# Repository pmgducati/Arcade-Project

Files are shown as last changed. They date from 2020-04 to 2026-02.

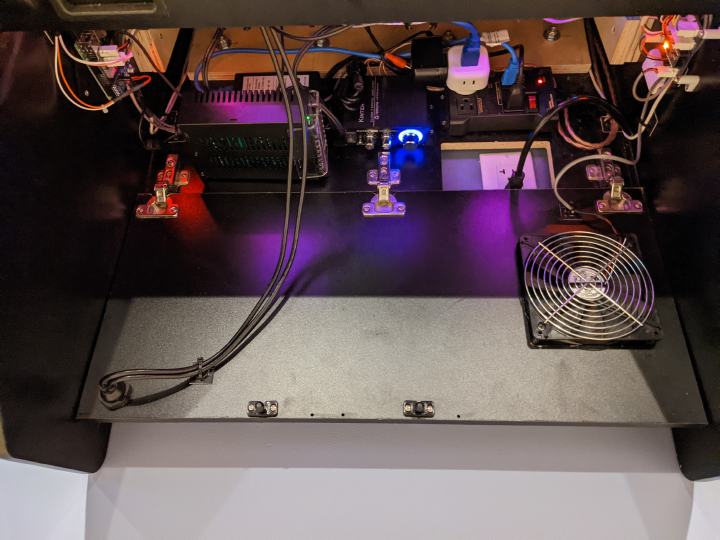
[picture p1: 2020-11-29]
Arcade Images/Access Door and Components.png

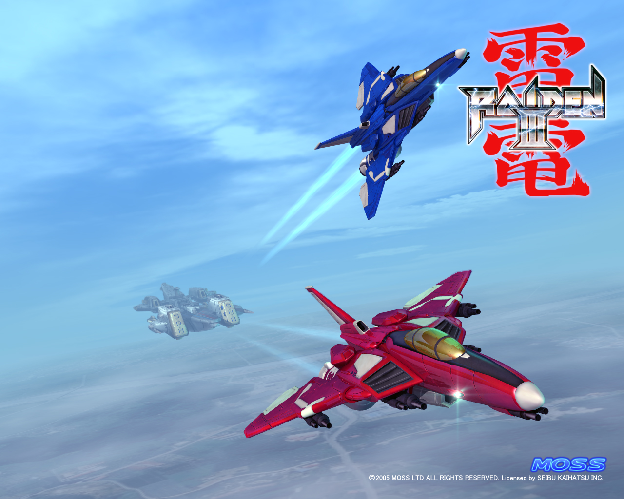
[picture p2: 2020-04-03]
Art for Inspiration/95.jpg

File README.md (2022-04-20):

# Arcade-Project
Building my Own Arcade

I have been working on some variation of an arcade cabinet that for some reason or another that never came to be... Until now!

I designed the cabinet in Solidworks and the PCBs in Eagle, I have included cultists, detailed drawings, BOM’s for purchased parts, datasheets, and pretty much any other info you would need to make the cabinet.  

I also generated STLs and Gerbers for anyone that doesn't have access to them fancy CAD programs.

Shout out to my friends Rob and Rufino for helping me out with the Artwork and CNC/wood working!



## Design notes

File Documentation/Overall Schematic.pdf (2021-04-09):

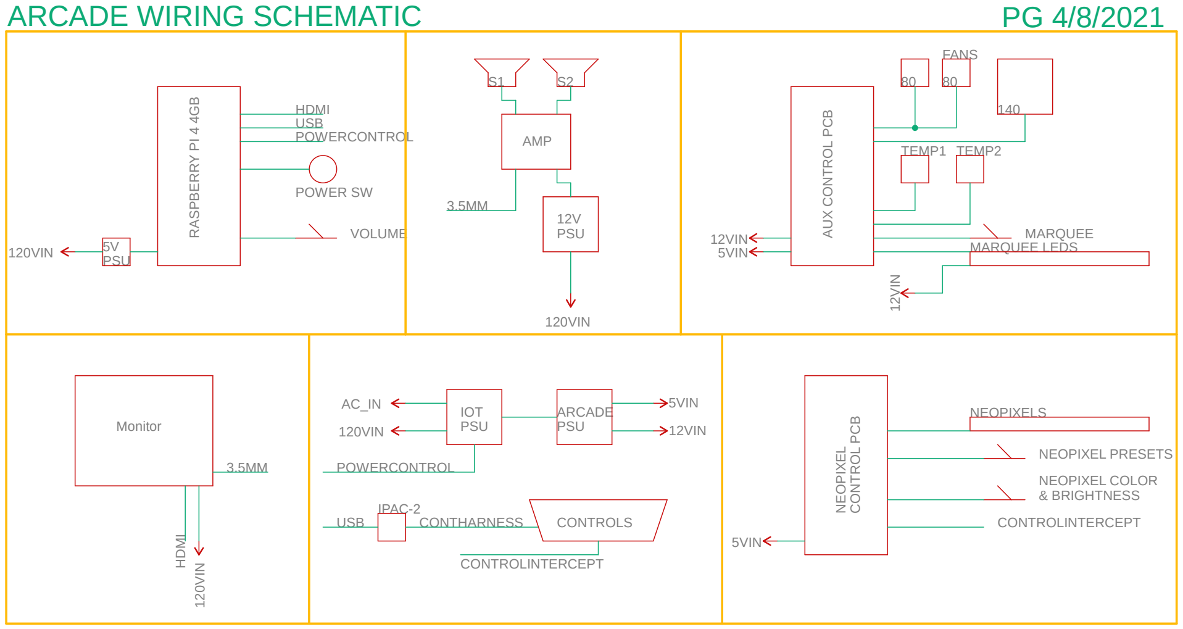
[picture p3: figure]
12VIN; 12VIN 5VIN; 5VIN; 120VIN; 120VIN 120VIN; Monitor; AMP; IOT; PSU RASPBERRY PI 4 4GB; NEOPIXEL COLOR & BRIGHTNESS; NEOPIXEL PRESETS; VOLUME; CONTROLS; IPAC-2; NEOPIXELS; POWER SW; 12V PSU; ARCADE PSU; TEMP1 TEMP2; FANS AUX CONTROL PCB; MARQUEE; MARQUEE LEDS NEOPIXEL CONTROL PCB; 5V PSU; POWERCONTROL; USB; CONTHARNESS; USB HDMI; HDMI; CONTROLINTERCEPT; ARCADE WIRING SCHEMATIC

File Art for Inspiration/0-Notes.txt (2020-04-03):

Observations:
-I like Konami Box Art (9,64-66,80-83)
-There is something cool about the 80's movie poster layout (1,2,12,50,51,106)
-Character "pile up" (19-21,45-46,89,98,99)
-8-bit/16-bit Pixel art always grabs me (18,23-24,27-29,32,43,85,88,90,96,97,100,101,103,104)
-Im a big fan of Ms Pacman :) (13)
-Iconic Art (To Me) (4-7, 8-9,23-24,29,32,41,43,45-46,50,52-63,72,76,82)
-Shoot em ups! (17,23-25,94-95)

Although I use alot of console art as a reference, I wan the art on the cabinet to be more abstract or arcade focused (no Nintendo/Sega etc)
I also want it to be less about a franchise and more about the experinece of playing 

Fonts I Like: 8,14,33 (alot for some reason),42 (side note if you have not played this game i HIGHLY remcommend it, great game to relax to!), 48,49,51,67,68,71,73,78,90,101 (The Word Ultra)

33,39 and 107 really speak to me for the respective decals,

The Vaporwave art is rad too 26,30,87  (I think the grid patter could be utilized well)

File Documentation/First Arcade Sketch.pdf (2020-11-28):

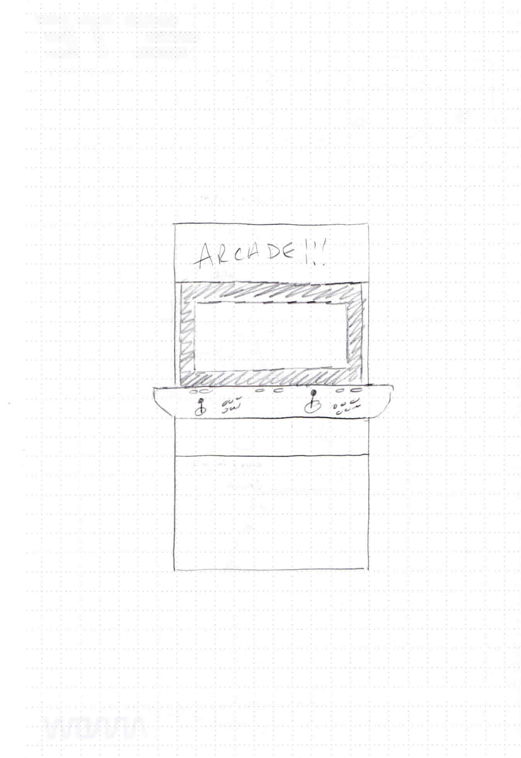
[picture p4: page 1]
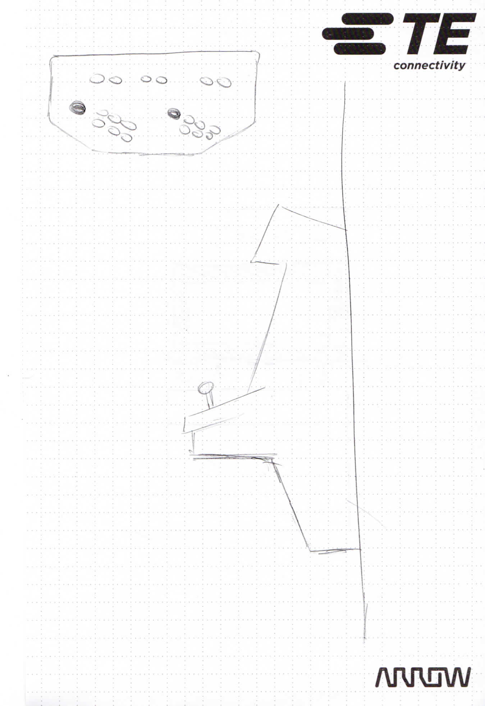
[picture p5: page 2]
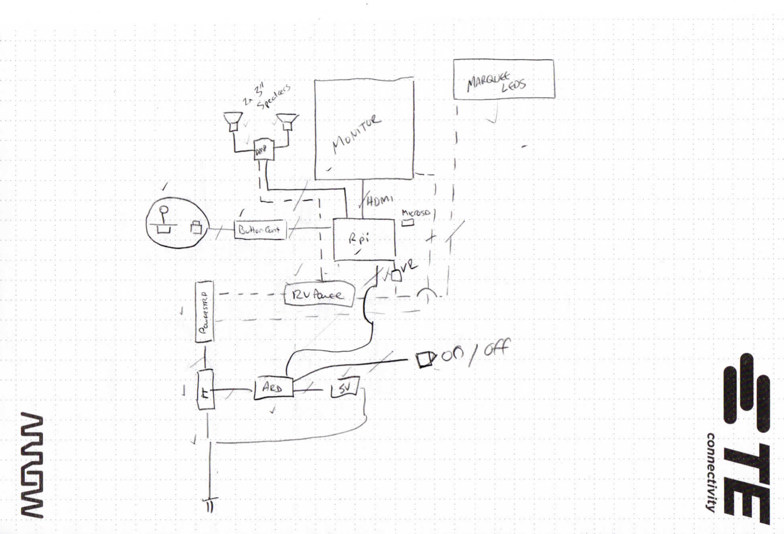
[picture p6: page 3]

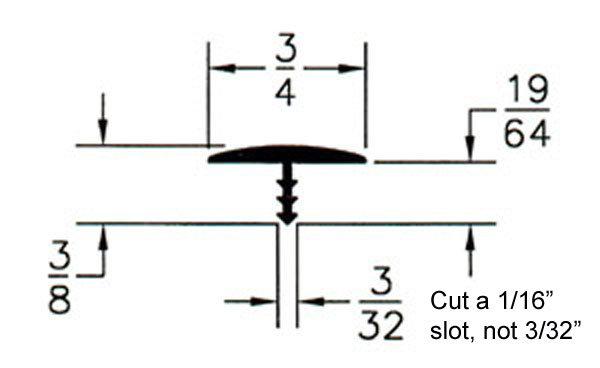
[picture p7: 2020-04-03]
DataSheets/T-Molding Specs.jpg

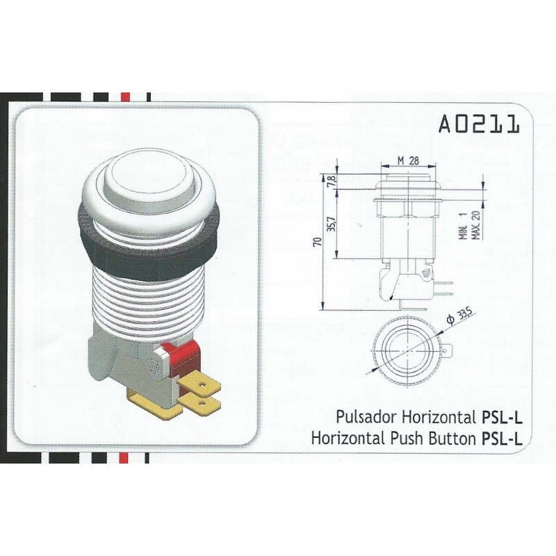
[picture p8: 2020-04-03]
DataSheets/iL PSL-L Concave Button Specs.jpg

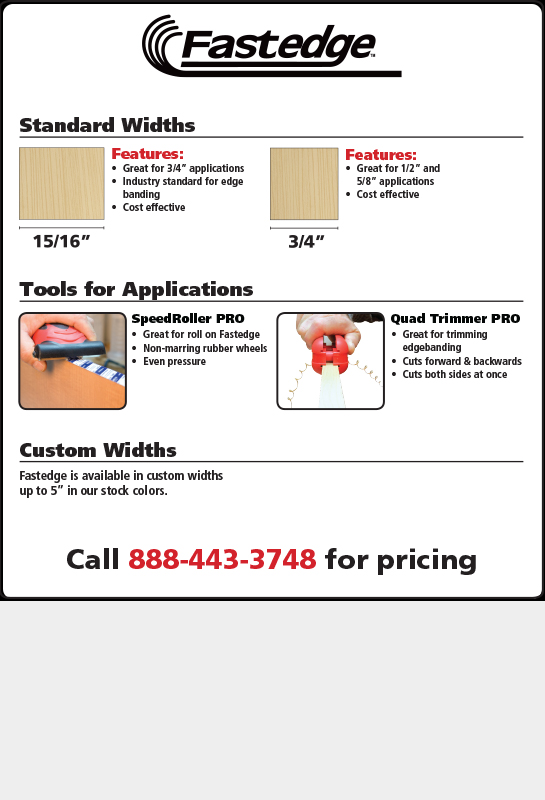
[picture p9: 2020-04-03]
DataSheets/Fastedge Edgebanding.jpg

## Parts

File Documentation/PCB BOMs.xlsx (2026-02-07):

AUX PCB BOM 12/9/2020
Qty | Value | Device | Package | Identifier | Description
4 |  | KK-156-2 |  | LOWERFAN/UPPERFAN/5VIN/12VIN | KK156 Header
5 |  | KK-156-3 |  | LOWERTEMP/UPPERTEMP/MARQUEE/SWITCHA/SWITCHB | KK156 Header
1 |  | KK-156-4 |  | 16x2 LCD SCREEN | KK156 Header
2 |  | IN4148 | DO35-7 | D1,D2 | Diode
2 |  | JZC-11F | JZC | K1,K2 | SPDT Electromechanical Relay
2 |  | NPN2222A | TO92 | T1,T2 | NPN Transistor
2 |  | 3POS ST H |  | INLINE WITH TEENSY | Stackable Headers
1 |  | TEENSY 3.2 |  | B1 | Teensy 3.2 | The Teensy 3.2 is End of Life, it has been replaced by the Teensy 4.0 (Drop in )
1 |  | TEENSY 3.2 |  | B1 | Teensy 3.4 | https://www.pjrc.com/store/teensy40.html
RPI MINI-HAT BOM 11/4/2020
QTY | Value | Device | Package | Identifier | Descriptoin
1 |  | FE06-2 |  | SV1 | 2x6 Female Header
1 |  | KK-156-2 |  | IOTPSU | KK156 Header
2 |  | KK-156-3 |  | SW1, SW2 | KK156 Header
SWITCHES PCB BOM 11/4/2020
QTY | Value | Device | Package | Identifier | Descriptoin
4 |  | ARCADESWITCH |  | U1, U2,U3,U4 | Arcade Switch (Pulled from old Reel to Reel)
4 |  | MA03-1 |  | SV1,SV2,SV3,SV4 | Male Header Pins 3 Positions
4 |  | Jumper |  | STACKS ON MA03-1 | Jumper
4 |  | KK-156-3 |  | SW1, SW2, SW3, SW4 | KK156 Header
NEOPIXEL PCB BOM 4/7/2021
QTY | Value | Device | Package | Identifier | Descriptoin
2 |  | KK-156-8 |  | PLAYER1IN,PLAYER2IN | KK156 Header
2 |  | KK-156-2 |  | 5VIN, GND | KK156 Header
4 |  | KK-156-3 |  | OPT, NEOPIXEL, SW1, SW2 | KK156 Header
1 |  | KK-156-4 |  | MICROPHONE | KK156 Header
1 |  | MA04-1 |  | X1 | Pin Header
6 | 10K | Res 1206 10K | R1206 | R2-R7 | Resistor
1 | 470 Ohm | Res 1206 470 | R1206 | R1 | Resistor
1 | 4700uF | Cap Elec TH | E5-13 | C1 | Polarized Capacitor
1 |  | Jumper |  | STACKS ON MA04-1 | Jumper
2 |  | 3POS ST H |  | INLINE WITH TEENSY | Stackable Headers
1 |  | Teensy 3.2 |  | B1 | Teensy 3.2 | The Teensy 3.2 is End of Life, it has been replaced by the Teensy 4.0 (Drop in )
1 |  | TEENSY 3.2 |  | B1 | Teensy 3.4 | https://www.pjrc.com/store/teensy40.html
NEOPIXEL DEVLOPMENT PCB BOM 4/7/2021
QTY | Value | Device | Package | Identifier | Descriptoin
1 |  | BARLJK |  | J1 | 2.1MM Barrel Jack
1 |  | HDPHJK |  | J2 | 3.5MM Headphone Jack
1 | 4700uF | Cap Elec TH | E5-13 | C2 | Polarized Capacitor
2 | 10uF | Cap Elec TH | E2-4 | C4,C5 | Polarized Capacitor
7 | 10K | Res 1206 10K | R1206 | R2,R9-R14 | Resistor
1 | 470 Ohm | Res 1206 470 | R1206 | R8 | Resistor
1 | 2.2K | Res 1206 1K | R1206 | R3 | Resistor
1 | 47K | Res 1206 470 | R1206 | R1,R4 | Resistor
2 |  | MA03-1 |  | STMN,SV1,SV3 | Male Header Pins 3 Positions
1 |  | MA04-1 |  | GAIN | Male Header Pins 4 Positions
1 |  | KK-156-4 |  | MICROPHONE | KK156 Header
19 |  | MON ON-OFF |  | S01 - S19 | Momentary Switch On-Off
4 |  | MON OFF-ON |  | S20 - S23 | Momentary Switch Off-On
19 |  | NeoPix |  |  | Neopixel String Cut into 5x @ 3 and 2x @ 2
1 |  | Jumper |  | STACKS ON MA04-1 | Jumper
2 |  | 3POS ST H |  | INLINE WITH TEENSY | Stackable Headers
1 |  | TEENSY 3.2 |  | B1 | Teensy 3.2 | The Teensy 3.2 is End of Life, it has been replaced by the Teensy 4.0 (Drop in )
1 |  | TEENSY 3.2 |  | B1 | Teensy 3.4 | https://www.pjrc.com/store/teensy40.html
3.5MM INPUT ADAPTER PCB BOM 4/7/2021
QTY | Value | Device | Package | Identifier | Descriptoin
1 |  | KK-156-4 |  | J2 | KK156 Header
2 |  | MA03-1 |  | STMN | Male Header Pins 3 Positions
7 | 10K | Res 1206 10K | R1206 | R2 | Resistor
2 | 10uF | Cap Elec TH | E2-4 | C4,C5 | Polarized Capacitor
1 | 2.2K | Res 1206 1K | R1206 | R3 | Resistor
1 | 47K | Res 1206 470 | R1206 | R1,R4 | Resistor
1 |  | HDPHJK |  | J2 | 3.5MM Headphone Jack
ST POWER PCB BOM 12/27/2021
QTY | Value | Device | Package | Identifier | Descriptoin
1 |  | TACT-PANA-EVQ |  | POWERSW | Power Switch Momentart Button
1 |  | JZC-11F | JZC | K1 | SDPT RELAY-JZC
1 | 10K | Res 1206 10K | R1206 | R3 | Resistor
1 |  | NPN2222A | 2N5088 | T1 | NPN TRANSISTOR
1 |  | ESP32DEVKITC | ESP32DEVKITC | U1 | ESP32 Devkit
2 | 330 | Res 1206 330 | R1206 | R1,R2 | Resistor
1 |  | 1N4148 | Diode 1N4148 | D1 | Diode
2 |  | Red LED | 1206 | PWR,WIFI | CHIPLED_1206
2 |  | KK-156-2 |  | 5VIN, GND | KK156 Header

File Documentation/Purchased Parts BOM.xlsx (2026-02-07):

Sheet: Parts and Materials
Qty | Part # | Description | Purchased | DataSheet
1 | One Day Glass | .25" Thick Smoke Gray Tempered Glass | One Day Glass
50 | E1032S-41-50-ND | Wire 2 Conductor | Digikey | X
50 | E3033S-50-ND | Wire 3 Conductor | Digikey | X
25 | E2104S.41.02 | Wire 4 Conductor | Digikey | X
19 | 4356 | Neopixel Mini Button | Adafruit | X
2 | AM2302 | Wired DHT22 temperature-humidity sensor | Adafruit | X
1 | G-3140MM | 140mm Fan Grill | Amazon
1 | 8541607606 | 140mm PVC Black PC Cooler Fan Dust Filter | Amazon
1 | 4330172261 | 3-1/2inches Black Color Mesh Speaker Grill (Pair) | Amazon
2 | B0014WZEQI | 80mm Fan Grill | Amazon
1 | VN279Q | Asus 27" Monitor | Amazon
1 | Iot Relay | Dataloggers IoT Relay | Amazon | X
1 | usb-dual-port | Cabinet Mount Dual USB 3.0 Port | T-Molding.com
1 | 43DSC3504 | Kicker 3.5-Inch 30W 2-Way Speakers (Pair) | Amazon
1 | K2020A+ | Kinter Tripath TA2020-020 Class-T Mini Amplifier | Amazon
1 | LI121425QE-4-A | Lian Li 140mm PC Fan | Amazon
1 | MH-16A | RetroArcade 16A Arcade Switching Power Supply, 133 Watt | Amazon | x
2 | EE80251S2-000U-999 | Sunon 80mm PC Fan | Amazon
4 | 5V-DIMMABLE | White LEDs for Marquee 2' strips 5V Dimmable (3 Pin, PWM controlled) | Amazon
1 | USBAMB1MU | USB 2.0 A MALE TO MINI B RIGHT ANGLE UP | Amazon | X
10 | 52929-1 | CONN SPADE TERM 16-22AWG #6 RED | Digikey | X
2 | 9508080 | Molex 8 Position Rectangular Housing Connector | Digikey | X
14 | 9508021 | Molex 2 Position Rectangular Housing Connector | Digikey | X
15 | 9508031 | Molex 3 Position Rectangular Housing Connector | Digikey | X
4 | 9508041 | Molex 4 Position Rectangular Housing Connector | Digikey | X
91 | 8500106 | Molex Non-Gendered Contact Tin 18-24 AWG Crimp | Digikey | X
1 | KFB2ANA1BBB | Power Switch | Digikey | X
1 | NA | Grapic Decal Set (Side Art, Marquee, Control Panel and Bezel) | GameonGrafix
8 | 232-9718 | 3/8" Lock Nuts | Menards
8 | 232-4069 | 3/8" Washers | Menards
8 | 232-5061 | 3/8" x 2 1/2" Hex Bolt | Menards
1 | MEL3_449Black | Dakota™ 3/4 x 49 x 97 Melamine Panel | Menards
1 | MEL5_849black | Dakota™ 5/8 x 49 x 97 Melamine Panel | Menards
1 | 5597 | Monoprice 3ft 3.5mm Stereo Male to 2 RCA | Monoprice
1 | 3992 | Monoprice 4' HDMI Cable | Monoprice
1 | B08HLSFN8Z | TESSAN Multi Plug Outlet Extender | Amazon
1 | FBA_VP-2P8L-WJN7 | C4 Labs Zebra VESA Mounting Plate - (Black) | Amazon
2 | 7233 | RCA Plug to RCA Jack Adapter, Gold Plated (Right Angle) | Monoprice
1 | 33560 | Power Cord - NEMA 5-15P to IEC 60320 C13, 18AWG, 10A/1250W, 125V, 3-Prong, 2ft | Monoprice
1 | 33566 | Monoprice Power Cord - NEMA 5-15P to IEC 60320 C13, 18AWG, 10A/1250W, 125V, 3-Prong, 3ft | Monoprice
3 | MC-37/BLK-1 | Sugatsune 1-5/16" Long Black ABS Non-Magnetic Touch Latch | Outwater Plastics | X | These parts are end of life, a replacemnt needs to be identified
3 | 230-U26/0T | Sugatsune Concelaed Hinge | Outwater Plastics | X
3 | 230-P4W-32T | Sugatsune Mounting Plate | Outwater Plastics | X
25 | TAP3515NI | Sugatsune Screw For Mounting Plate | Outwater Plastics | X
3 | D44X | Cherry Pushbutton Microswitch | Paradise Arcade | X
2 | A03441 | iL Eurojoystick Dark Gray | Paradise Arcade | X
2 | iL-PSL-L-K | iL PSL-L Concave Button - Black - Microswitch : 75 Gram Cherry Microswitch | Paradise Arcade | X
1 | 3221386 | iL PSL-L Concave Button - Clear White - Player 1 - Microswitch : 125 Gram Microswitch | Paradise Arcade | X
1 | 3221386 | iL PSL-L Concave Button - Clear White - Player 2 - Microswitch : 125 Gram Microswitch | Paradise Arcade | X
6 | 2751150 | iL PSL-L Concave Button - Translucent White - Microswitch : 125 Gram Microswitch | Paradise Arcade | X
12 | 2751148 | iL PSL-L Concave Button - Translucent White - Microswitch : 75 Gram Cherry Microswitch | Paradise Arcade | X
1 | IPAC-2 | I-PAC 2 INTERFACE | Paradise Arcade | X
1 | FE-BLA-94-50 | 15/16" Black Peel & Stick Edgebanding - 50ft Roll | T-Molding.com | X
3 | Wire-Kit-2P | 2 Player Wiring Kit | T-Molding.com
1 | FE-BLA-75-50 | 3/4" Black Peel & Stick Edgebanding - 50ft Roll | T-Molding.com | X
80 | T-BLA-75 | 3/4" Black T-Molding | T-Molding.com | X
2 | JS-Mounting-Hidden-3/4 | Hidden Hardware Joystick Mounting Kit | T-Molding.com
3 | PCB-Feet-12 | PCB Feet With Screws - 12 Pack | T-Molding.com
2 | CA-KN3D-123 | Momentary Toggle Switch 12V 25A SPDT (ON)/Off/(ON) 3 pin (https://www.amazon.com/dp/B093G9XTK7?ref=ppx_yo2ov_dt_b_fed_asin_title&th=1) | Amazon |  | 2-6-26 - Added this item to work with the 3D printed 2 switch version
1 | 9315MDKEU | mDesign Modern Plastic Adhesive Cabinet and Wall Mount Storage Organizer Bin | Amazon
 |  | Raspberry Pi Parts
1 | B07TYQRXTK | CanaKit 3.5A Raspberry Pi 4 Power Supply (USB-C) | Amazon
1 | Powerblock | Powerblock (Pi4) USB-C Version | PetrockBlog | X
1 | Pi4 4Gb | Raspberry Pi 4 4Gb | Amazon
1 | B088HCY4TH | Geekworm Raspberry Pi 4 X862 M.2 NGFF SATA SSD Storage Expansion Board | Amazon
1 | 8541602182 | Wathai Blue 100x100x2mm 2mm Silicone Pad Thermal Conductivity 1.5 W/mk | Amazon
1 | AS5-3.5G | Arctic Silver 5 AS5-3.5G Thermal Paste | Amazon
1 | B07ZV1LLWK | GeeekPi Raspberry Pi 4 Fan, Raspberry Pi Low-Profile CPU Cooler | Amazon
1 | NF-A4x10 5V | Noctua NF-A4x10 5V, Premium Quiet Fan, 3-Pin, 5V Version | Amazon
1 | FBA_VP-2P8L-WJN7 | C4 Labs Zebra VESA Mounting Plate - (Black) | Amazon
 |  | Custom Parts
1 | NA | Custom Bent Acrylic Power Supply Terminal Cover | NA
1 | Switch Mount | Switch Mount (Custom 3D Print) | Shapeways
1 | LCD Mount | Mount for Aux Control PCB Support LCD | Shapeways

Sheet: Tools
Qty | Part # | Description | Purchased
1 | -- | IL Button Wrench | Paradise Arcade
1 | PLIERS-FLUSHCUT | FastCap Flush Cut Trimmer | T-Molding.com
1 | MOLDING-CUTTER | Molding Cutter | T-Molding.com
1 | SpeedRollerPRO | SpeedRoller Pro | T-Molding.com
1 | QUAD-EDGE-TRIMMER | Quad Edge Trimmer | T-Molding.com
1 | ARBOR-A200B-025 | Whiteside Slotting Cutter Arbor 1/4" Shank | T-Molding.com
1 | 3WNG-6700A-116 | Whiteside Slotting Cutter 1/16" 3-Wing | T-Molding.com
1 | RUBBER-MALLET | 1lb Fiberglass Handle Rubber Mallet | T-Molding.com
1 | FB.180GRIT.10PC | 180 Grit Sandpaper | FastCap
1 | FASTBREAK | FastBreak Sander | FastCap

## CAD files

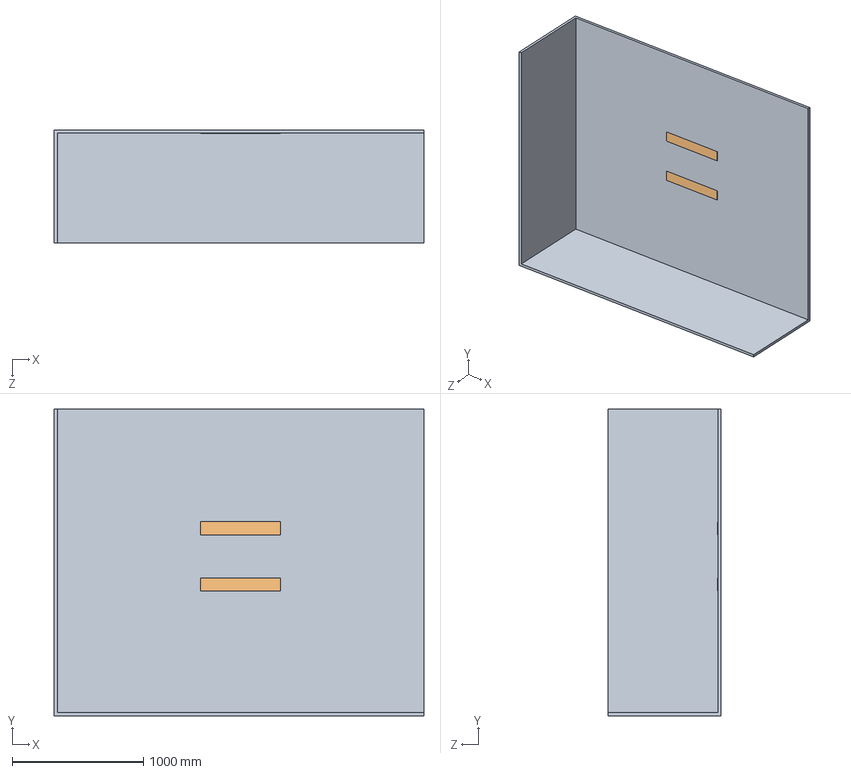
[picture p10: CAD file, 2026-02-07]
CAD Files/Arcade.SLDASM
2819.4 x 2336.8 x 863.6 mm
Cleat x 2
Wall

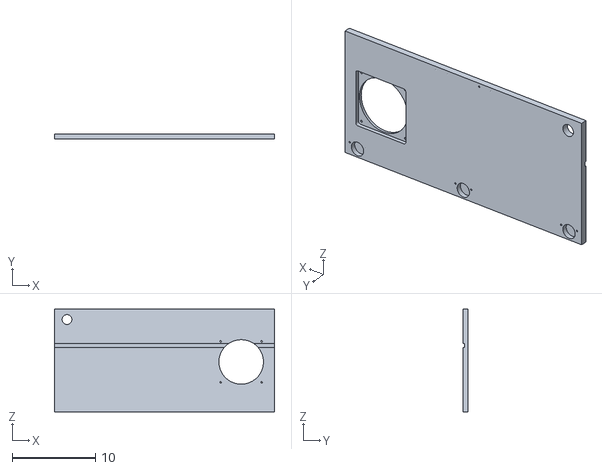
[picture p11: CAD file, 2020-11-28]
STLs and Gerbers/STL R1 for CNC (Manufactured)/Maintanence Door R1.STL
26.4 x 0.625 x 12.3

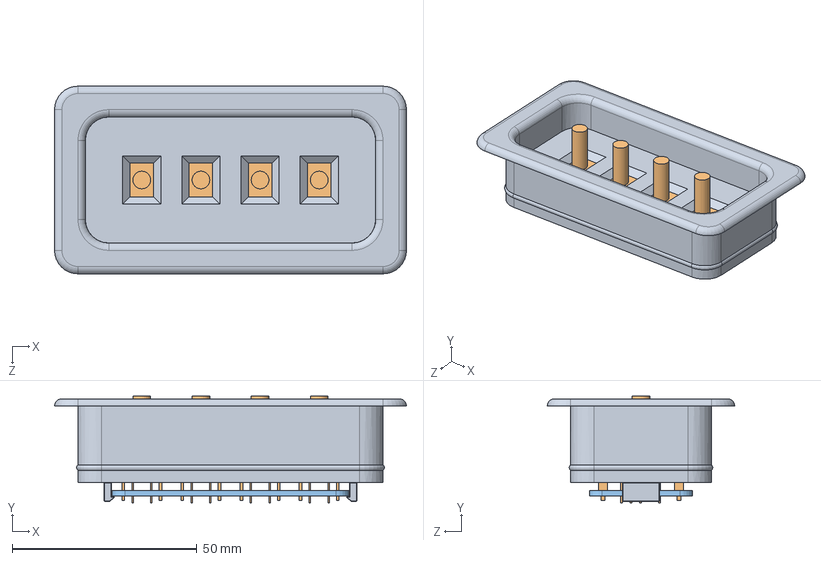
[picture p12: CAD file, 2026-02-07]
CAD Files/Switch Assembly.SLDASM
95.2 x 28.8 x 50.8 mm
switch plate
Switch x 4
PCB

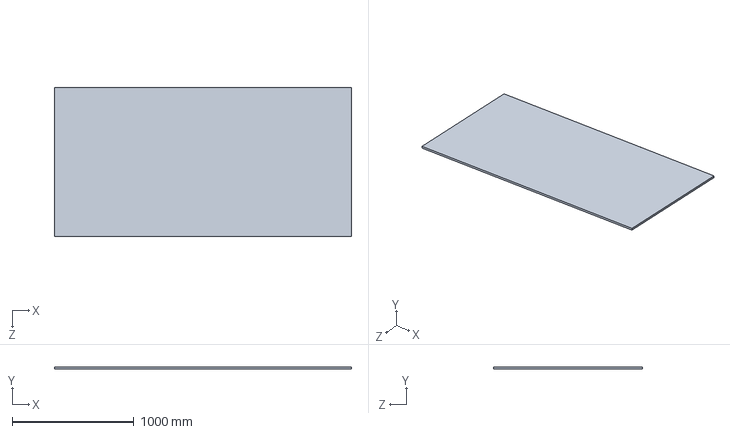
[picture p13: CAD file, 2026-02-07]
CAD Files/Panel.SLDASM
2438.4 x 19.1 x 1219.2 mm

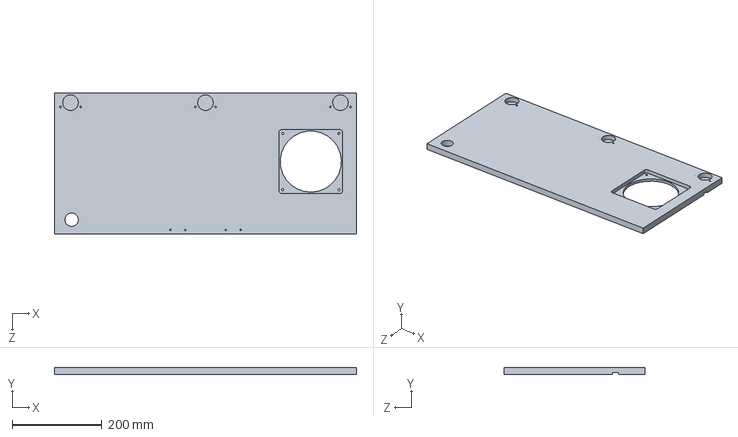
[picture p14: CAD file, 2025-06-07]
CAD Files/Maintanence Door.SLDPRT
671.3 x 15.9 x 313.4 mm

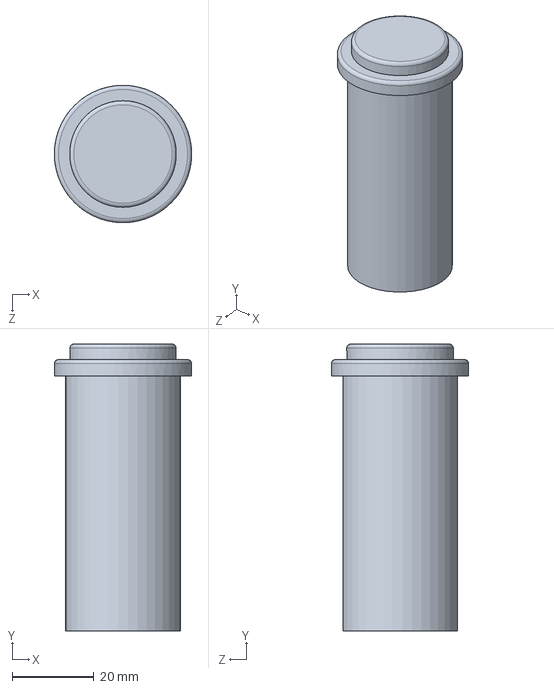
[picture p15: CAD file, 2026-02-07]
CAD Files/Purchased Parts/Button.SLDPRT
33.5 x 70.0 x 33.5 mm

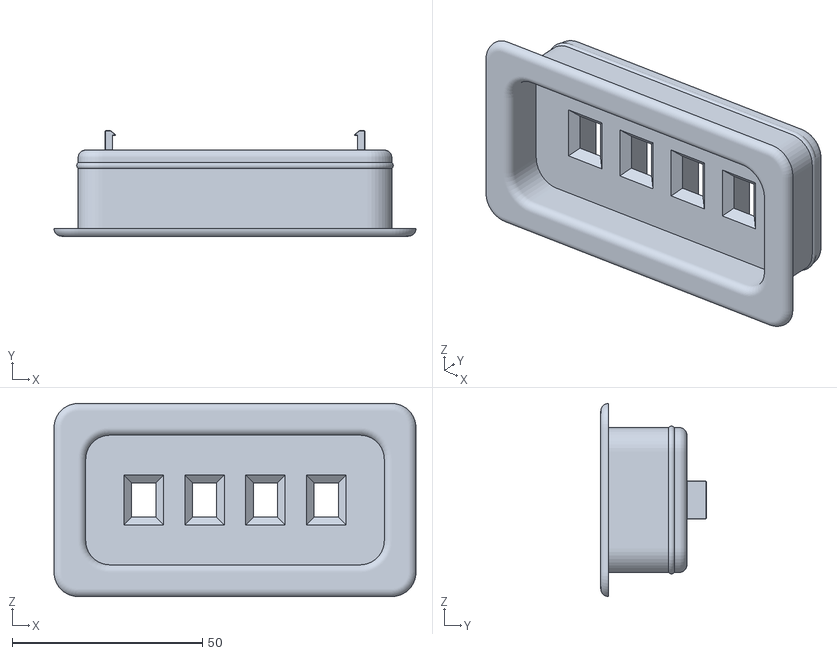
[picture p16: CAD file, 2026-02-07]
STLs and Gerbers/STL R2 (Updated)/3D Printing/4X Panel Mount Switch Plate.STL
95.2 x 27.8 x 50.8

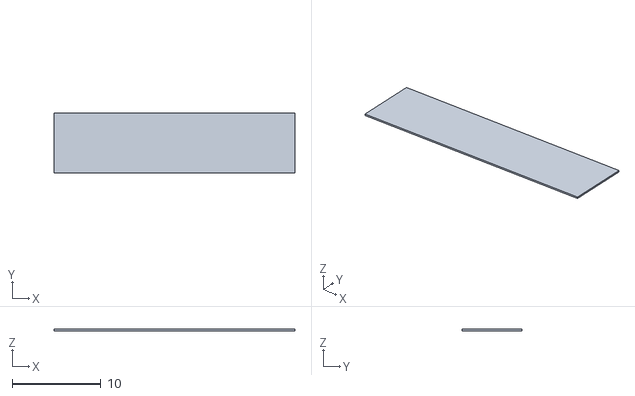
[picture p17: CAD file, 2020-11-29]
STLs and Gerbers/STL R2 (Updated)/STL for Plexi/Marquee Plexi.STL
27.1 x 6.78 x 0.17

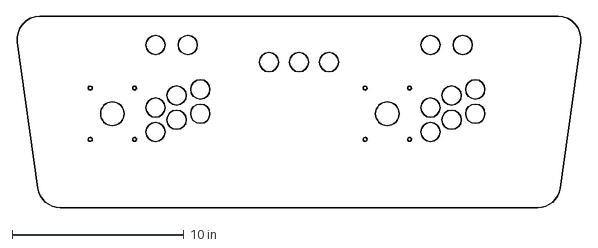
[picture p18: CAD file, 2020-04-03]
Art for Inspiration/AI Files/Decal Control Panel - REV A.DXF
32.9 x 11.1 in

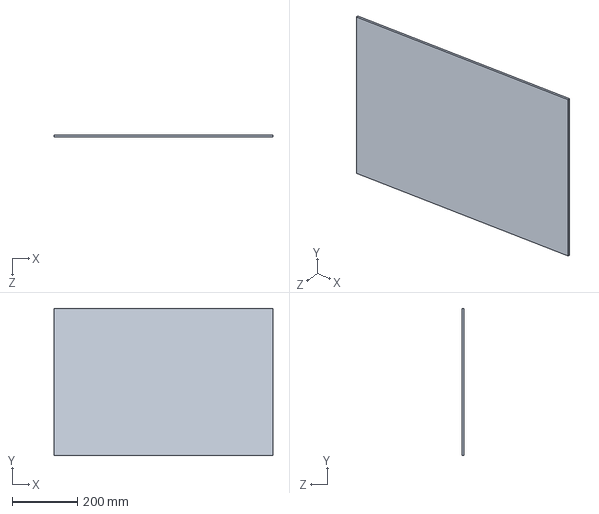
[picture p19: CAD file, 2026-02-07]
CAD Files/Monitor Bezel.SLDPRT
671.5 x 450.9 x 6.00 mm

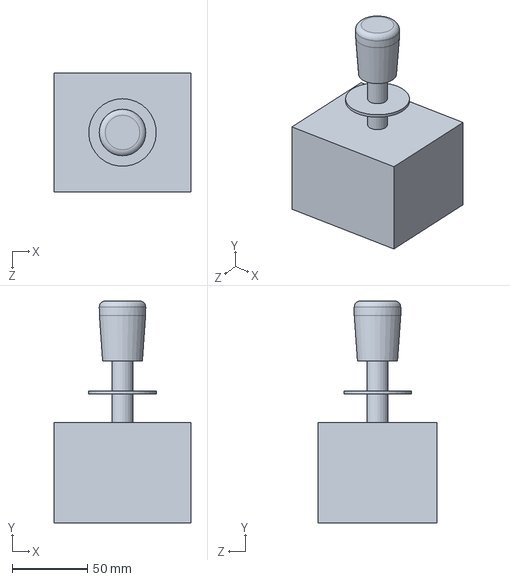
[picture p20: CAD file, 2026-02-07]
CAD Files/Purchased Parts/Joystick.SLDPRT
91.0 x 147.8 x 79.0 mm

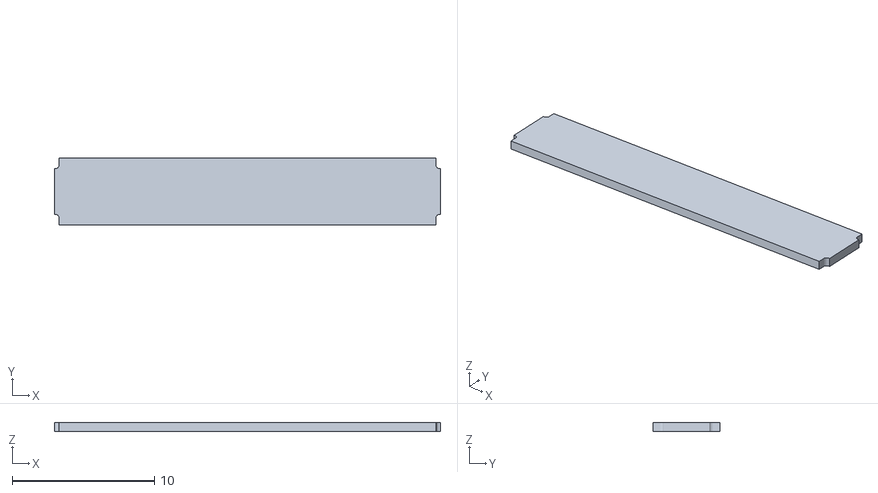
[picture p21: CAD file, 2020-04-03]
STLs and Gerbers/STL R1 for CNC (Manufactured)/Front Panel.STL
27.1 x 4.71 x 0.625

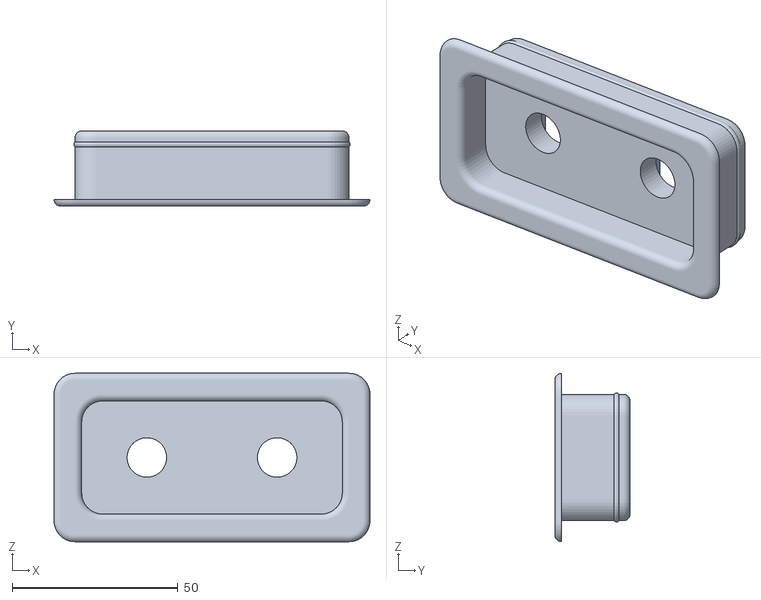
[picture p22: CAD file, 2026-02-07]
STLs and Gerbers/STL R2 (Updated)/3D Printing/2X Panel Mount Switch Plate.STL
95.2 x 22.7 x 50.8

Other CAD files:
STLs and Gerbers/STL R2 (Updated)/Maintanence Door.STL
Art for Inspiration/AI Files/Decal Sides - Right - REV A.DXF
CAD Files/Reference Parts/Wall.SLDPRT
STLs and Gerbers/STL R2 (Updated)/Side - Left.DXF
CAD Files/Reference Parts/4x8.SLDPRT
Art for Inspiration/AI Files/Decal Bezel.DXF
Art for Inspiration/AI Files/Decal Control Panel - NOHOLES.DXF
Art for Inspiration/AI Files/Decal Marquee.DXF
Art for Inspiration/AI Files/Decal Sides - Left - REV A.DXF
Art for Inspiration/AI Files/OLD/Decal Control Panel.DXF
Art for Inspiration/AI Files/OLD/Decal Sides - Left.DXF
Art for Inspiration/AI Files/OLD/Decal Sides - Right.DXF
CAD Files/1 to 1 Control Panel.SLDDRW
CAD Files/2X Panel Mount Switch Plate.SLDPRT
CAD Files/Arcade.SLDDRW
CAD Files/Back.SLDPRT
CAD Files/Bottom Lip.SLDPRT
CAD Files/Cleat.SLDPRT
CAD Files/Control Panel Layouts.SLDDRW
CAD Files/Control Panel.SLDPRT
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

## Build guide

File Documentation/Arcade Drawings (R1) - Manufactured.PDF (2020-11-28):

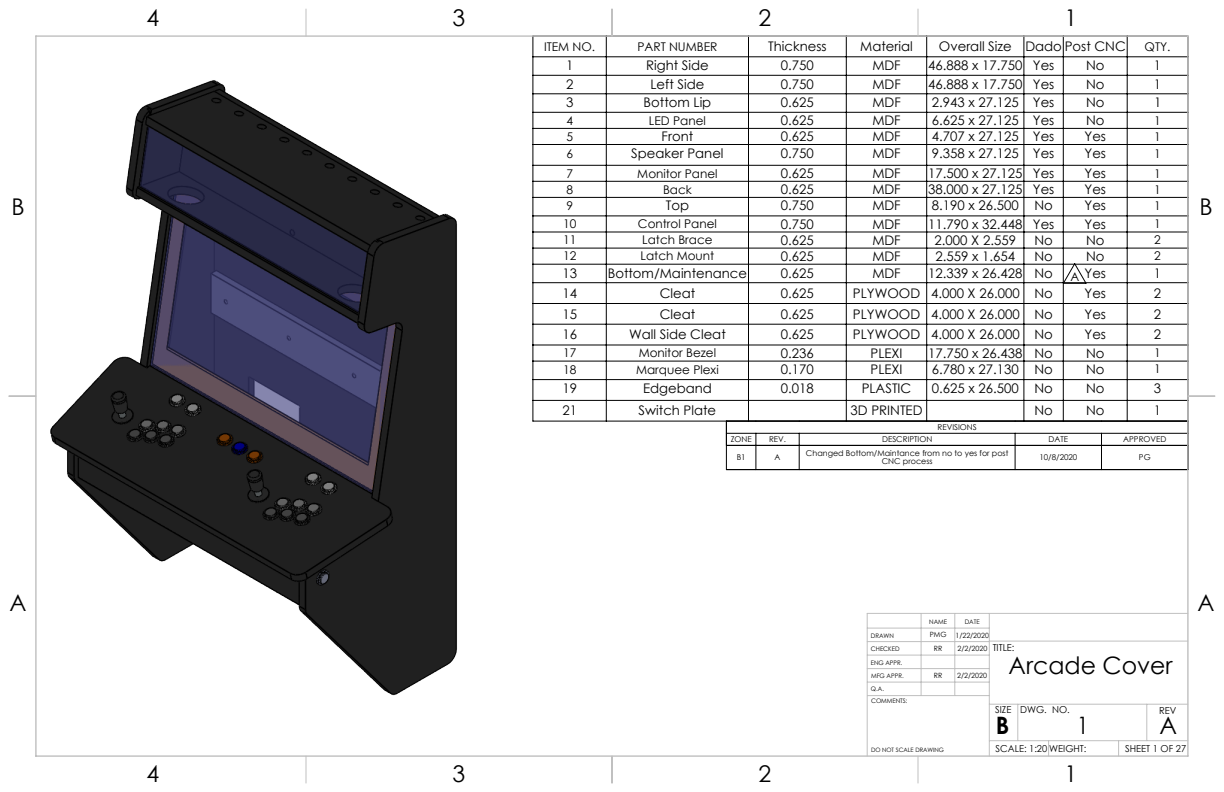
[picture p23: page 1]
ITEM NO.; PART NUMBER; Thickness; Material; Overall Size Dado Post CNC QTY.; Right Side; MDF; 46.888 x 17.750 Yes; Left Side; Bottom Lip; 2.943 x 27.125 Yes; LED Panel; 6.625 x 27.125 Yes; Front; 4.707 x 27.125 Yes; Yes; Speaker Panel; 9.358 x 27.125 Yes; Monitor Panel; 17.500 x 27.125 Yes; Back; 38.000 x 27.125 Yes; Top; Control Panel; 11.790 x 32.448 Yes; Latch Brace; Latch Mount; Bottom/Maintenance; Cleat; PLYWOOD 4.000 X 26.000 No; Wall Side Cleat; Monitor Bezel; PLEXI; Marquee Plexi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

ZONE | REV. | DESCRIPTION | DATE | APPROVED
B1 | A | Changed Bottom/Maintance from no to yes for post CNC process | 10/8/2020 | PG

NAME | DATE
CHECKED | RR | 2/2/2020 | TITLE: Arcade Cover

DRAWN | PMG | 1/22/2020

ENG APPR.
MFG APPR. | RR | 2/2/2020
Q.A.

SIZE B | DWG. NO. 1 | REV A

DO NOT SCALE DRAWING

SCALE: 1:20 WEIGHT: | | SHEET 1 OF 27

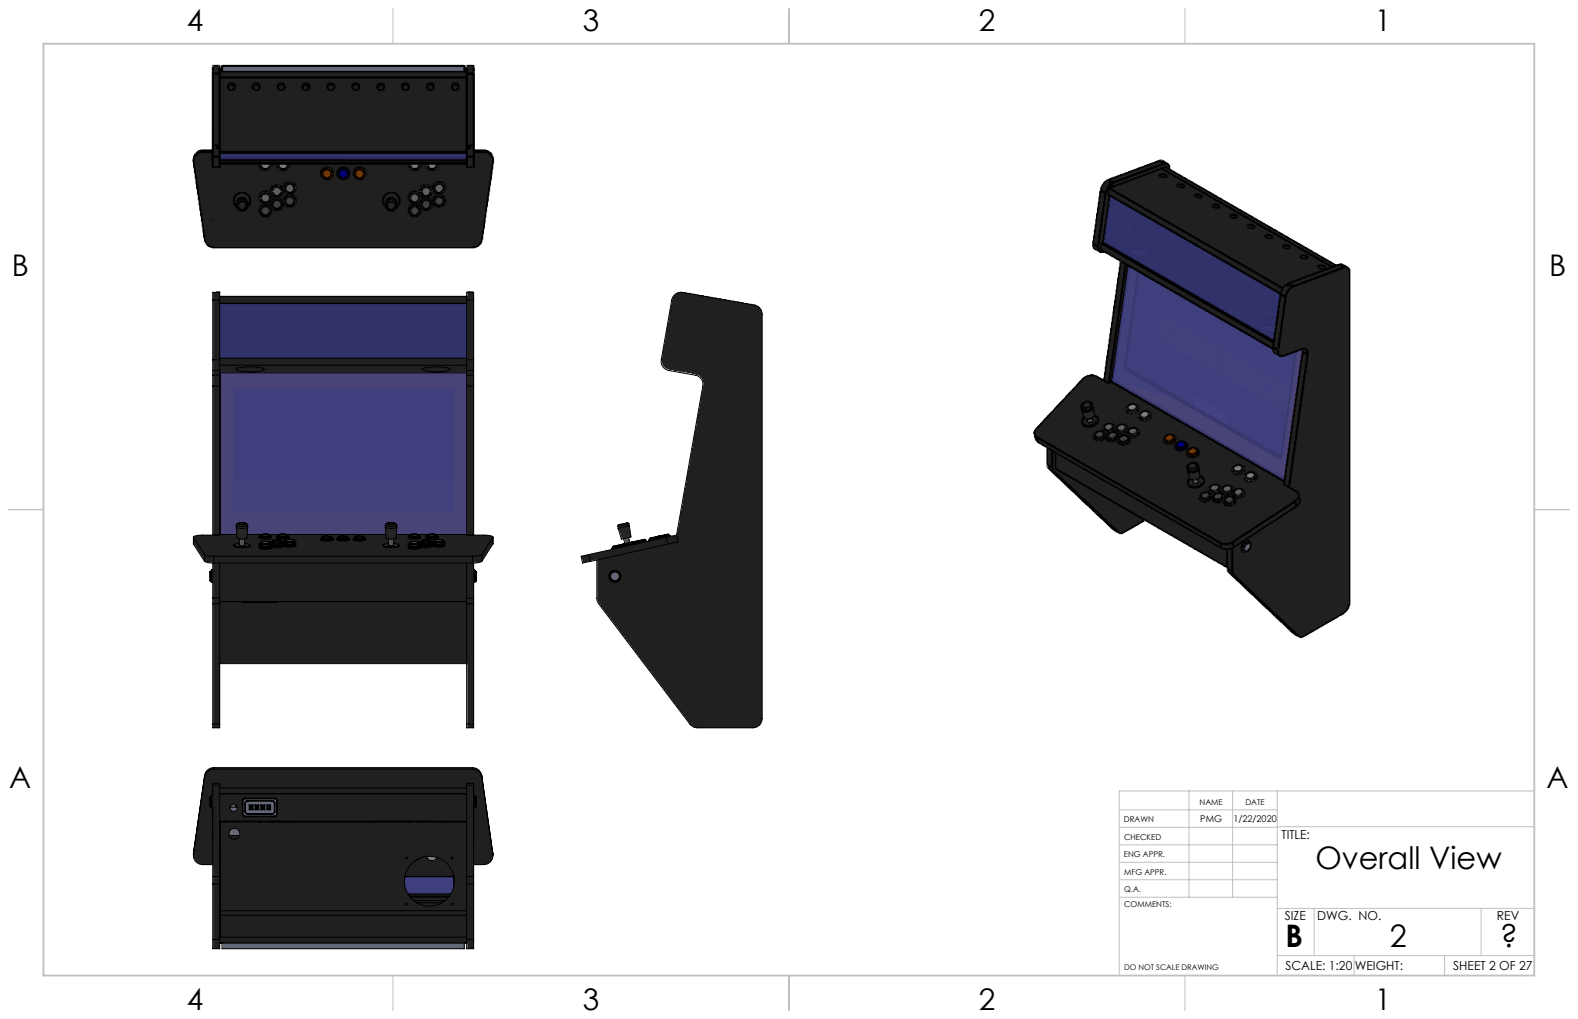
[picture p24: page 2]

NAME | DATE
CHECKED | | | TITLE: Overall View

DRAWN | PMG | 1/22/2020

ENG APPR.
MFG APPR.
Q.A.

SIZE B | DWG. NO. 2 | REV ?

SCALE: 1:20 WEIGHT:

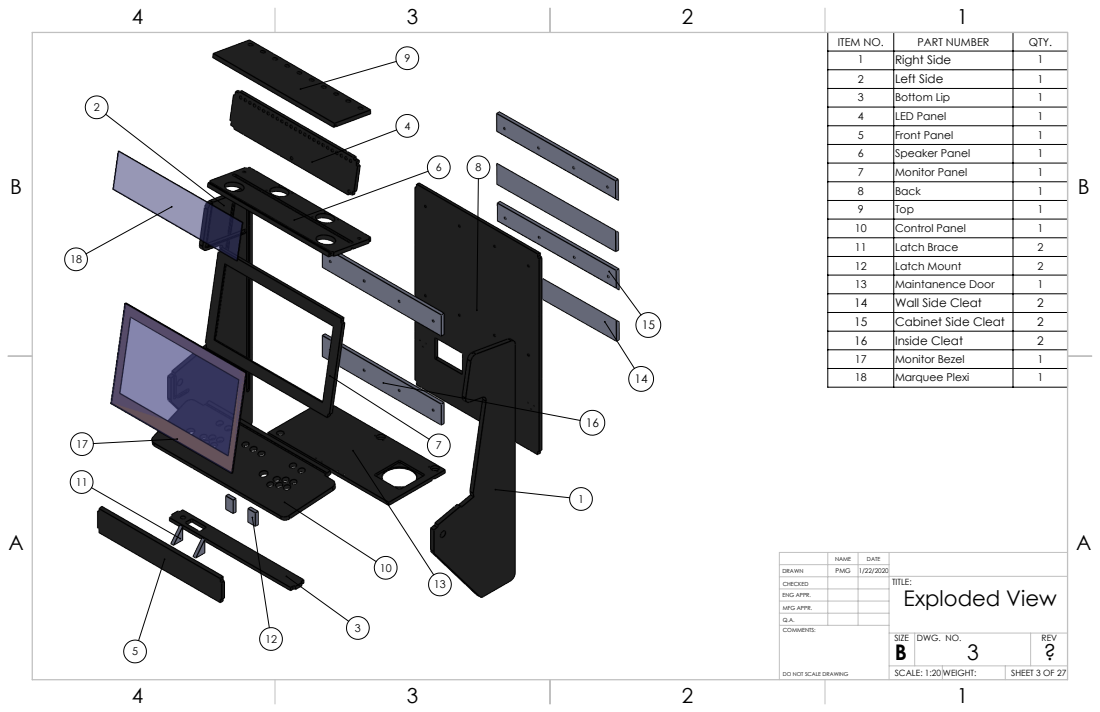
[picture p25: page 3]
ITEM NO.; PART NUMBER; QTY. 1; Right Side; Left Side; Bottom Lip; LED Panel; Front Panel; Speaker Panel; Monitor Panel; Back; Top

10 | Control Panel | 1
11 | Latch Brace | 2
12 | Latch Mount | 2
13 | Maintanence Door | 1
14 | Wall Side Cleat | 2
15 | Cabinet Side Cleat | 2
16 | Inside Cleat | 2
17 | Monitor Bezel | 1
18 | Marquee Plexi | 1

NAME | DATE
CHECKED | | | TITLE: Exploded View?

DRAWN | PMG | 1/22/2020

ENG APPR.
MFG APPR.
Q.A.

SIZE B | DWG. NO. 3 | REV

SCALE: 1:20 WEIGHT:

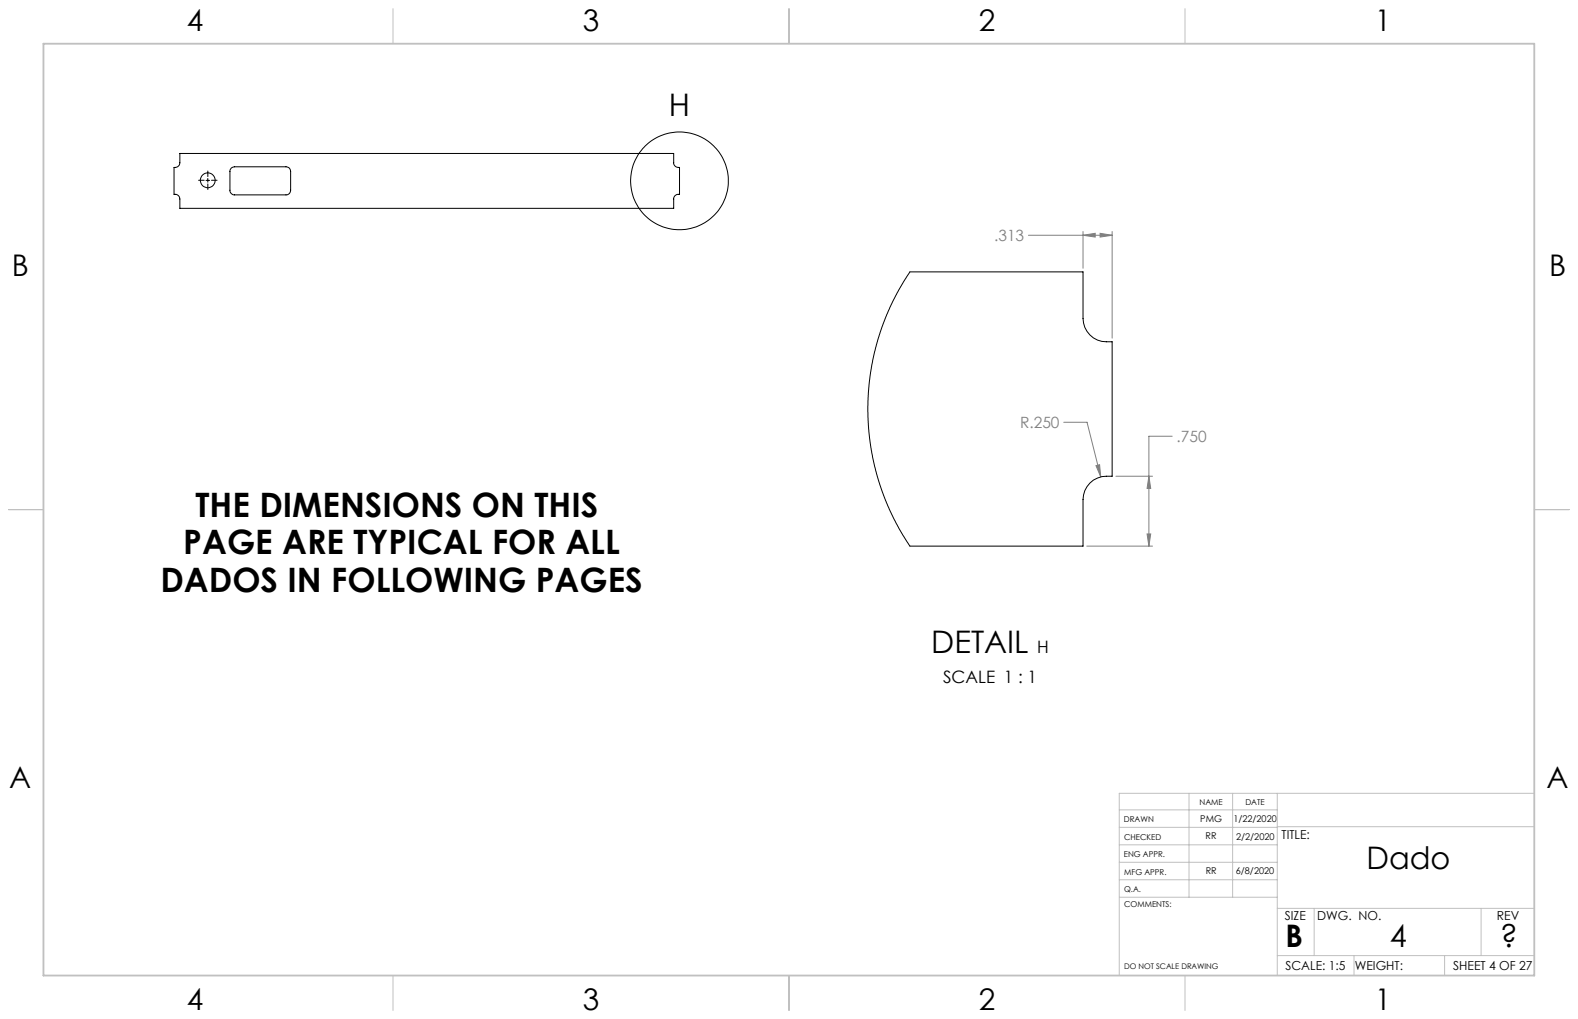
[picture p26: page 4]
DETAIL H; SCALE 1 : 1

THE DIMENSIONS ON THIS
PAGE ARE TYPICAL FOR ALL
DADOS IN FOLLOWING PAGES

NAME | DATE
CHECKED | RR | 2/2/2020 | TITLE: Dado

DRAWN | PMG | 1/22/2020

ENG APPR.
MFG APPR. | RR | 6/8/2020
Q.A.

SIZE B | DWG. NO. 4 | REV ?

SCALE: 1:5 | WEIGHT:

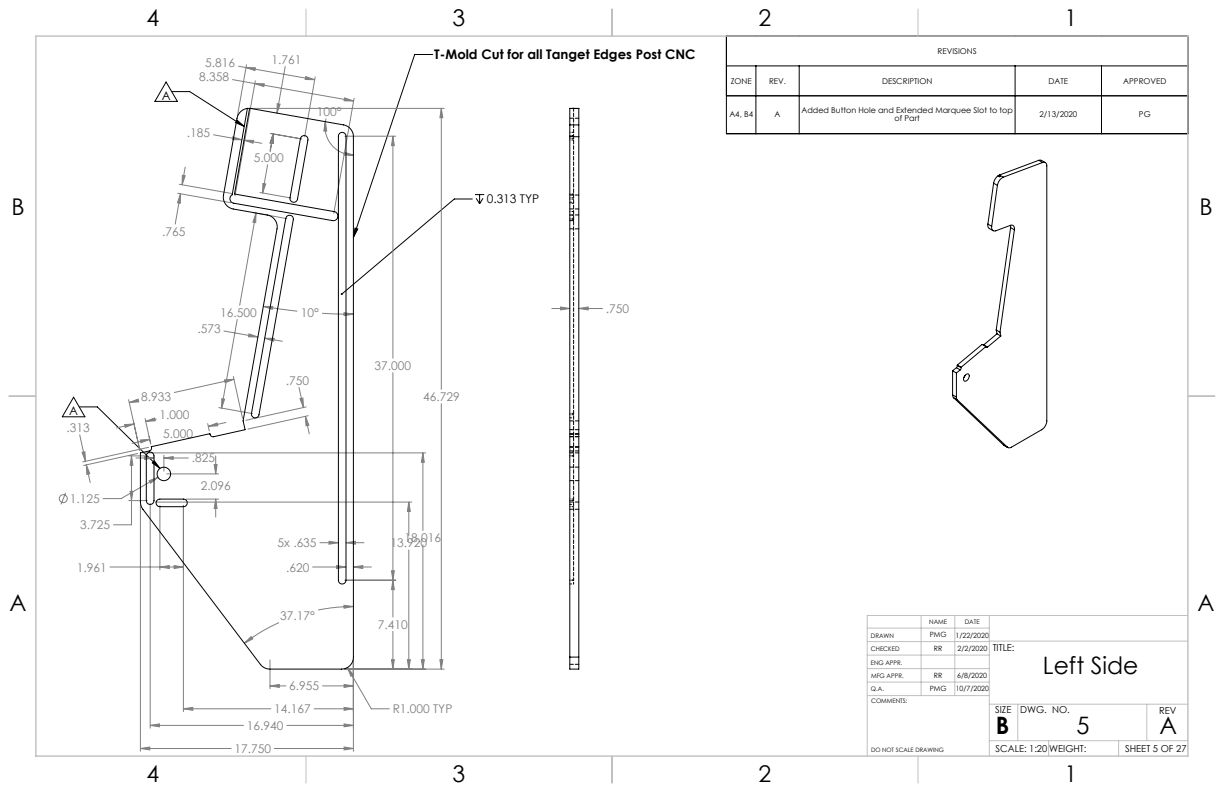
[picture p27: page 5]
R1.000 TYP; 0.313 TYP

T-Mold Cut for all Tanget Edges Post CNC

REVISIONS

ZONE | REV. | DESCRIPTION | DATE | APPROVED

A4, B4 | A | Added Button Hole and Extended Marquee Slot to top of Part | 2/13/2020 | PG

NAME | DATE
CHECKED | RR | 2/2/2020 | TITLE: Left Side

DRAWN | PMG | 1/22/2020

ENG APPR.
MFG APPR. | RR | 6/8/2020
Q.A. | PMG | 10/7/2020

SIZE B | DWG. NO. 5 | REV A

SCALE: 1:20 WEIGHT:

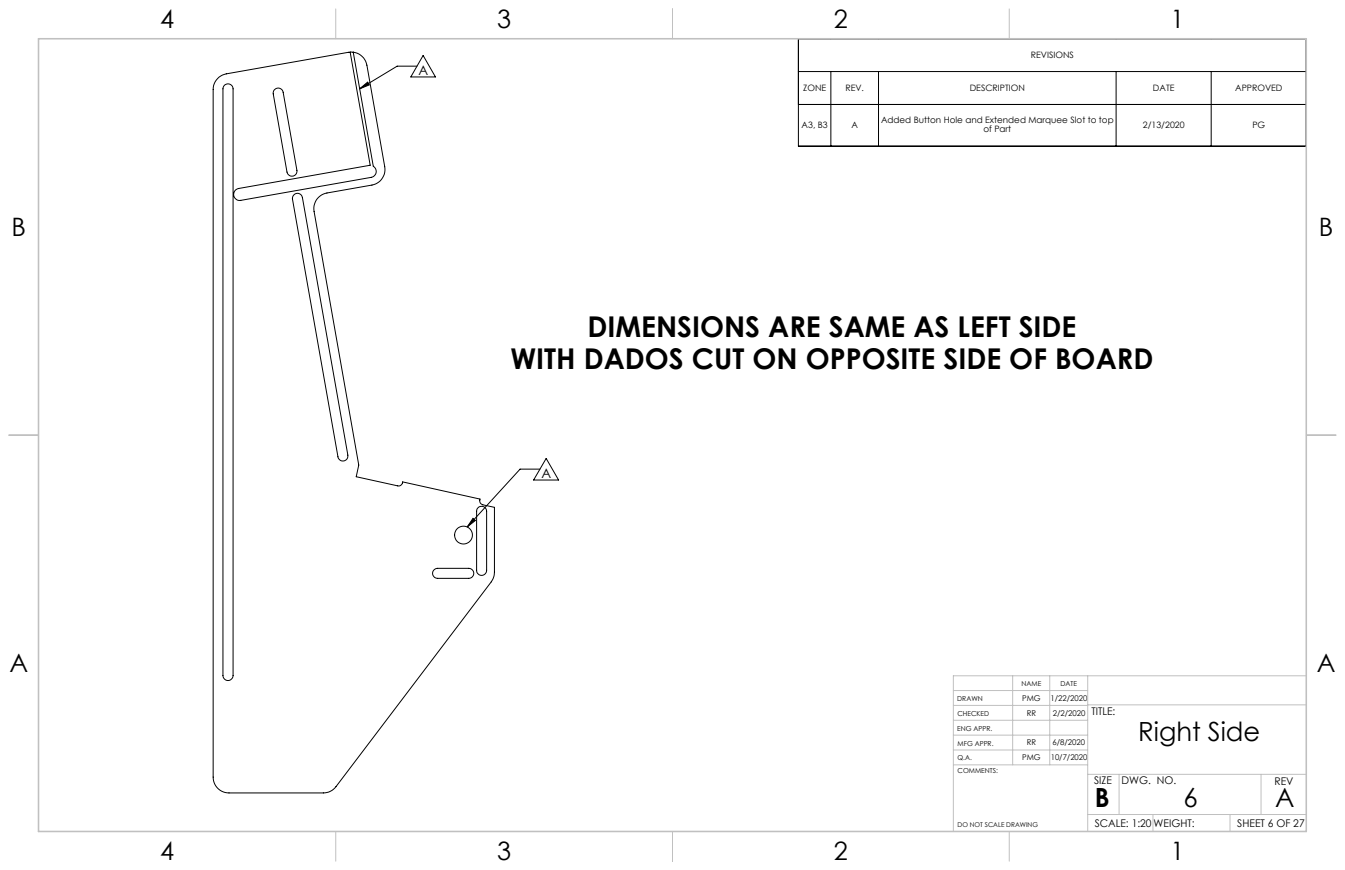
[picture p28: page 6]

REVISIONS

ZONE | REV. | DESCRIPTION | DATE | APPROVED

A3, B3 | A | Added Button Hole and Extended Marquee Slot to top of Part | 2/13/2020 | PG

DIMENSIONS ARE SAME AS LEFT SIDE
WITH DADOS CUT ON OPPOSITE SIDE OF BOARD

NAME | DATE
CHECKED | RR | 2/2/2020 | TITLE: Right Side

DRAWN | PMG | 1/22/2020

ENG APPR.
MFG APPR. | RR | 6/8/2020
Q.A. | PMG | 10/7/2020

SIZE B | DWG. NO. 6 | REV A

SCALE: 1:20 WEIGHT:

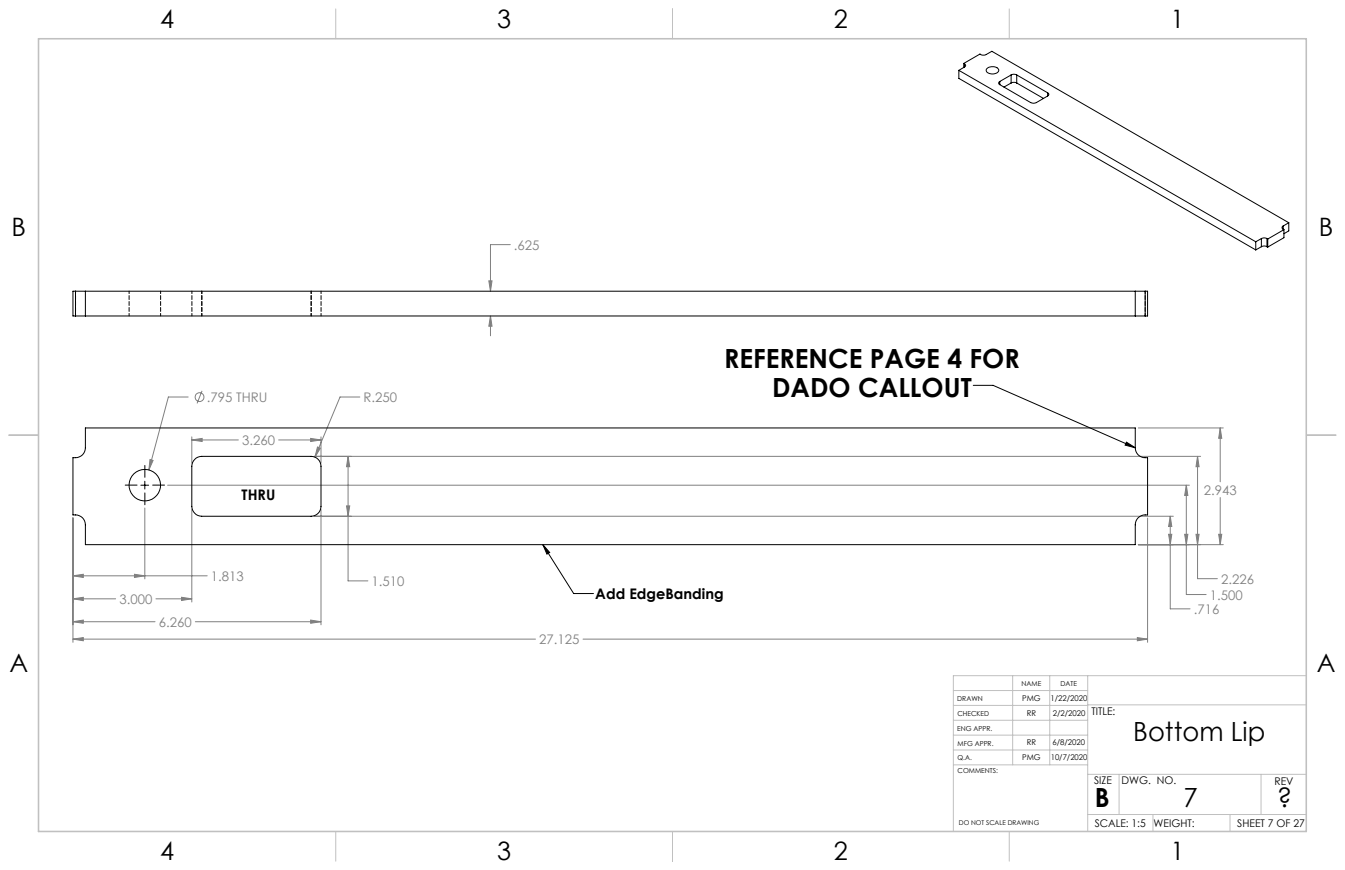
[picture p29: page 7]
.795 THRU; Add EdgeBanding; DWG. NO.; REV

REFERENCE PAGE 4 FOR
DADO CALLOUT

NAME | DATE
CHECKED | RR | 2/2/2020 | TITLE: Bottom Lip

DRAWN | PMG | 1/22/2020

ENG APPR.
MFG APPR. | RR | 6/8/2020
Q.A. | PMG | 10/7/2020

REFERENCE PAGE 4 FOR
DADO CALLOUT

NAME | DATE
CHECKED | RR | 2/2/2020 | TITLE: LED Panel

DRAWN | PMG | 1/22/2020

ENG APPR.
MFG APPR. | RR | 6/8/2020
Q.A. | 10/7/202010/7/2020

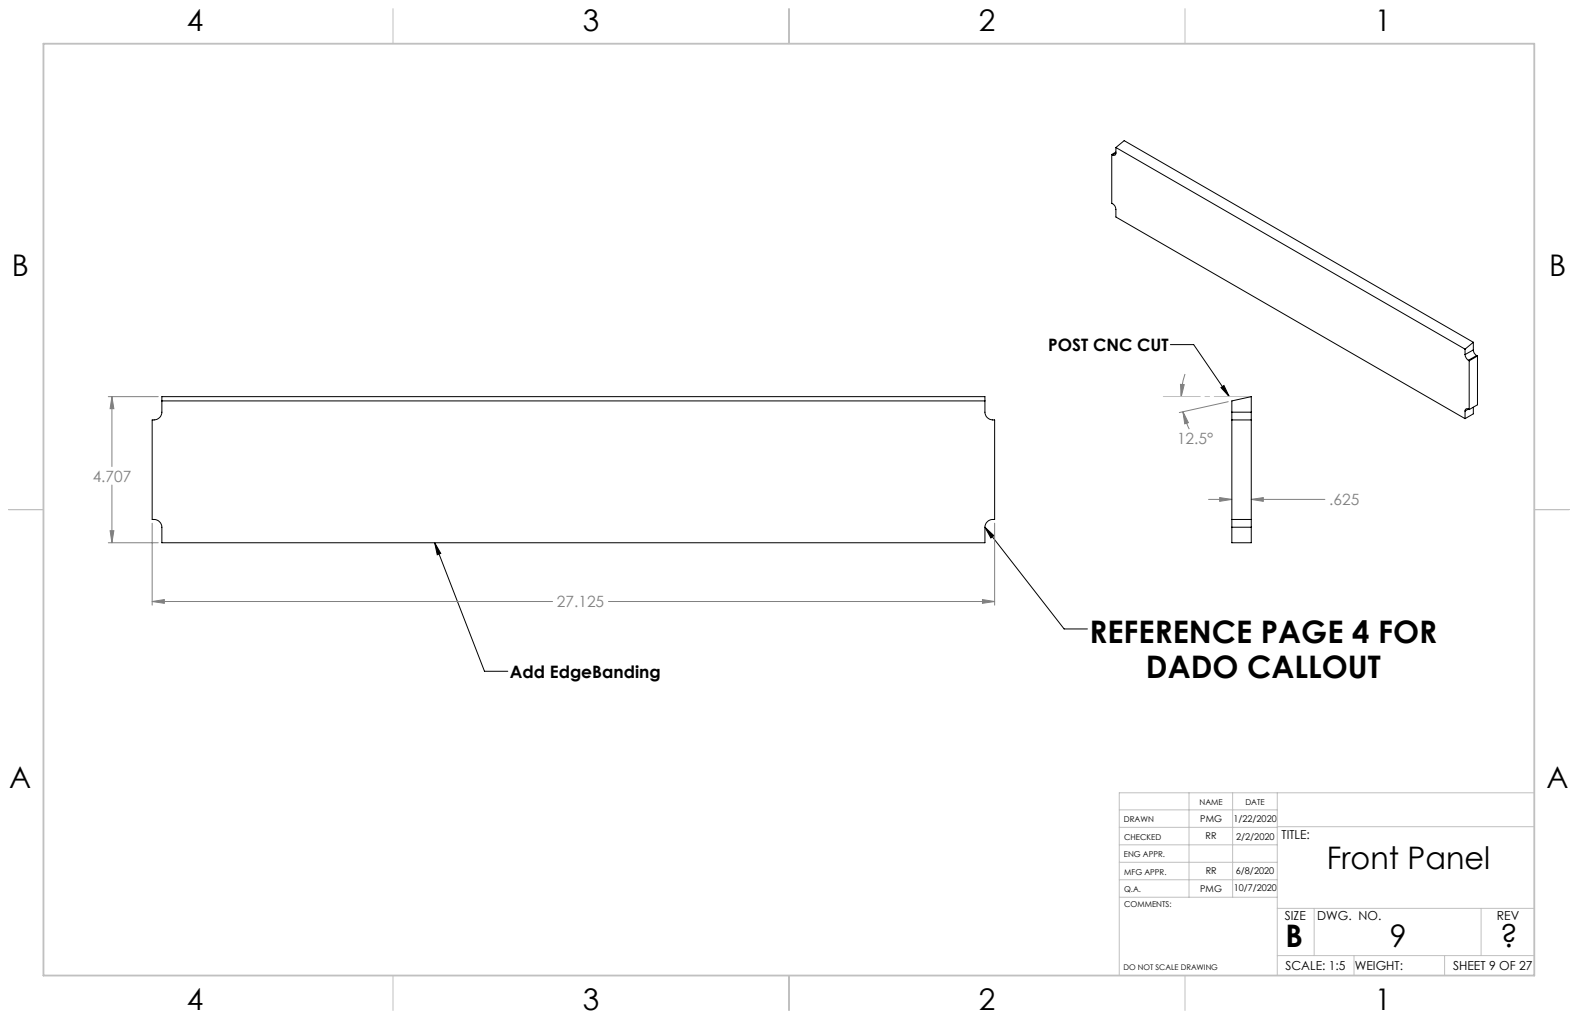
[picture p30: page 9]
Add EdgeBanding; DADO CALLOUT; DWG. NO.; REV

POST CNC CUT

REFERENCE PAGE 4 FOR

NAME | DATE
CHECKED | RR | 2/2/2020 | TITLE: Front Panel

DRAWN | PMG | 1/22/2020

ENG APPR.
MFG APPR. | RR | 6/8/2020
Q.A. | PMG | 10/7/2020

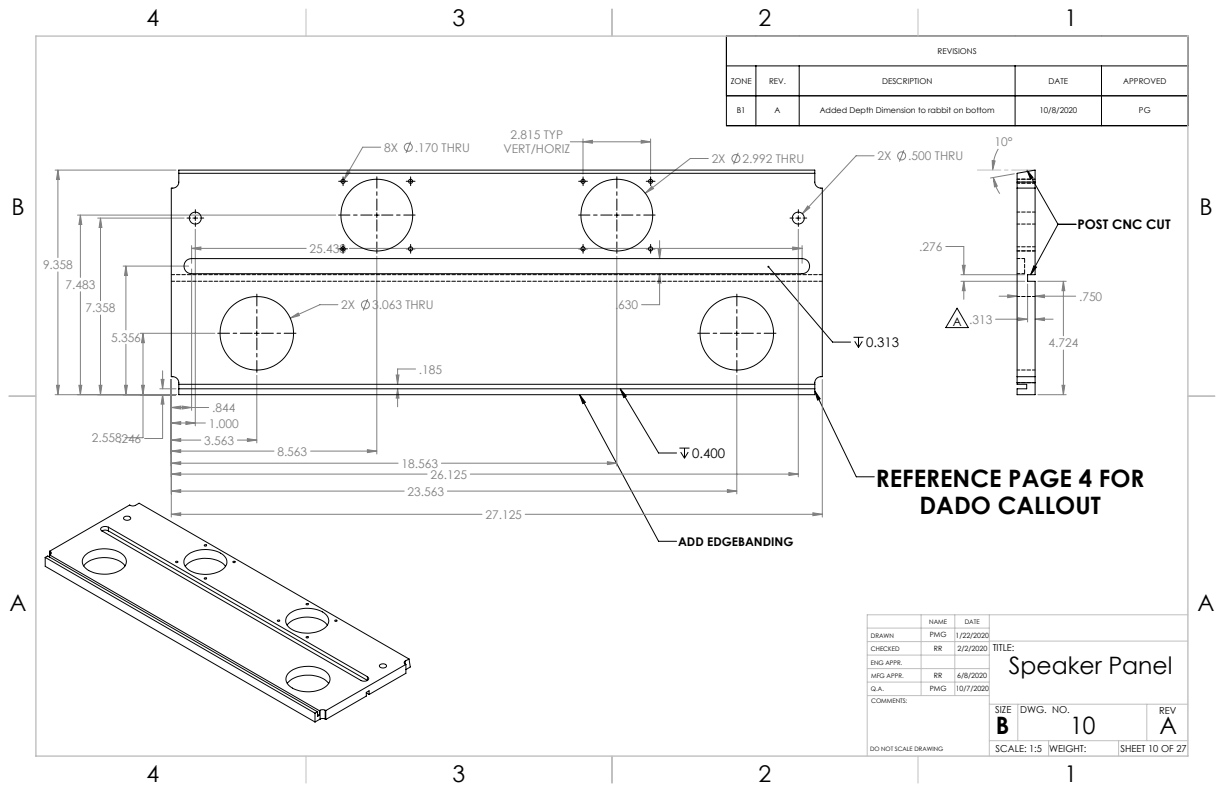
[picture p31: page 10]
2X 3.063 THRU; 2X .500 THRU; 2X 2.992 THRU; 2.815 TYP; 8X .170 THRU; VERT/HORIZ; ADD EDGEBANDING; DWG. NO.; REV

REVISIONS

ZONE | REV. | DESCRIPTION | DATE | APPROVED

B1 | A | Added Depth Dimension to rabbit on bottom | 10/8/2020 | PG

POST CNC CUT

REFERENCE PAGE 4 FOR
DADO CALLOUT

NAME | DATE
CHECKED | RR | 2/2/2020 | TITLE: Speaker Panel

DRAWN | PMG | 1/22/2020

ENG APPR.
MFG APPR. | RR | 6/8/2020
Q.A. | PMG | 10/7/2020

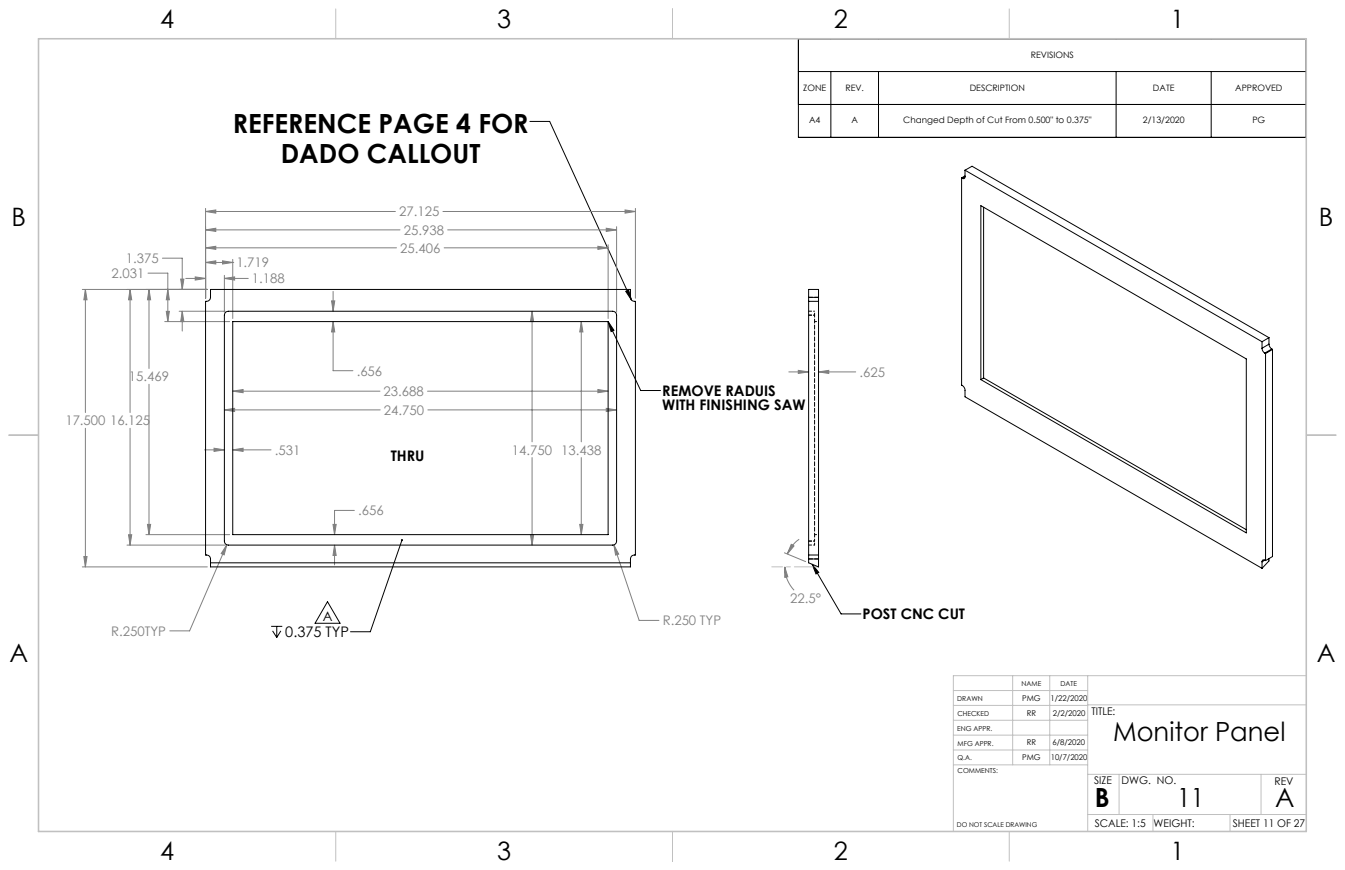
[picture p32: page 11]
R.250 TYP; 0.375 TYP; POST CNC CUT; DWG. NO.; REV

REVISIONS

ZONE | REV. | DESCRIPTION | DATE | APPROVED

REFERENCE PAGE 4 FOR
DADO CALLOUT

A4 | A | Changed Depth of Cut From 0.500" to 0.375" | 2/13/2020 | PG

REMOVE RADUIS
WITH FINISHING SAW

NAME | DATE
CHECKED | RR | 2/2/2020 | TITLE: Monitor Panel

DRAWN | PMG | 1/22/2020

ENG APPR.
MFG APPR. | RR | 6/8/2020
Q.A. | PMG | 10/7/2020

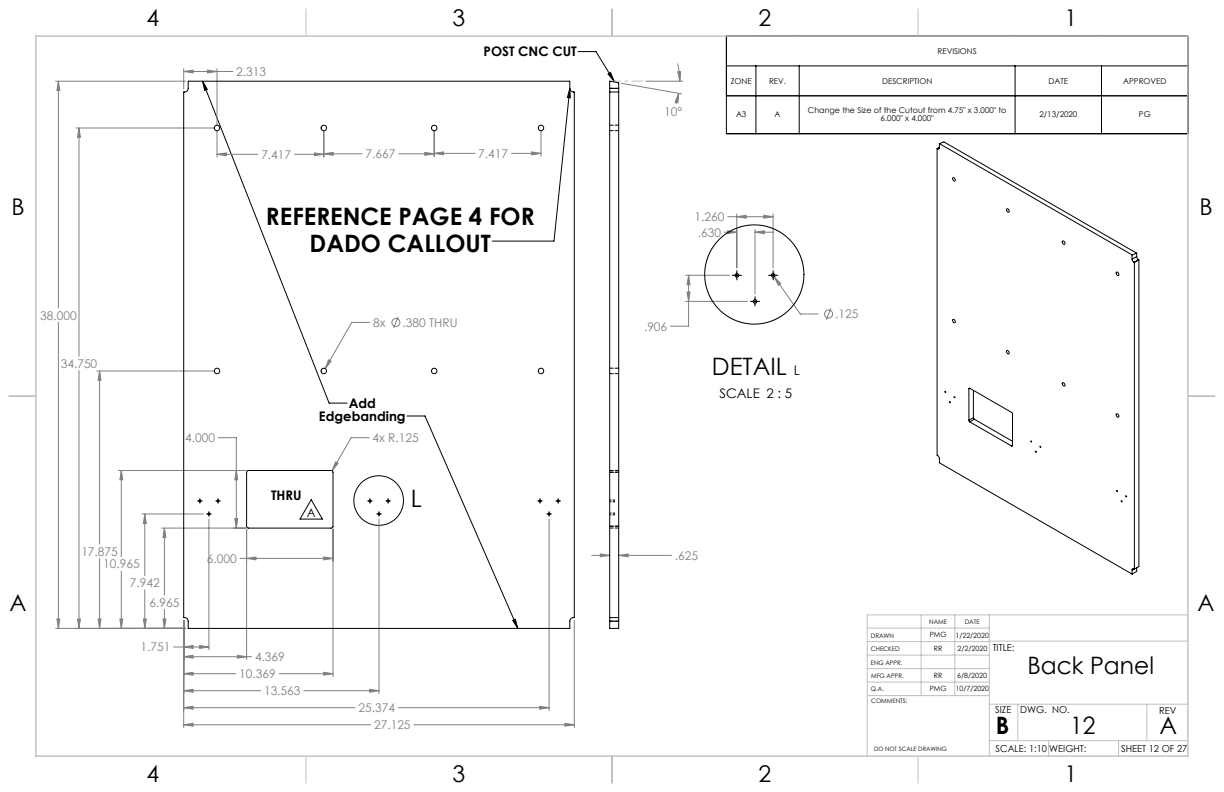
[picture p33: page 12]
8x .380 THRU; DETAIL L; SCALE 2 : 5

POST CNC CUT

REVISIONS

ZONE | REV. | DESCRIPTION | DATE | APPROVED

A3 | A | Change the Size of the Cutout from 4.75" x 3.000" to 6.000" x 4.000" | 2/13/2020 | PG

REFERENCE PAGE 4 FOR
DADO CALLOUT

NAME | DATE
CHECKED | RR | 2/2/2020 | TITLE: Back Panel

DRAWN | PMG | 1/22/2020

ENG APPR.
MFG APPR. | RR | 6/8/2020
Q.A. | PMG | 10/7/2020

SIZE B | DWG. NO. 12 | REV A

SCALE: 1:10 WEIGHT:

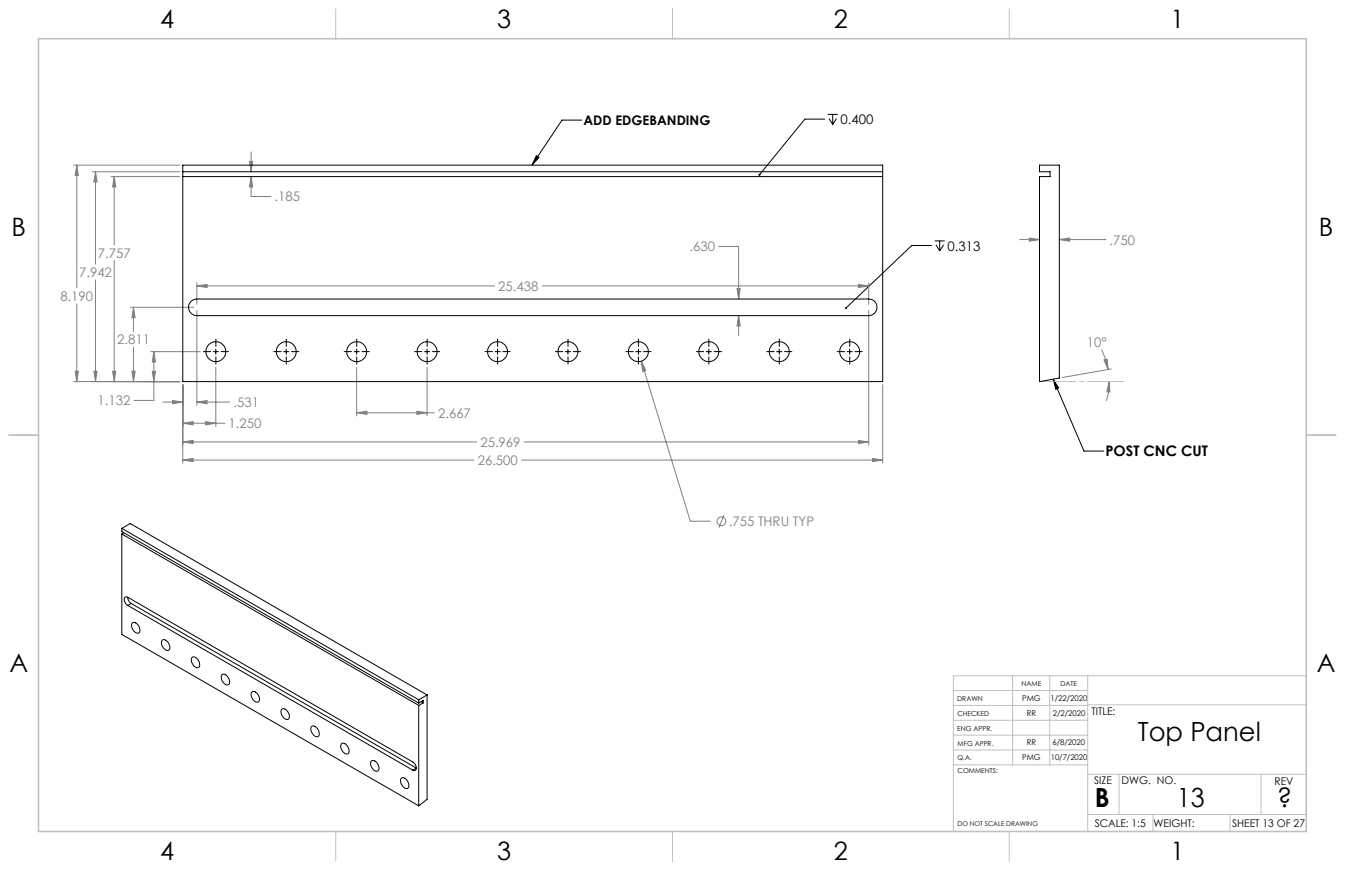
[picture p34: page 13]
.755 THRU TYP; ADD EDGEBANDING; DWG. NO.; REV

POST CNC CUT

NAME | DATE
CHECKED | RR | 2/2/2020 | TITLE: Top Panel

DRAWN | PMG | 1/22/2020

ENG APPR.
MFG APPR. | RR | 6/8/2020
Q.A. | PMG | 10/7/2020

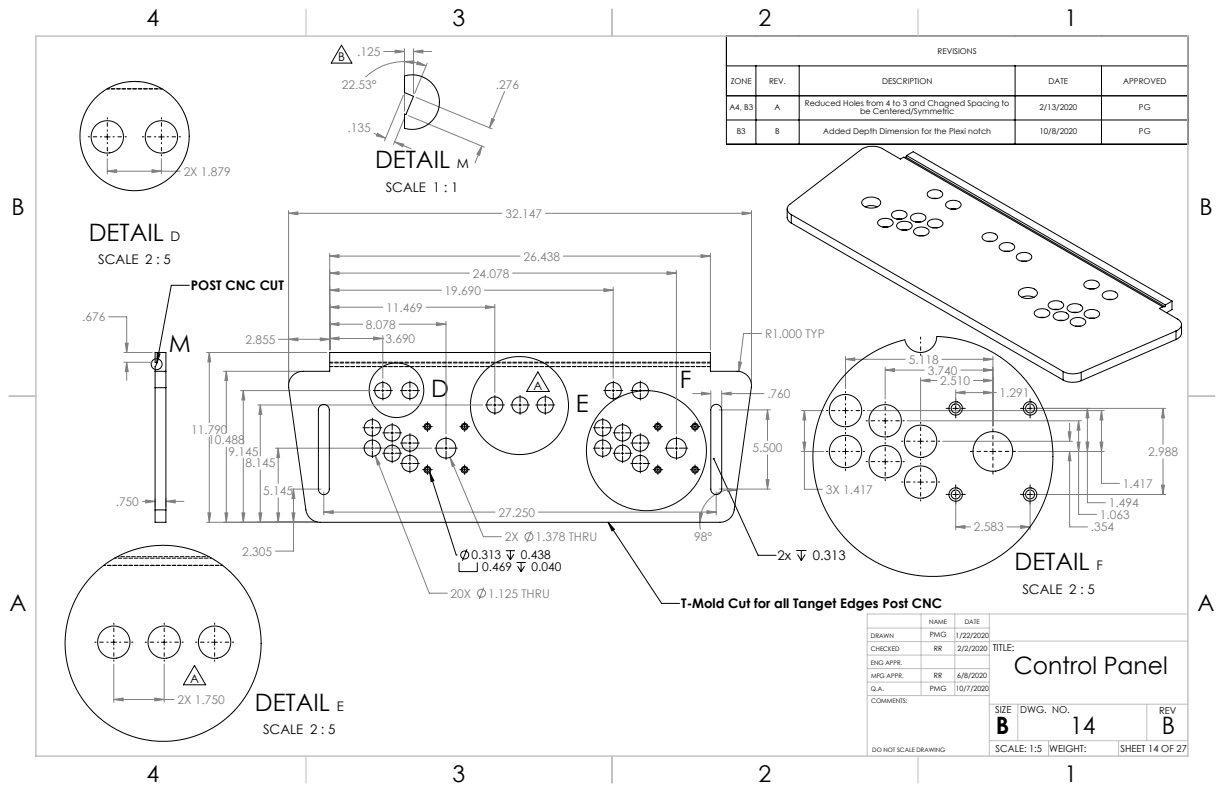
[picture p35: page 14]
R1.000 TYP; 2X 1.378 THRU; 20X 1.125 THRU; DETAIL D; SCALE 2 : 5; DETAIL E; DETAIL F; DETAIL M; SCALE 1 : 1; DWG. NO.; REV

ZONE | REV. | DESCRIPTION | DATE | APPROVED

A4, B3 | A | Reduced Holes from 4 to 3 and Chagned Spacing to be Centered/Symmetric | 2/13/2020 | PG

B3 | B | Added Depth Dimension for the Plexi notch | 10/8/2020 | PG

POST CNC CUT

T-Mold Cut for all Tanget Edges Post CNC

NAME | DATE
CHECKED | RR | 2/2/2020 | TITLE: Control Panel

DRAWN | PMG | 1/22/2020

ENG APPR.
MFG APPR. | RR | 6/8/2020
Q.A. | PMG | 10/7/2020

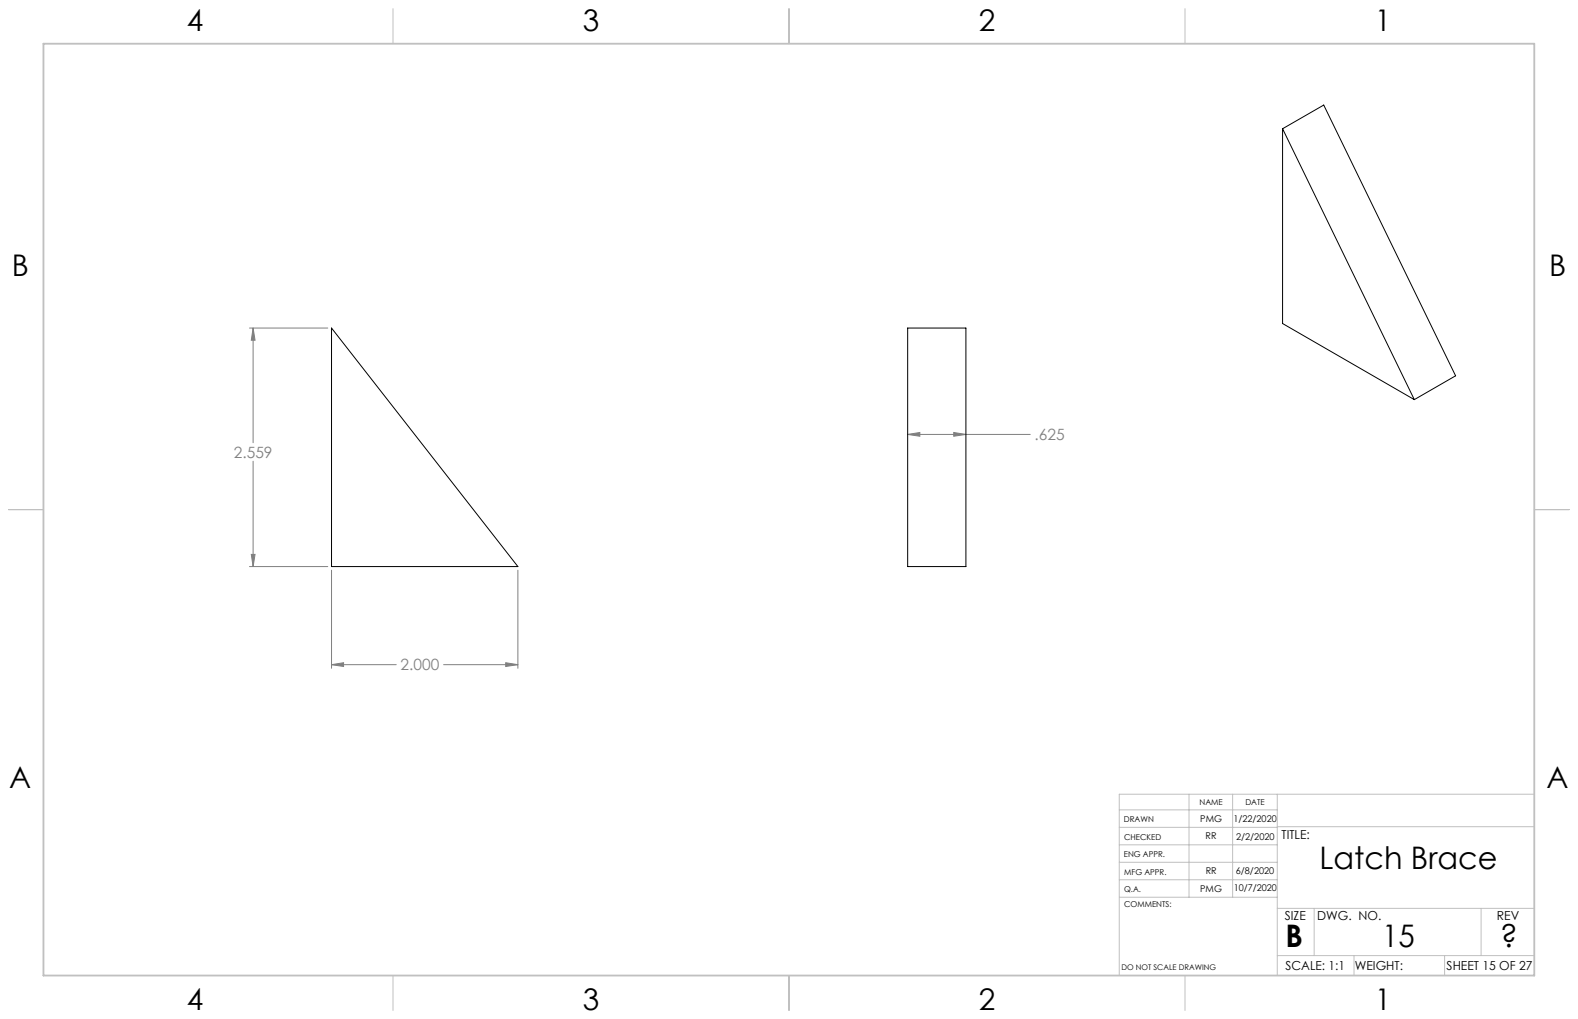
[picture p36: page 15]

NAME | DATE
CHECKED | RR | 2/2/2020 | TITLE: Latch Brace

DRAWN | PMG | 1/22/2020

ENG APPR.
MFG APPR. | RR | 6/8/2020
Q.A. | PMG | 10/7/2020

SIZE B | DWG. NO. 15 | REV ?

SCALE: 1:1 | WEIGHT:

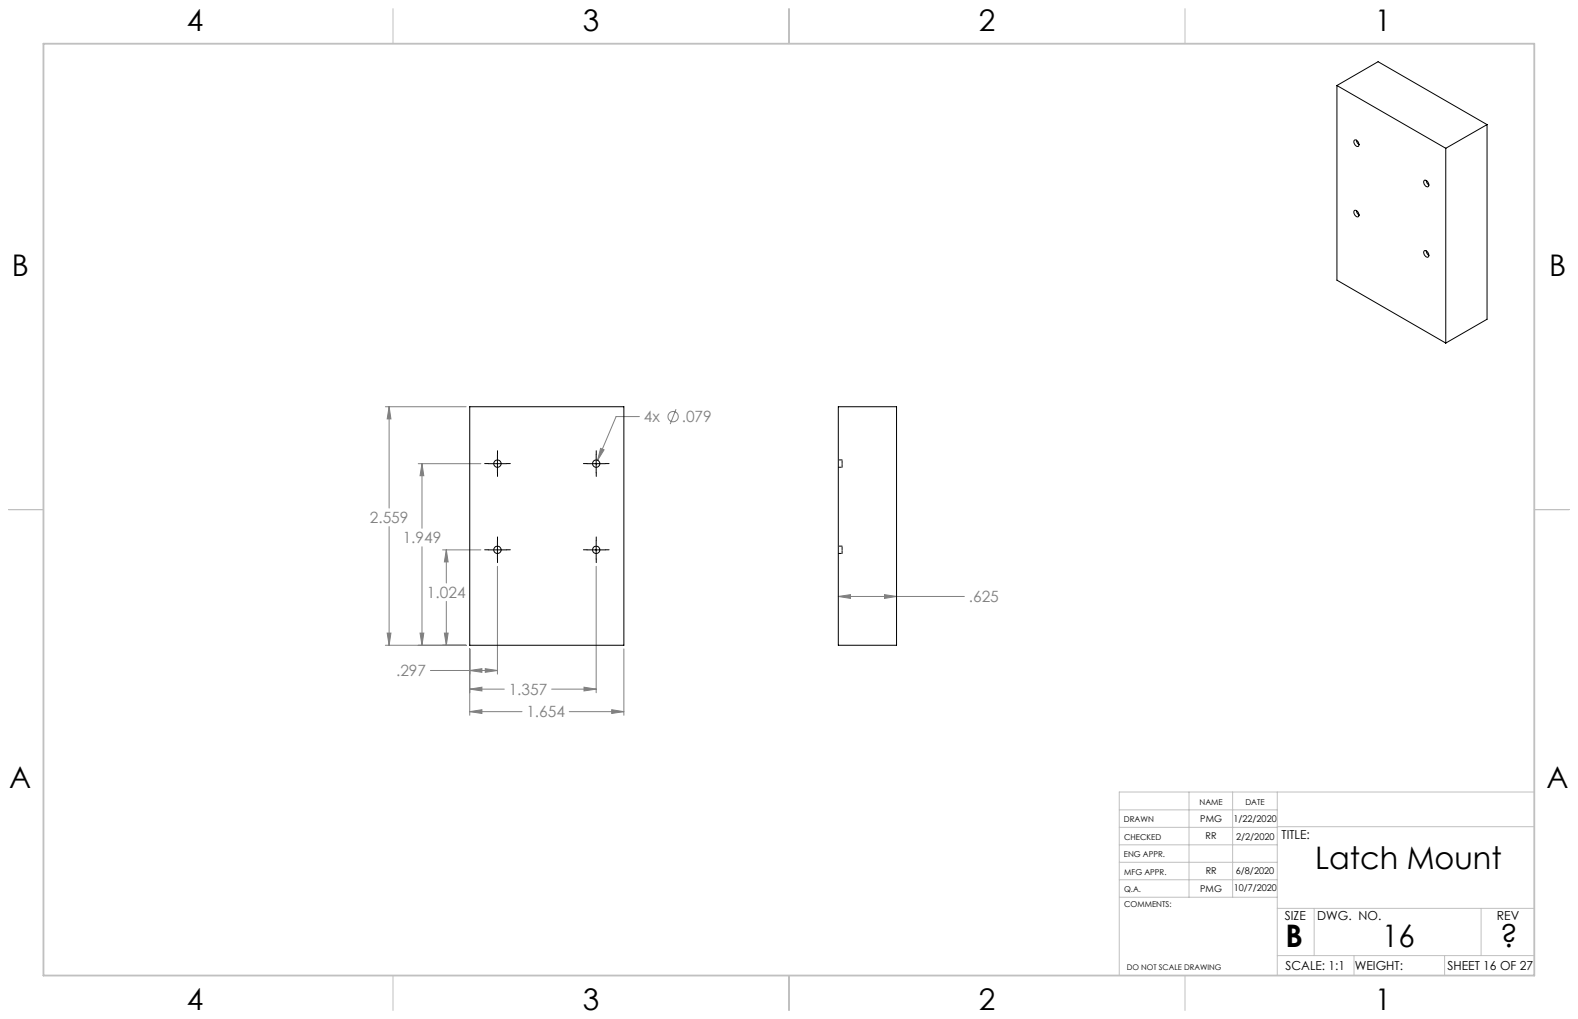
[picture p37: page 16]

NAME | DATE
CHECKED | RR | 2/2/2020 | TITLE: Latch Mount

DRAWN | PMG | 1/22/2020

ENG APPR.
MFG APPR. | RR | 6/8/2020
Q.A. | PMG | 10/7/2020

SIZE B | DWG. NO. 16 | REV ?

SCALE: 1:1 | WEIGHT:

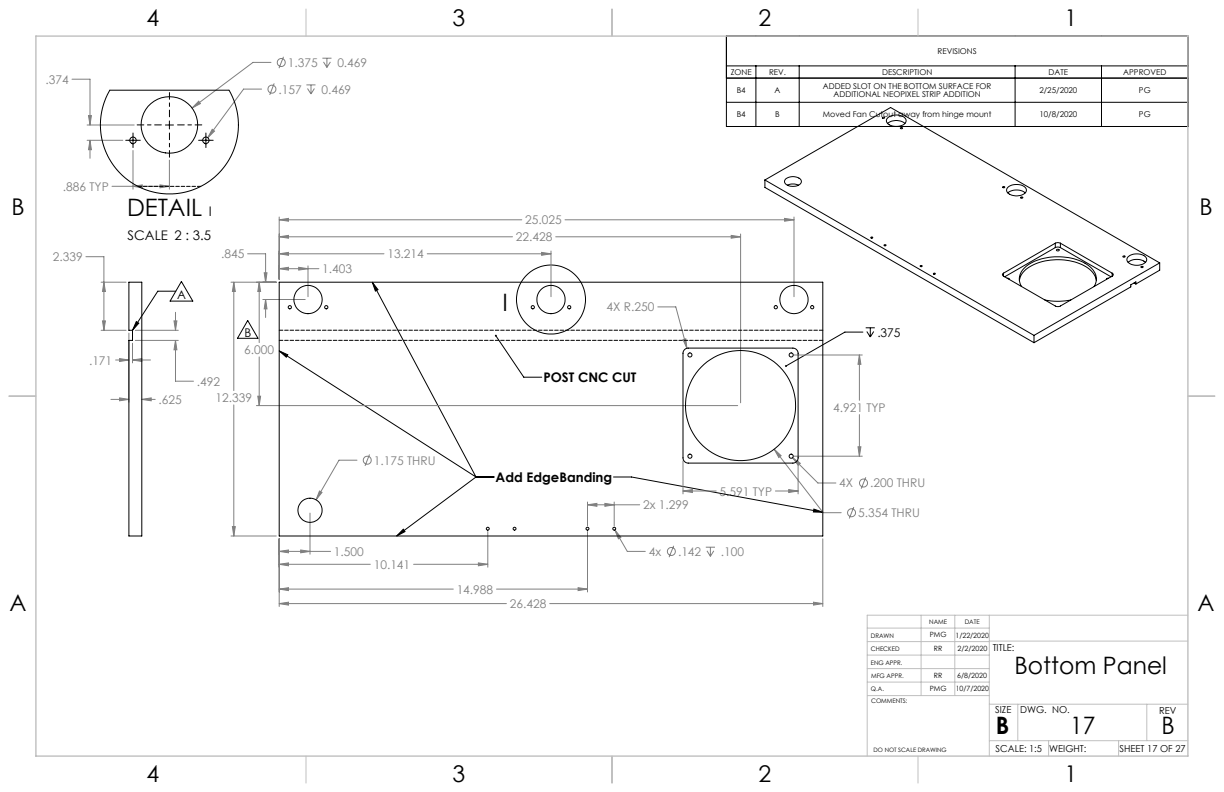
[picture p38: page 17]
1.175 THRU; 5.354 THRU; 4X .200 THRU; 4.921 TYP; 5.591 TYP; Add EdgeBanding; .886 TYP; DETAIL I; SCALE 2 : 3.5; DWG. NO.; REV

REVISIONS

ZONE | REV. | DESCRIPTION | DATE | APPROVED
B4 | A | ADDED SLOT ON THE BOTTOM SURFACE FOR ADDITIONAL NEOPIXEL STRIP ADDITION | 2/25/2020 | PG

B4 | B | Moved Fan Cutout away from hinge mount | 10/8/2020 | PG

POST CNC CUT

NAME | DATE
CHECKED | RR | 2/2/2020 | TITLE: Bottom Panel

DRAWN | PMG | 1/22/2020

ENG APPR.
MFG APPR. | RR | 6/8/2020
Q.A. | PMG | 10/7/2020

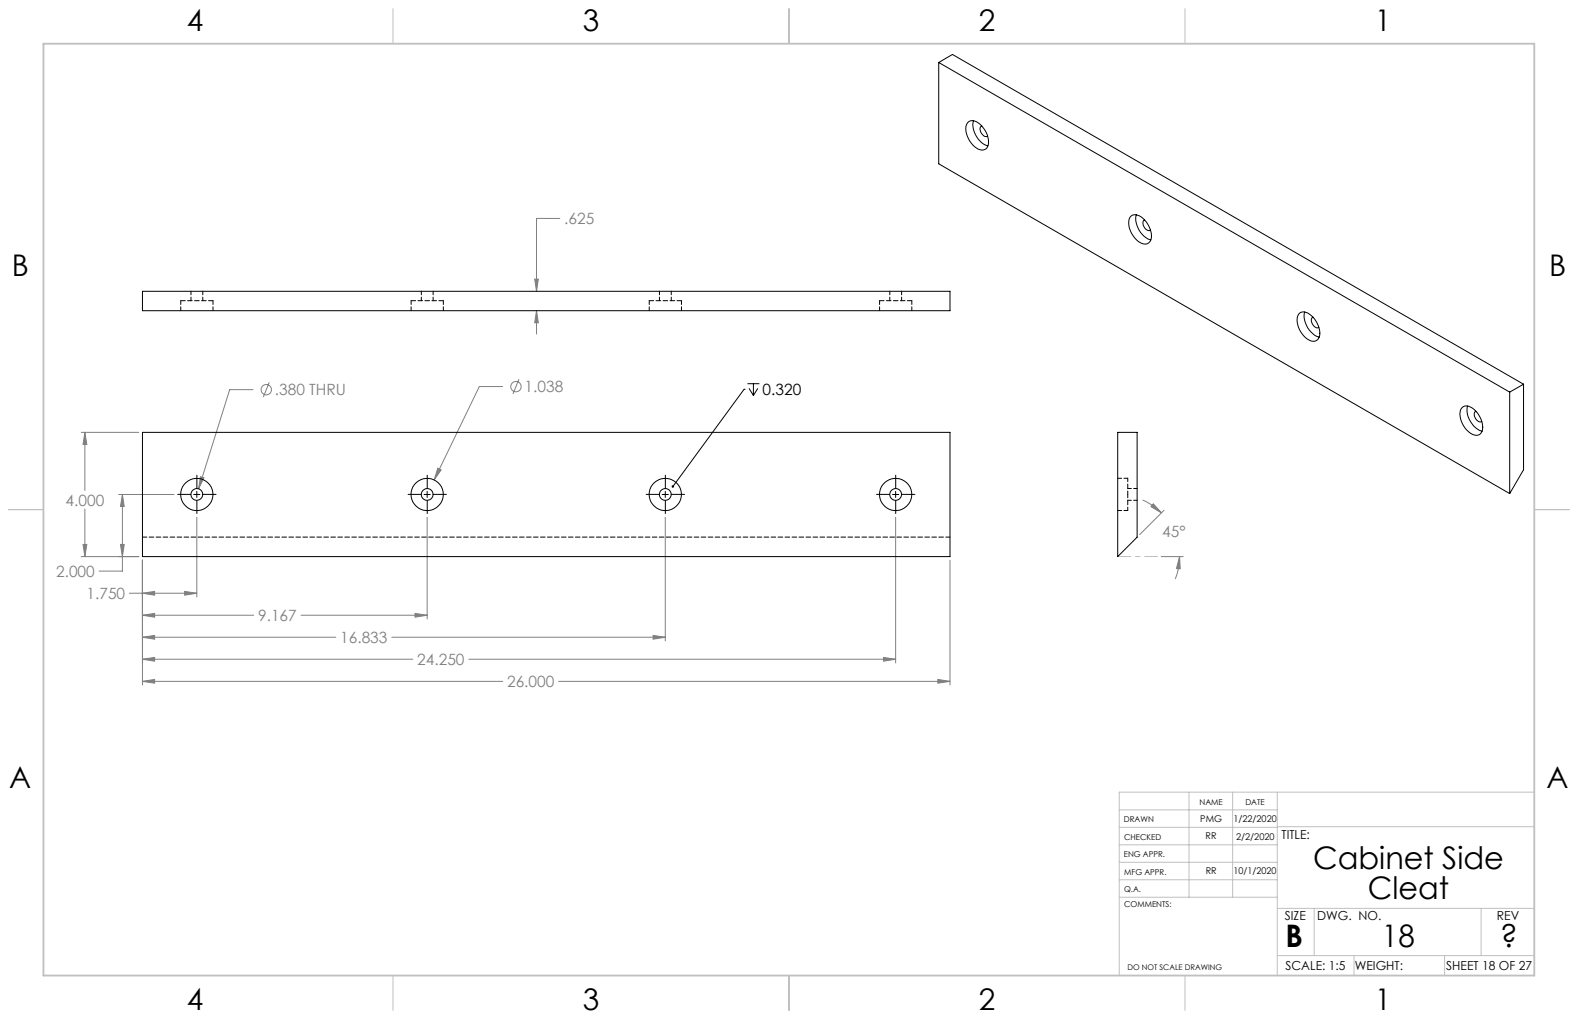
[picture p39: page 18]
.380 THRU; DWG. NO.; REV

NAME | DATE
CHECKED | RR | 2/2/2020 | TITLE: Cabinet Side Cleat

DRAWN | PMG | 1/22/2020

ENG APPR.
MFG APPR. | RR | 10/1/2020
Q.A.

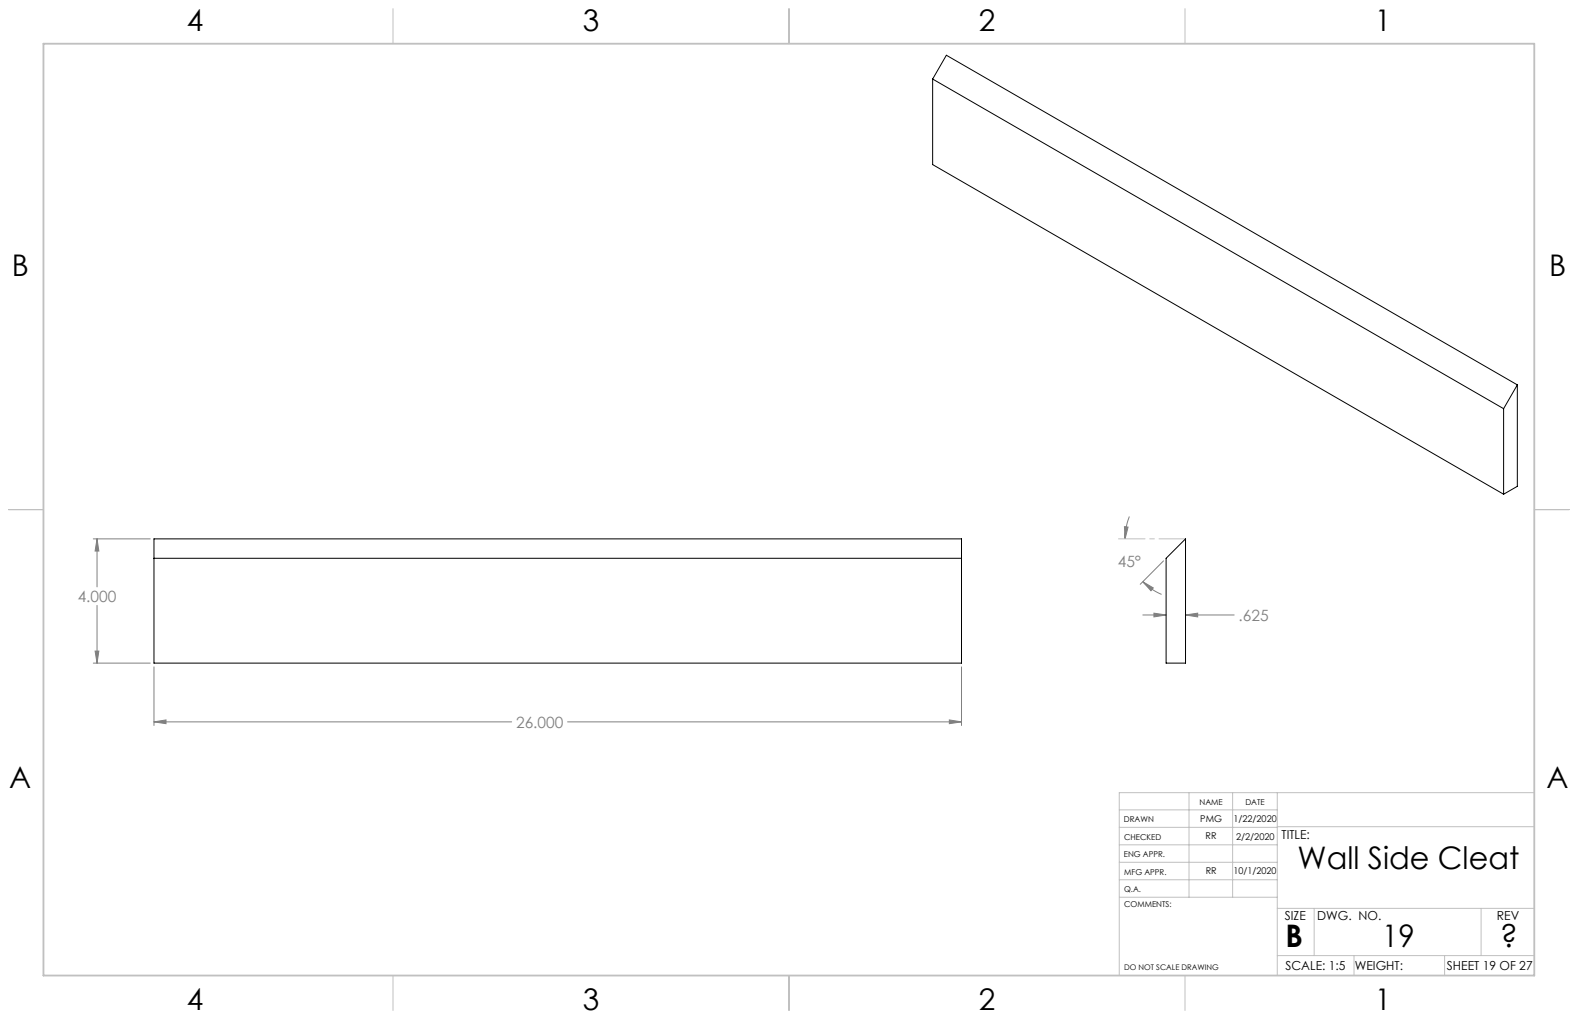
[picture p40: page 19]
DWG. NO.; REV

NAME | DATE
CHECKED | RR | 2/2/2020 | TITLE: Wall Side Cleat

DRAWN | PMG | 1/22/2020

ENG APPR.
MFG APPR. | RR | 10/1/2020
Q.A.

NAME | DATE
CHECKED | RR | 2/2/2020 | TITLE: Inside Cleat

DRAWN | PMG | 1/22/2020

ENG APPR.
MFG APPR. | RR | 10/1/2020
Q.A.

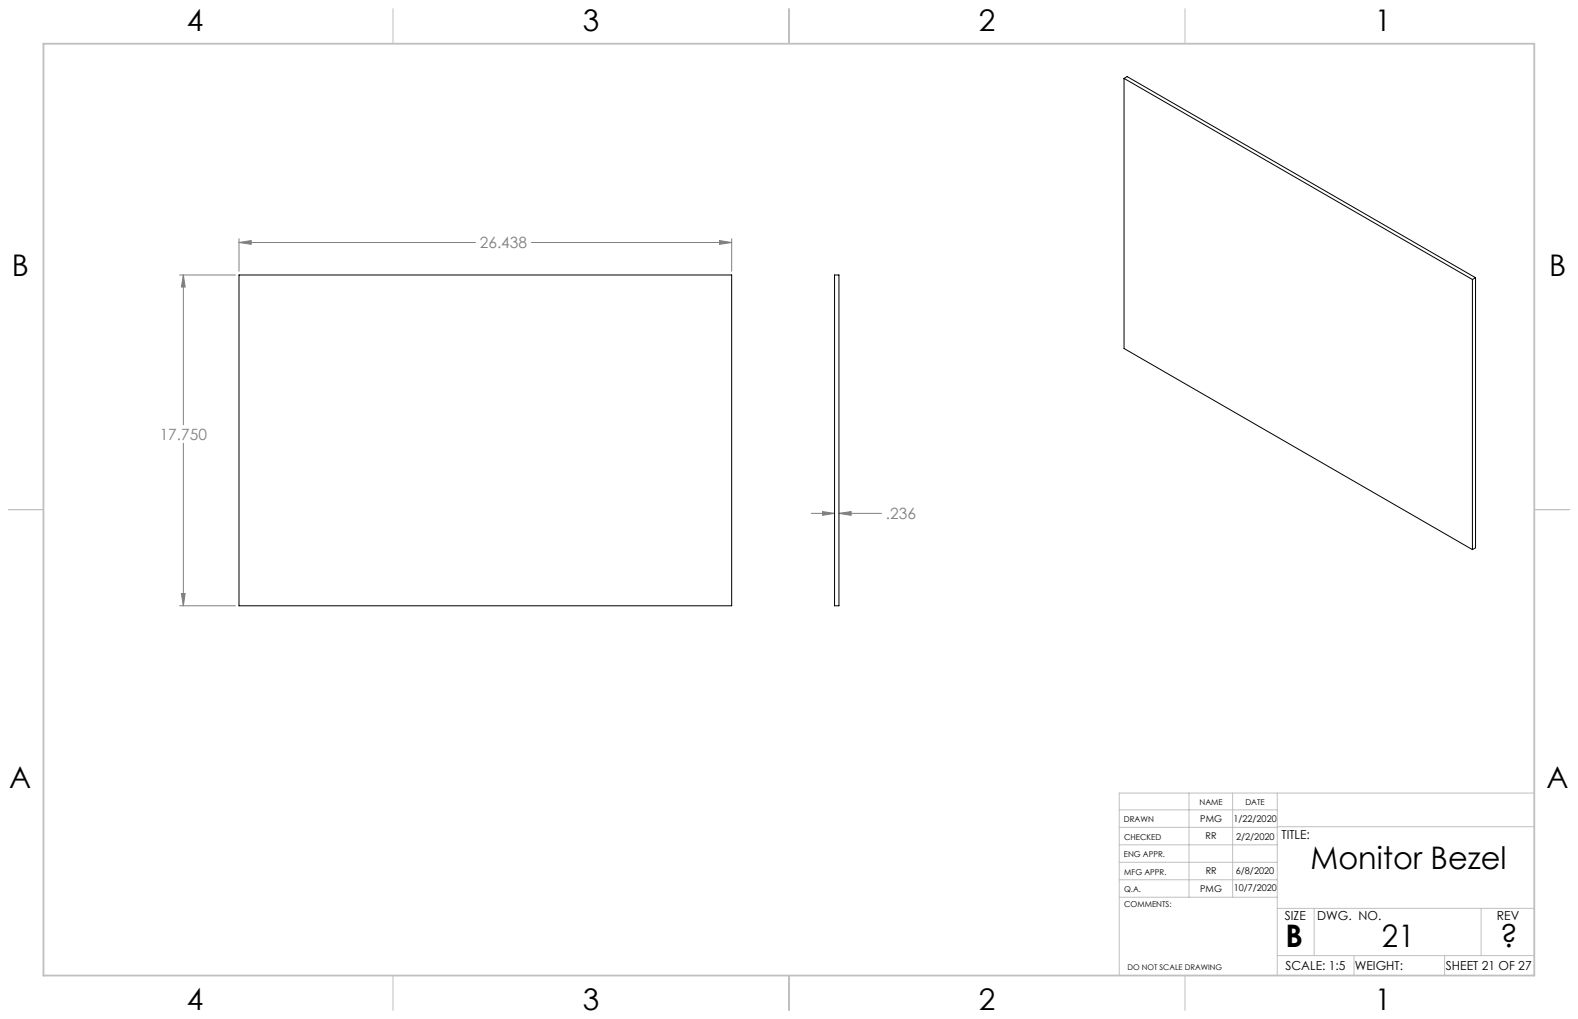
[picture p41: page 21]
DWG. NO.; REV

NAME | DATE
CHECKED | RR | 2/2/2020 | TITLE: Monitor Bezel

DRAWN | PMG | 1/22/2020

ENG APPR.
MFG APPR. | RR | 6/8/2020
Q.A. | PMG | 10/7/2020

NAME | DATE
CHECKED | GOG | 4/2/2020 | TITLE: Marquee Plexi

DRAWN | PMG | 1/22/2020

ENG APPR.
MFG APPR. | PMG | 4/26/2020
Q.A. | PMG | 5/12/2020

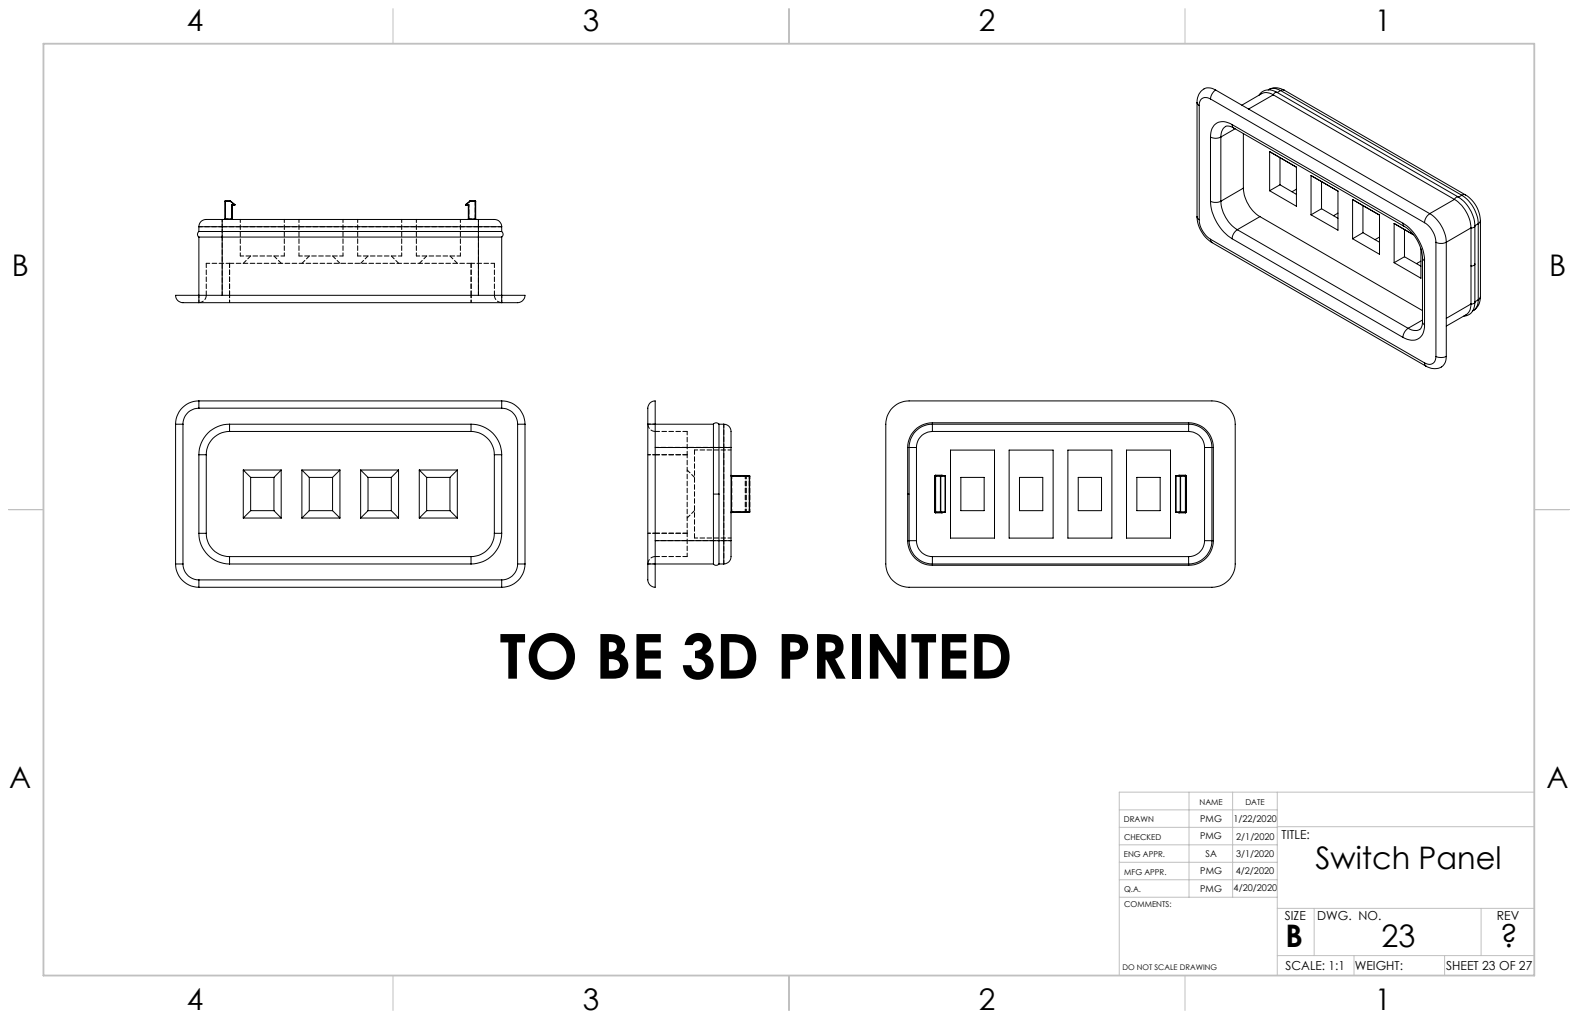
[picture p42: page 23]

TO BE 3D PRINTED

NAME | DATE
CHECKED | PMG | 2/1/2020 | TITLE: Switch Panel
ENG APPR. | SA | 3/1/2020
MFG APPR. | PMG | 4/2/2020
Q.A. | PMG | 4/20/2020

DRAWN | PMG | 1/22/2020

SIZE B | DWG. NO. 23 | REV ?

SCALE: 1:1 | WEIGHT:

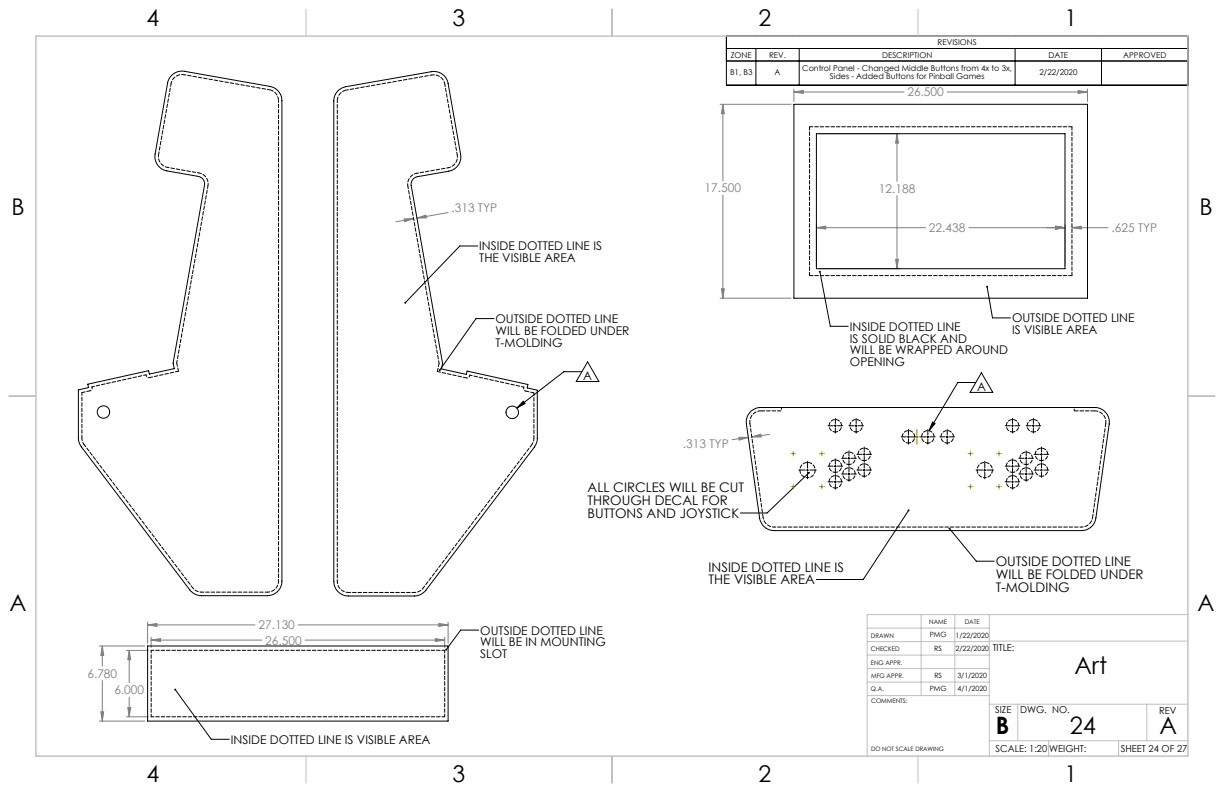
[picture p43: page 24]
.313 TYP; .625 TYP

REVISIONS

ZONE | REV. | DESCRIPTION | DATE | APPROVED
B1, B3 | A | Control Panel - Changed Middle Buttons from 4x to 3x, Sides - Added Buttons for Pinball Games | 2/22/2020

INSIDE DOTTED LINE IS
THE VISIBLE AREA

OUTSIDE DOTTED LINE
WILL BE FOLDED UNDER
T-MOLDING

IS VISIBLE AREA

INSIDE DOTTED LINE
IS SOLID BLACK AND
WILL BE WRAPPED AROUND
OPENING

ALL CIRCLES WILL BE CUT
THROUGH DECAL FOR
BUTTONS AND JOYSTICK

NAME | DATE
CHECKED | RS | 2/22/2020 | TITLE: Art

WILL BE IN MOUNTING
SLOT

DRAWN | PMG | 1/22/2020

ENG APPR.
MFG APPR. | RS | 3/1/2020
Q.A. | PMG | 4/1/2020

SIZE B | DWG. NO. 24 | REV A

INSIDE DOTTED LINE IS VISIBLE AREA

SCALE: 1:20 WEIGHT:

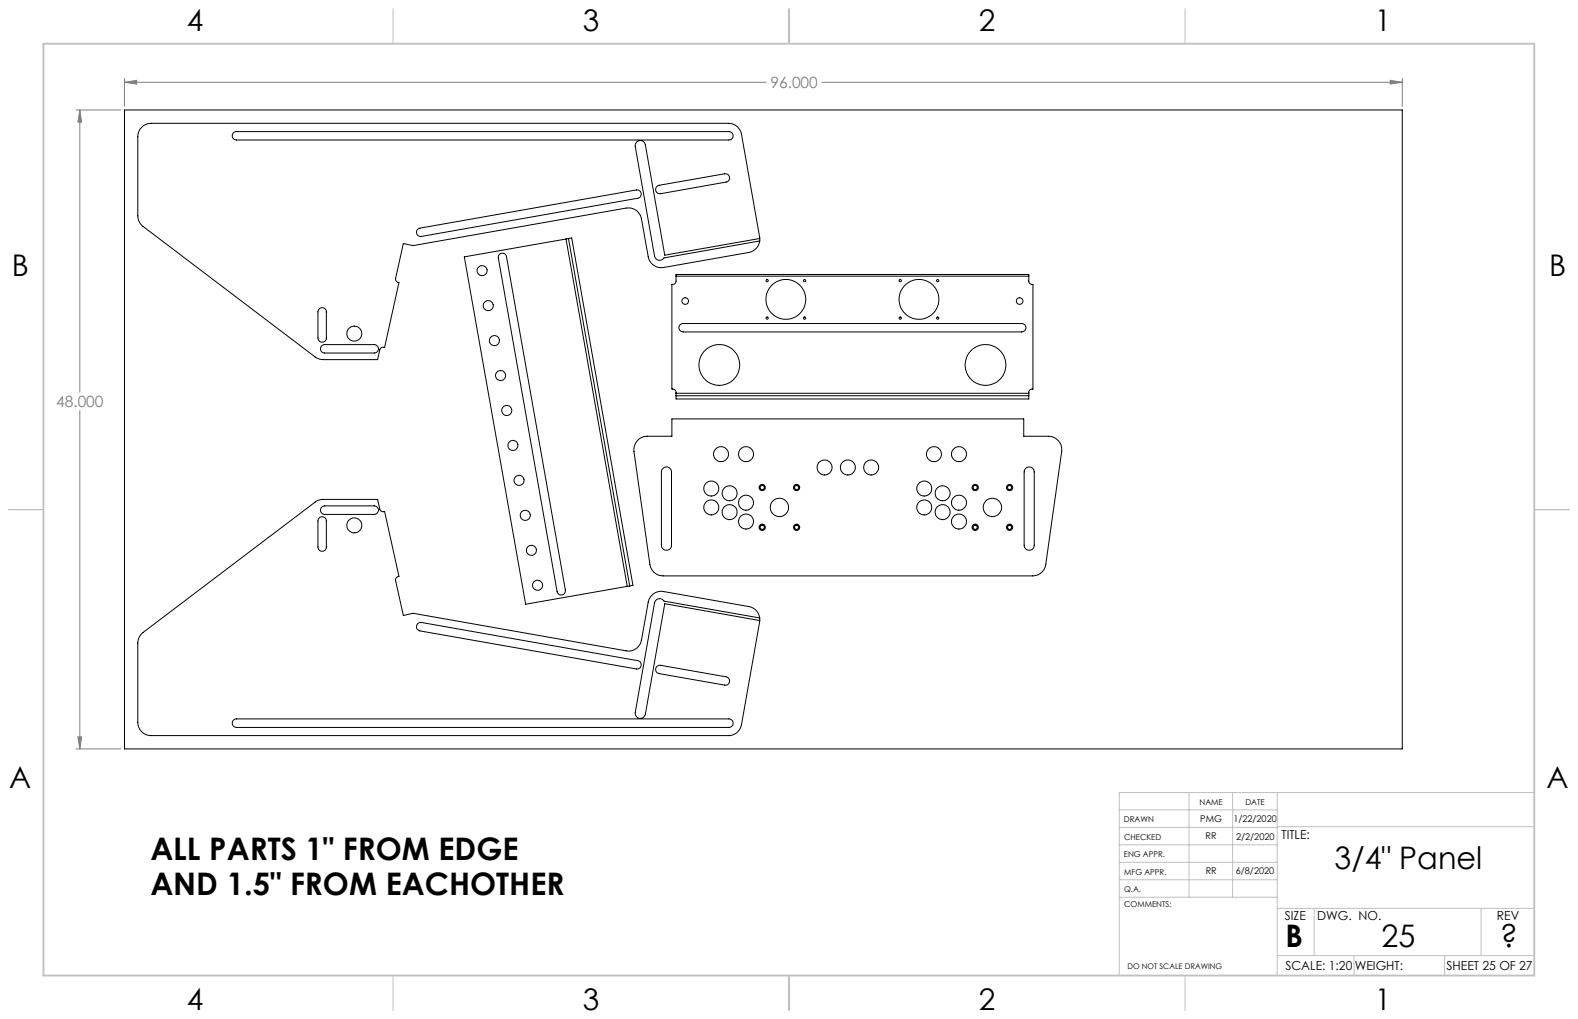
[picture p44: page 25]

NAME | DATE
CHECKED | RR | 2/2/2020 | TITLE: 3/4" Panel

DRAWN | PMG | 1/22/2020

ALL PARTS 1" FROM EDGE
AND 1.5" FROM EACHOTHER

ENG APPR.
MFG APPR. | RR | 6/8/2020
Q.A.

SIZE B | DWG. NO. 25 | REV ?

SCALE: 1:20 WEIGHT:

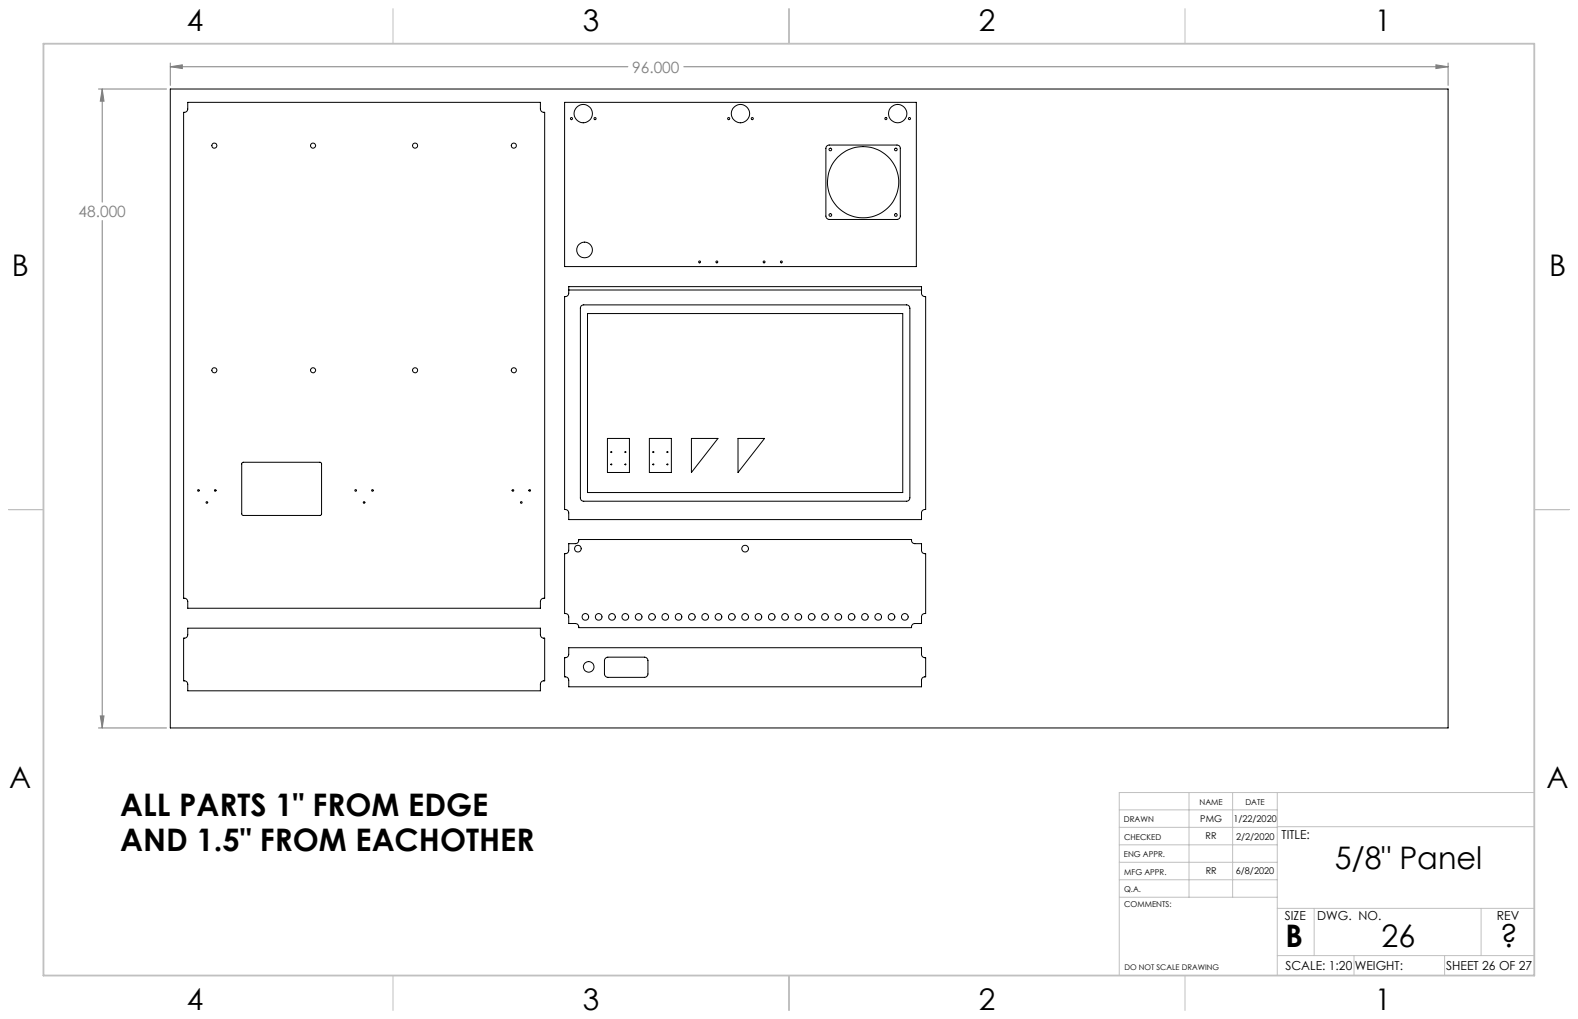
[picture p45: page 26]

ALL PARTS 1" FROM EDGE
AND 1.5" FROM EACHOTHER

NAME | DATE
CHECKED | RR | 2/2/2020 | TITLE: 5/8" Panel

DRAWN | PMG | 1/22/2020

ENG APPR.
MFG APPR. | RR | 6/8/2020
Q.A.

SIZE B | DWG. NO. 26 | REV ?

SCALE: 1:20 WEIGHT:

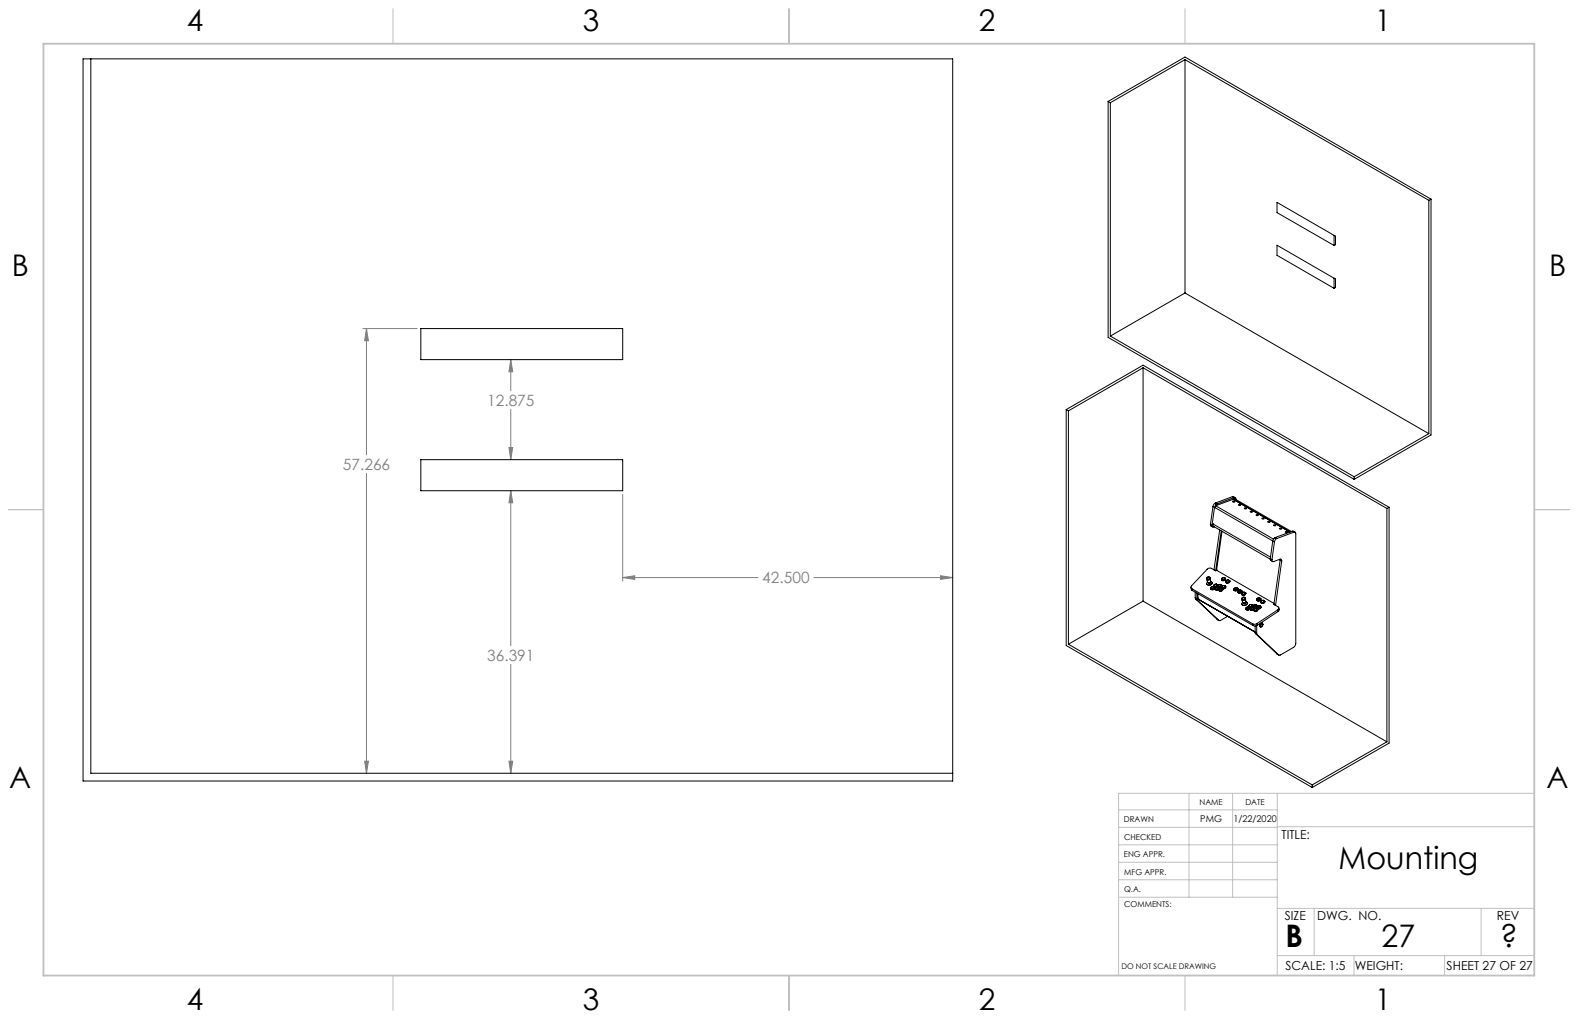
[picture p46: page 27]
DWG. NO.; REV

NAME | DATE
CHECKED | | | TITLE: Mounting

DRAWN | PMG | 1/22/2020

ENG APPR.
MFG APPR.
Q.A.

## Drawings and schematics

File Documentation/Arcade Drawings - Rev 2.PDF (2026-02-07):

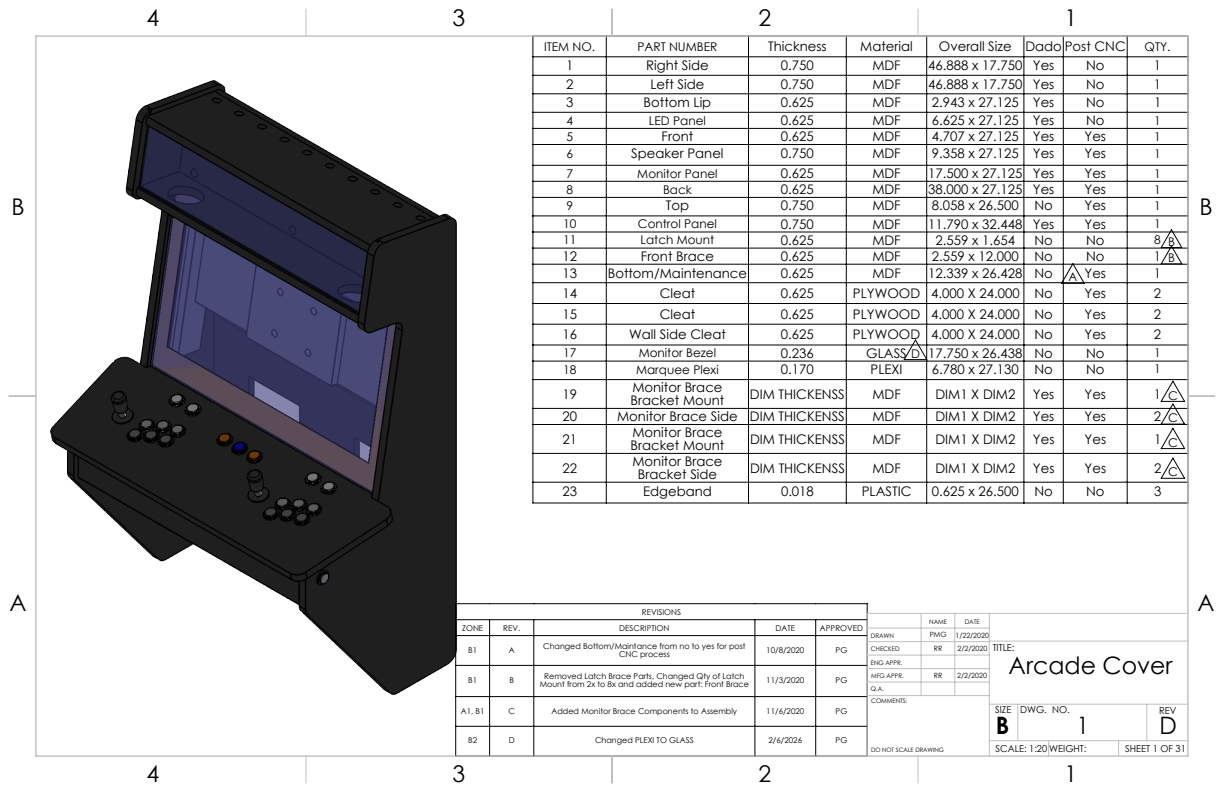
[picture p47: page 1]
ITEM NO.; PART NUMBER; Thickness; Material; Overall Size Dado Post CNC QTY. 1; Right Side; MDF; 46.888 x 17.750 Yes; Left Side; Bottom Lip; 2.943 x 27.125 Yes; LED Panel; 6.625 x 27.125 Yes; Front; 4.707 x 27.125 Yes; Yes; Speaker Panel; 9.358 x 27.125 Yes; Monitor Panel; 17.500 x 27.125 Yes; Back; 38.000 x 27.125 Yes; Top; Control Panel; 11.790 x 32.448 Yes; Latch Mount; Front Brace; Bottom/Maintenance; Cleat; PLYWOOD 4.000 X 24.000 No; Wall Side Cleat; Monitor Bezel; GLASS 17.750 x 26.438 No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

NAME | DATE
CHECKED | RR | 2/2/2020 | TITLE: Arcade CoverD

ZONE | REV. | DESCRIPTION | DATE | APPROVED
B1 | A | Changed Bottom/Maintance from no to yes for post CNC process | 10/8/2020 | PG

DRAWN | PMG | 1/22/2020

ENG APPR.
MFG APPR. | RR | 2/2/2020
Q.A.

B1 | B | Removed Latch Brace Parts, Changed Qty of Latch Mount from 2x to 8x and added new part: Front Brace | 11/3/2020 | PG

A1, B1 | C | Added Monitor Brace Components to Assembly | 11/6/2020 | PG | COMMENTS: DO NOT SCALE DRAWING

SIZE B | DWG. NO. 1 | REV

B2 | D | Changed PLEXI TO GLASS | 2/6/2026 | PG

SCALE: 1:20 WEIGHT: | | SHEET 1 OF 31

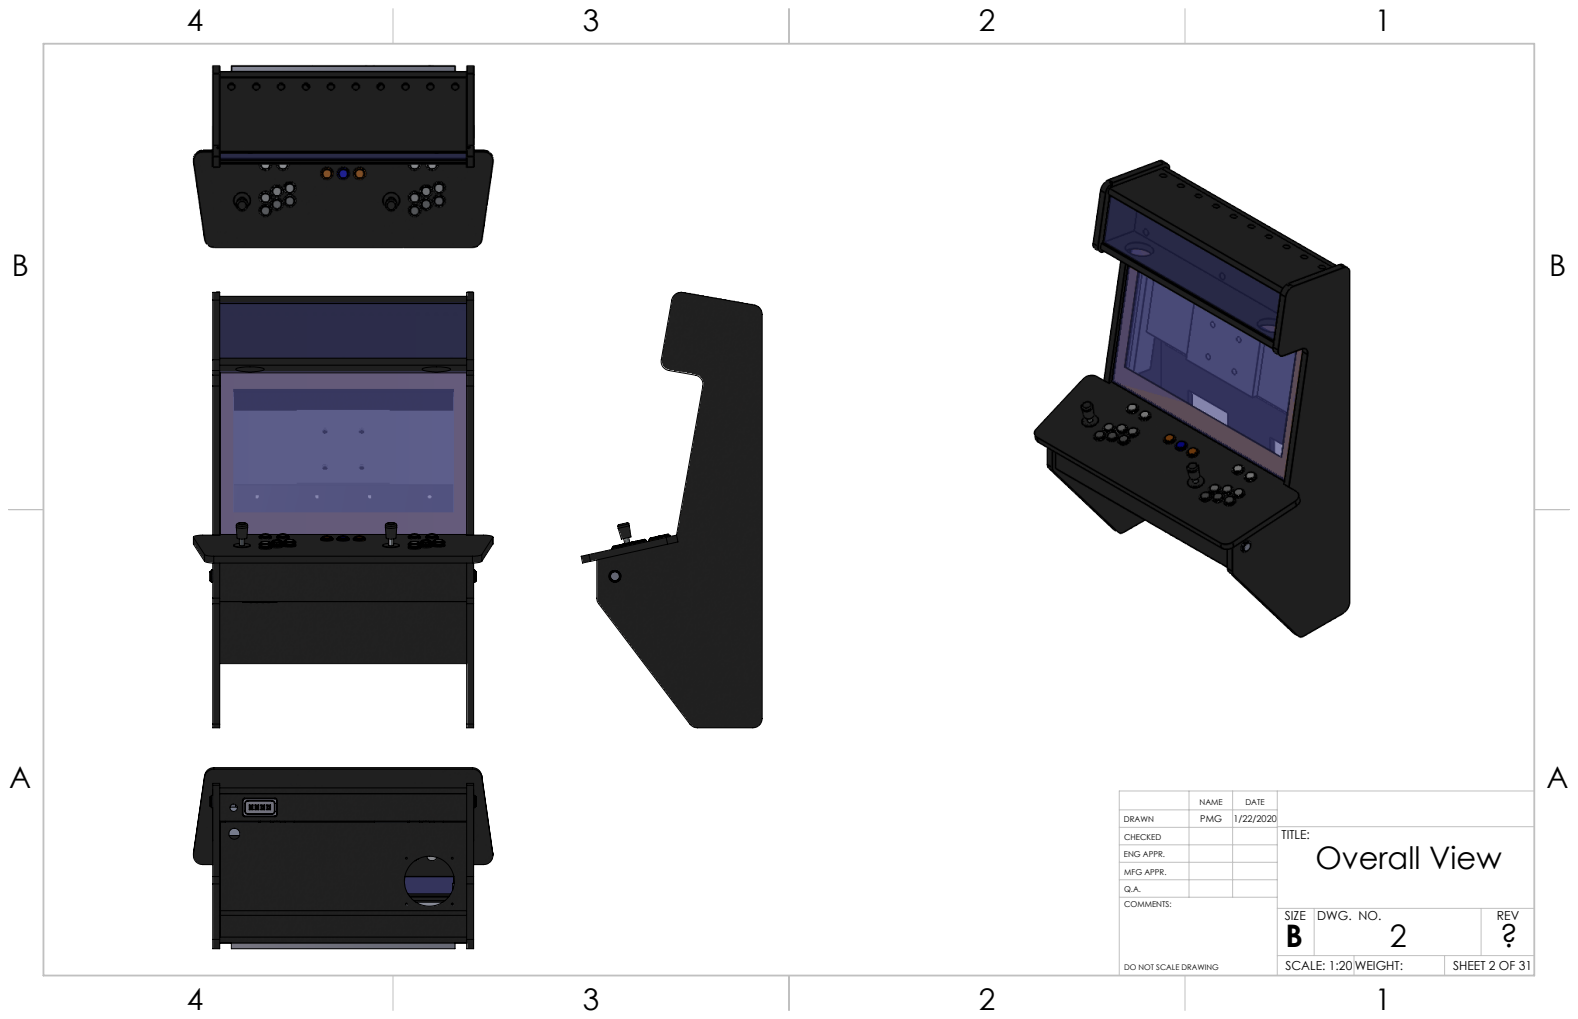
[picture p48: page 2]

NAME | DATE
CHECKED | | | TITLE: Overall View

DRAWN | PMG | 1/22/2020

ENG APPR.
MFG APPR.
Q.A.

SIZE B | DWG. NO. 2 | REV ?

SCALE: 1:20 WEIGHT:

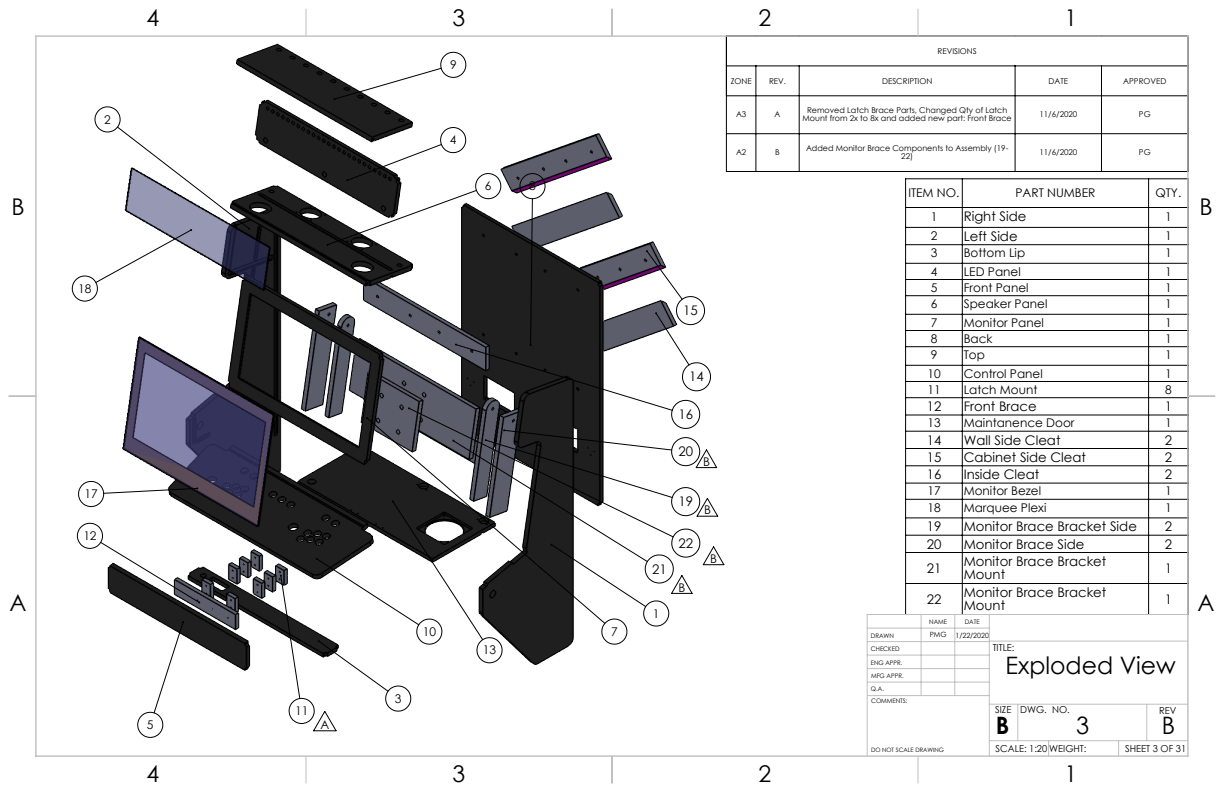
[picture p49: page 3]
ITEM NO.; PART NUMBER; QTY. 1; Right Side; Left Side; Bottom Lip; LED Panel; Front Panel; Speaker Panel; Monitor Panel; Back; Top

REVISIONS

ZONE | REV. | DESCRIPTION | DATE | APPROVED

A3 | A | Removed Latch Brace Parts, Changed Qty of Latch Mount from 2x to 8x and added new part: Front Brace | 11/6/2020 | PG

A2 | B | Added Monitor Brace Components to Assembly (19-22) | 11/6/2020 | PG

10 | Control Panel | 1
11 | Latch Mount | 8
12 | Front Brace | 1
13 | Maintanence Door | 1
14 | Wall Side Cleat | 2
15 | Cabinet Side Cleat | 2
16 | Inside Cleat | 2
17 | Monitor Bezel | 1
18 | Marquee Plexi | 1
19 | Monitor Brace Bracket Side | 2
20 | Monitor Brace Side | 2
21 | Monitor Brace Bracket Mount | 1
22 | Monitor Brace Bracket Mount | 1
CHECKED | | | TITLE: Exploded ViewB

NAME | DATE

DRAWN | PMG | 1/22/2020

ENG APPR.
MFG APPR.
Q.A.

SIZE B | DWG. NO. 3 | REV

SCALE: 1:20 WEIGHT:

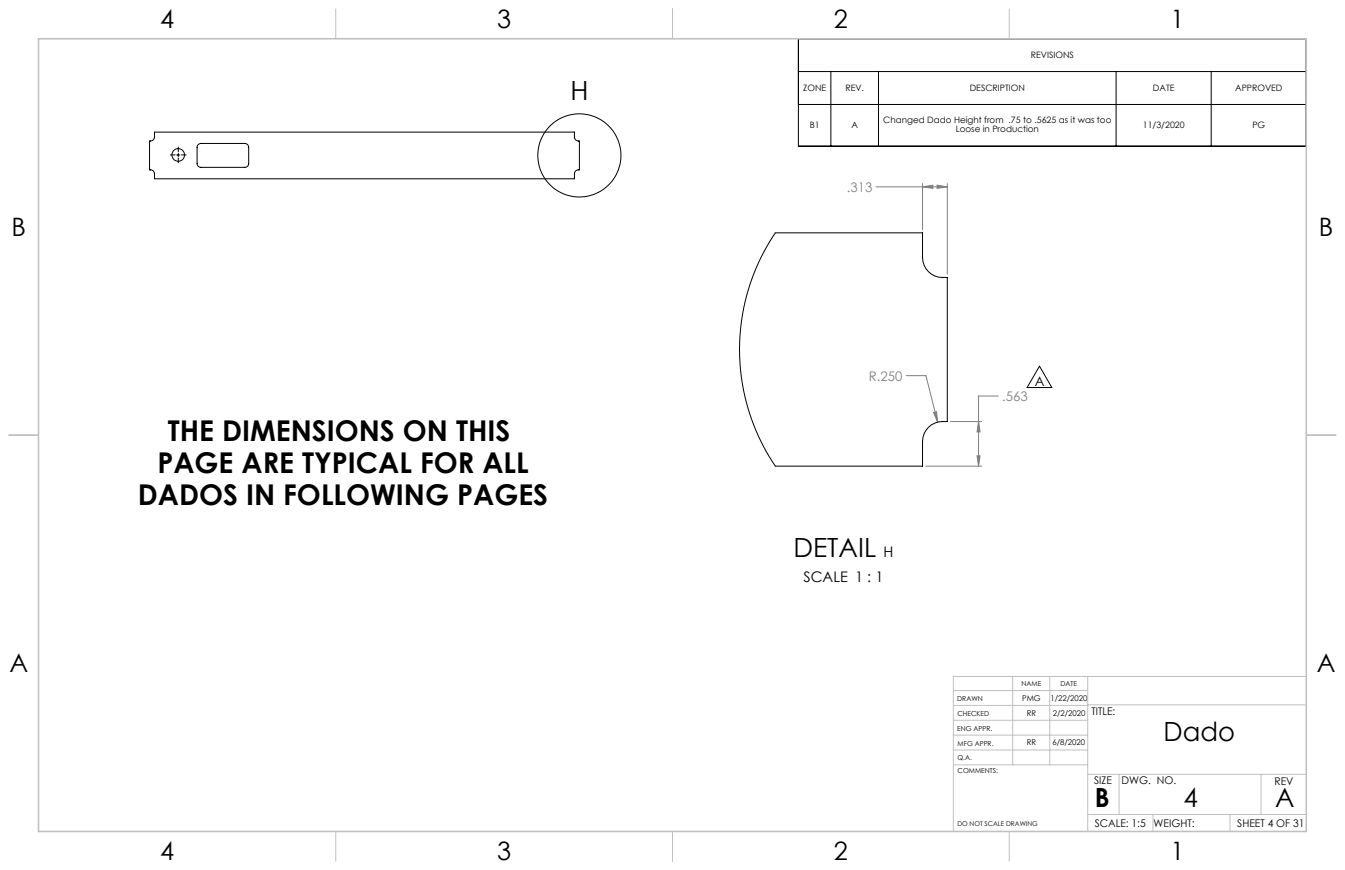
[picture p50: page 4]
DETAIL H; SCALE 1 : 1

ZONE | REV. | DESCRIPTION | DATE | APPROVED

B1 | A | Changed Dado Height from .75 to .5625 as it was too Loose in Production | 11/3/2020 | PG

THE DIMENSIONS ON THIS
PAGE ARE TYPICAL FOR ALL
DADOS IN FOLLOWING PAGES

NAME | DATE
CHECKED | RR | 2/2/2020 | TITLE: Dado

DRAWN | PMG | 1/22/2020

ENG APPR.
MFG APPR. | RR | 6/8/2020
Q.A.

SIZE B | DWG. NO. 4 | REV A

SCALE: 1:5 | WEIGHT:

T-Mold Cut for all Tanget Edges Post CNC

ZONE | REV. | DESCRIPTION | DATE | APPROVED

A4, B4 | A | Added Button Hole and Extended Marquee Slot to top of Part | 2/13/2020 | PG

B4 | B | ADDED NO T-MOLD CUT NOTE | 2/6/2026 | PG

NO T-MOLD CUT

NAME | DATE
CHECKED | RR | 2/2/2020 | TITLE: Left Side

DRAWN | PMG | 1/22/2020

ENG APPR.
MFG APPR. | RR | 6/8/2020
Q.A. | PMG | 10/7/2020

SIZE B | DWG. NO. 5 | REV A

SCALE: 1:20 WEIGHT:

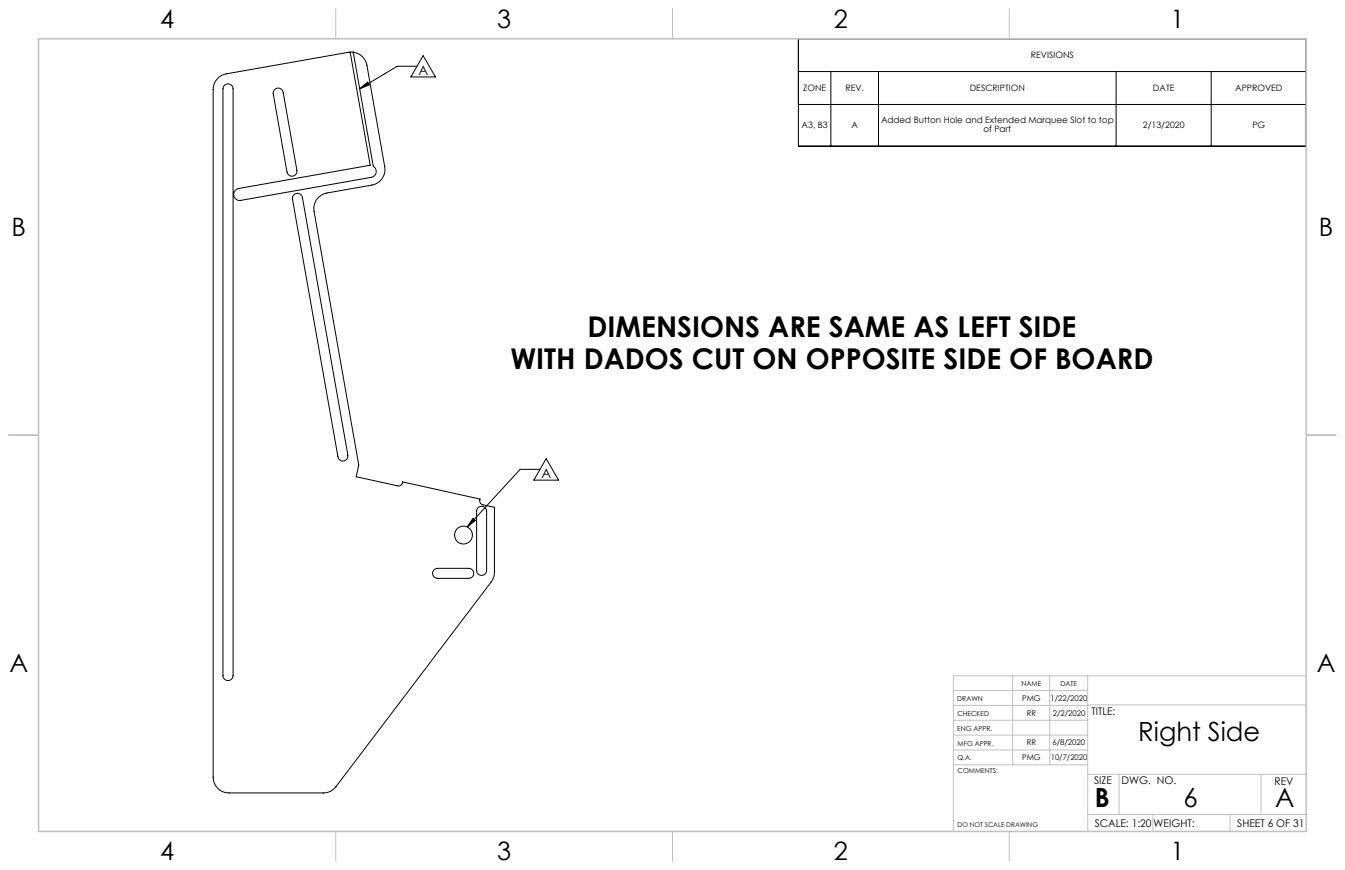
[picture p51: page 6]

ZONE | REV. | DESCRIPTION | DATE | APPROVED

A3, B3 | A | Added Button Hole and Extended Marquee Slot to top of Part | 2/13/2020 | PG

DIMENSIONS ARE SAME AS LEFT SIDE
WITH DADOS CUT ON OPPOSITE SIDE OF BOARD

NAME | DATE
CHECKED | RR | 2/2/2020 | TITLE: Right Side

DRAWN | PMG | 1/22/2020

ENG APPR.
MFG APPR. | RR | 6/8/2020
Q.A. | PMG | 10/7/2020

SIZE B | DWG. NO. 6 | REV A

SCALE: 1:20 WEIGHT:

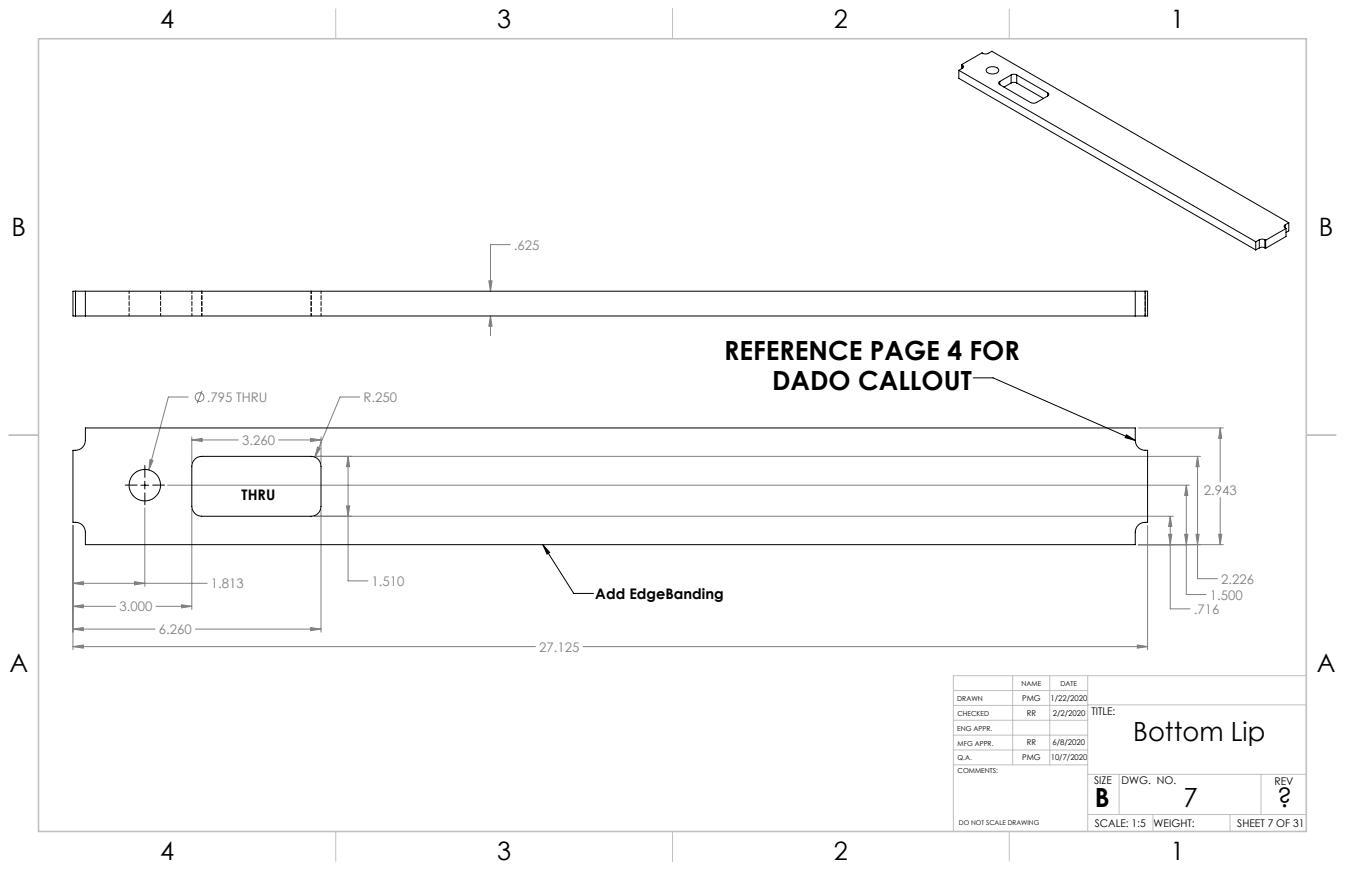
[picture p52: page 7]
.795 THRU; Add EdgeBanding; DWG. NO.; REV

REFERENCE PAGE 4 FOR
DADO CALLOUT

NAME | DATE
CHECKED | RR | 2/2/2020 | TITLE: Bottom Lip

DRAWN | PMG | 1/22/2020

ENG APPR.
MFG APPR. | RR | 6/8/2020
Q.A. | PMG | 10/7/2020

ZONE | REV. | DESCRIPTION | DATE | APPROVED

A2, A4, B3, B4 | A | Changed Hole Diameter from .5 to .75, Changed the Location of all Holes Vertically and the Right Hole Horizontally, Added 3rd Hole on the Left Side | 11/3/2020 | PG

REFERENCE PAGE 4 FOR
DADO CALLOUT

NAME | DATE
CHECKED | RR | 2/2/2020 | TITLE: LED Panel

DRAWN | PMG | 1/22/2020

ENG APPR.
MFG APPR. | RR | 6/8/2020
Q.A. | 10/7/202010/7/2020

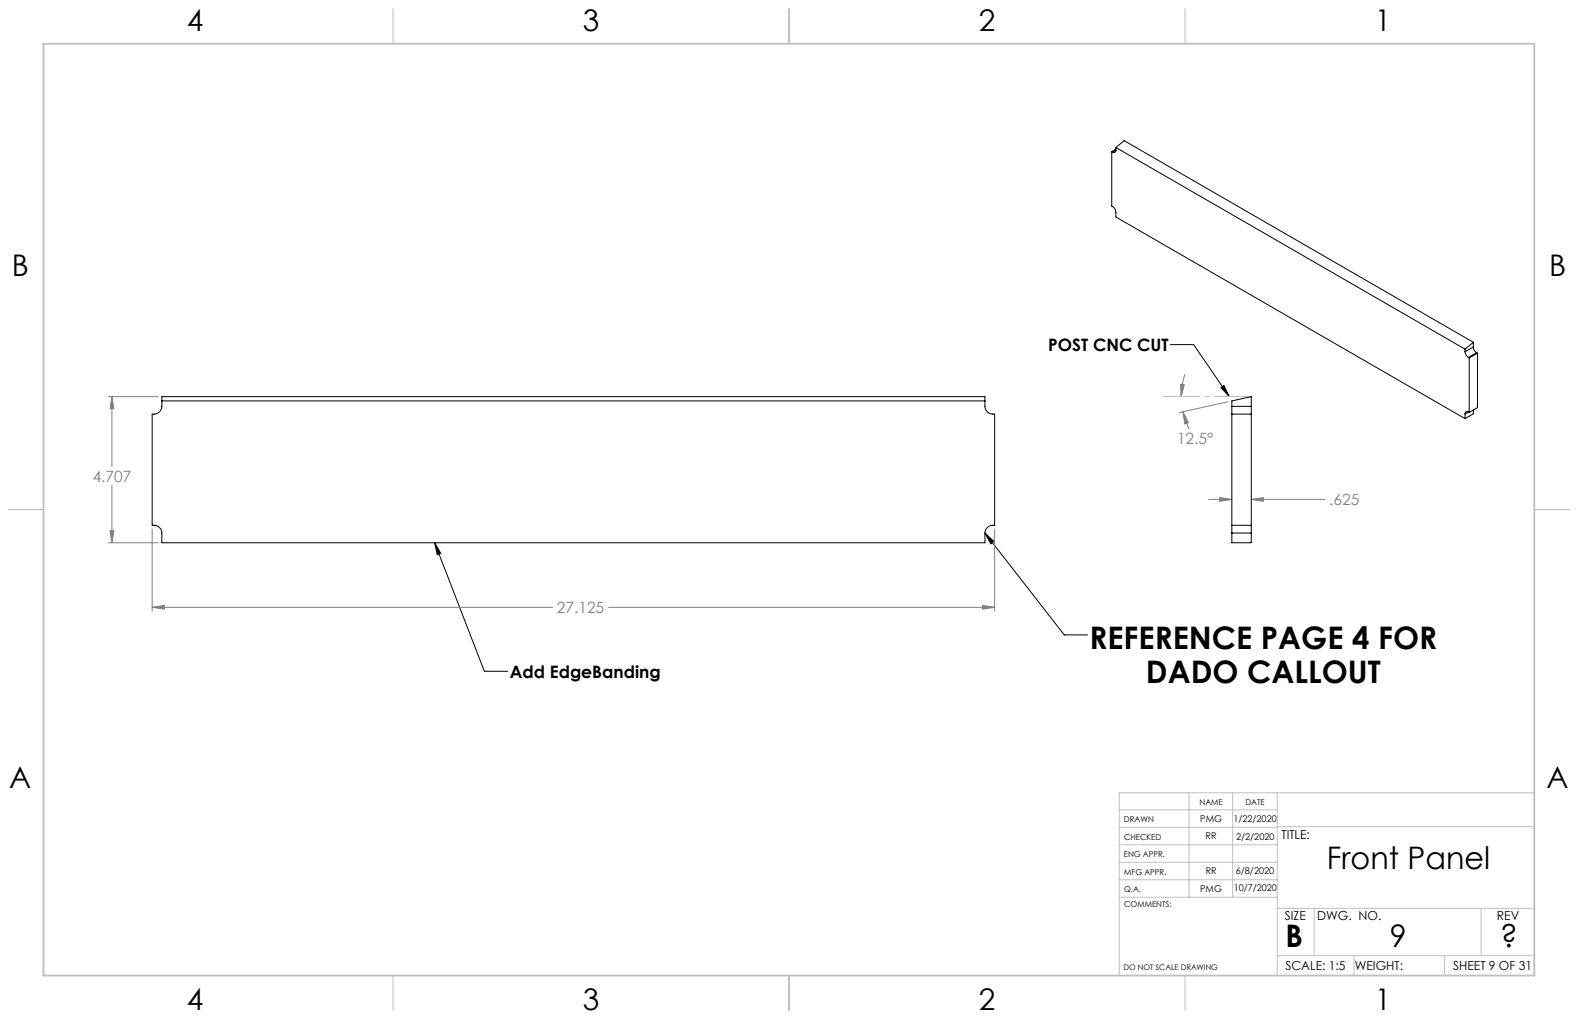
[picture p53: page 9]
Add EdgeBanding; DADO CALLOUT; DWG. NO.; REV

POST CNC CUT

REFERENCE PAGE 4 FOR

NAME | DATE
CHECKED | RR | 2/2/2020 | TITLE: Front Panel

DRAWN | PMG | 1/22/2020

ENG APPR.
MFG APPR. | RR | 6/8/2020
Q.A. | PMG | 10/7/2020
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

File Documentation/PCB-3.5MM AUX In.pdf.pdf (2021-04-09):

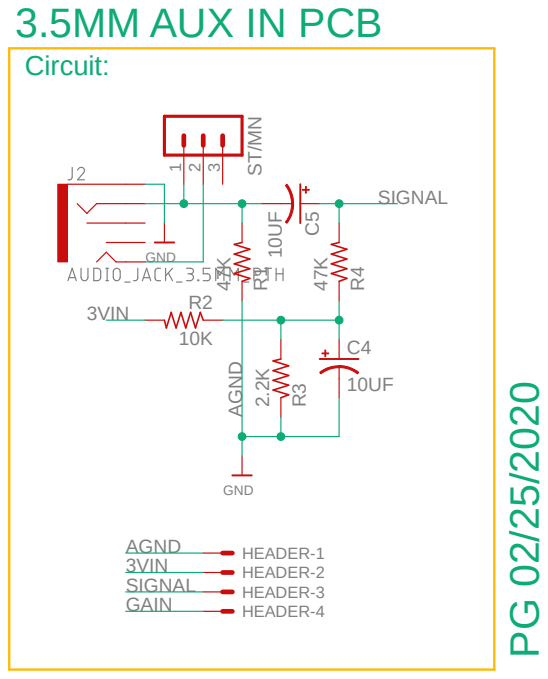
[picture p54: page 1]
10UF ¹⁰UF; GND; HEADER-1 HEADER-2 HEADER-3; HEADER-4 R¹; AGND; SIGNAL; GAIN; 3VIN

3.5MM AUX IN PCB
Circuit:

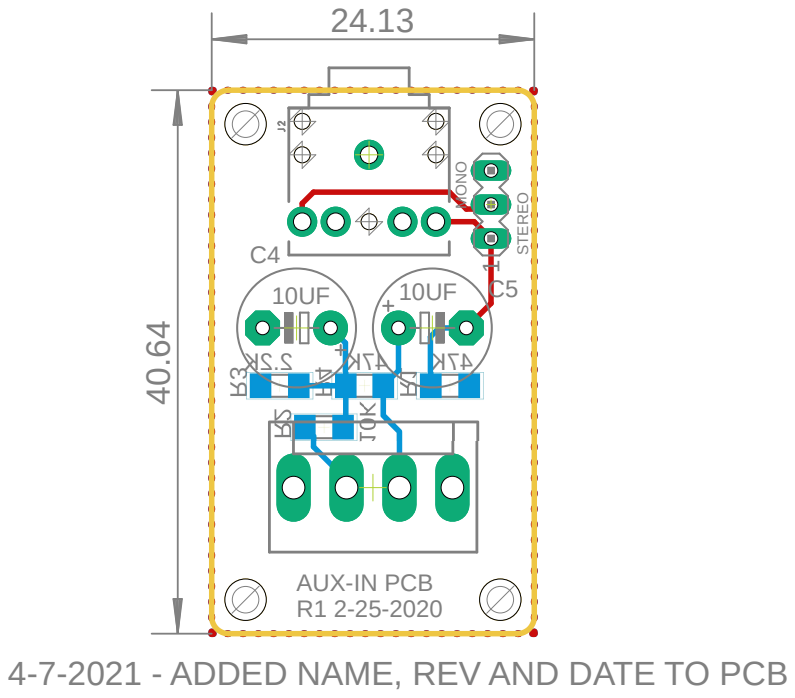
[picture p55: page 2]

AUX-IN PCB

4-7-2021 - ADDED NAME, REV AND DATE TO PCB

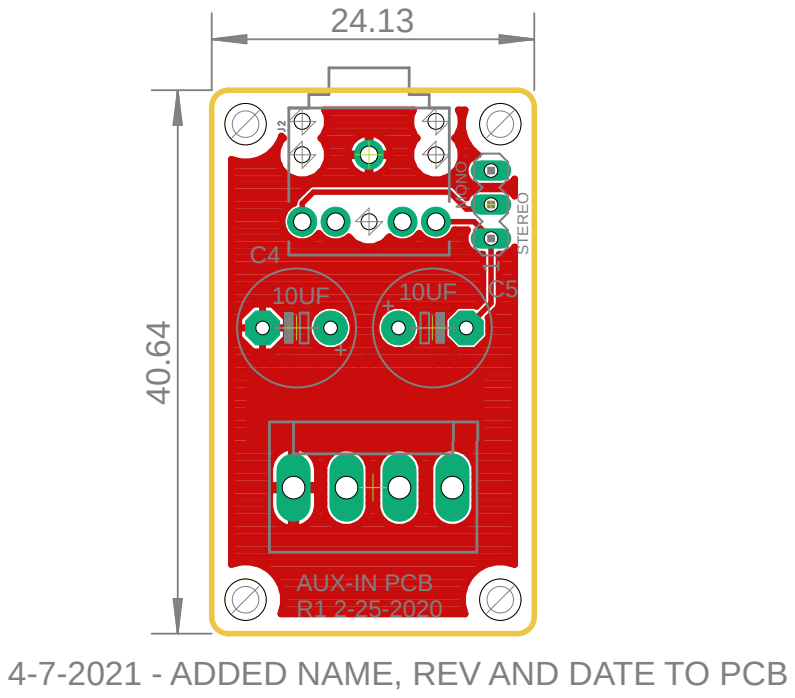
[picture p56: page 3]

AUX-IN PCB

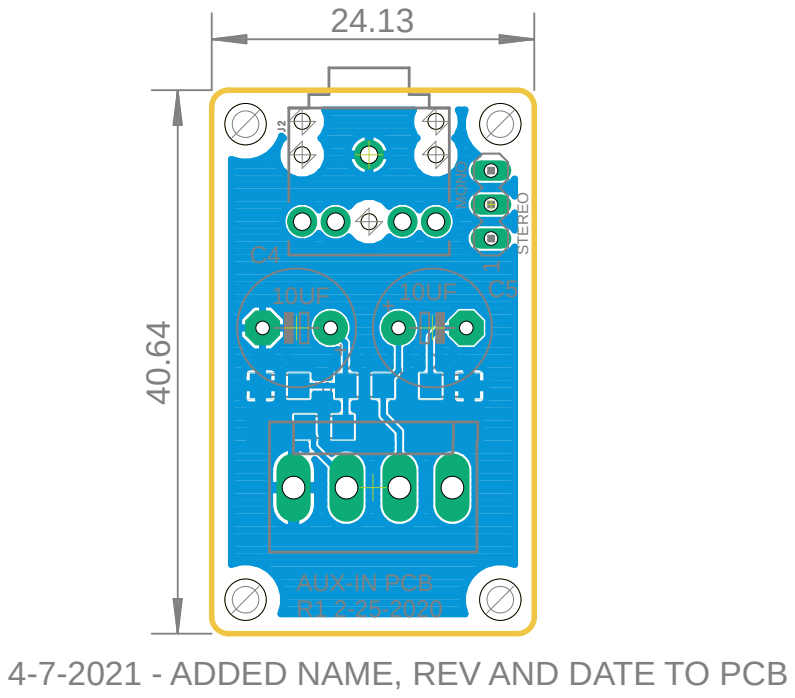
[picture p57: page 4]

AUX-IN PCB

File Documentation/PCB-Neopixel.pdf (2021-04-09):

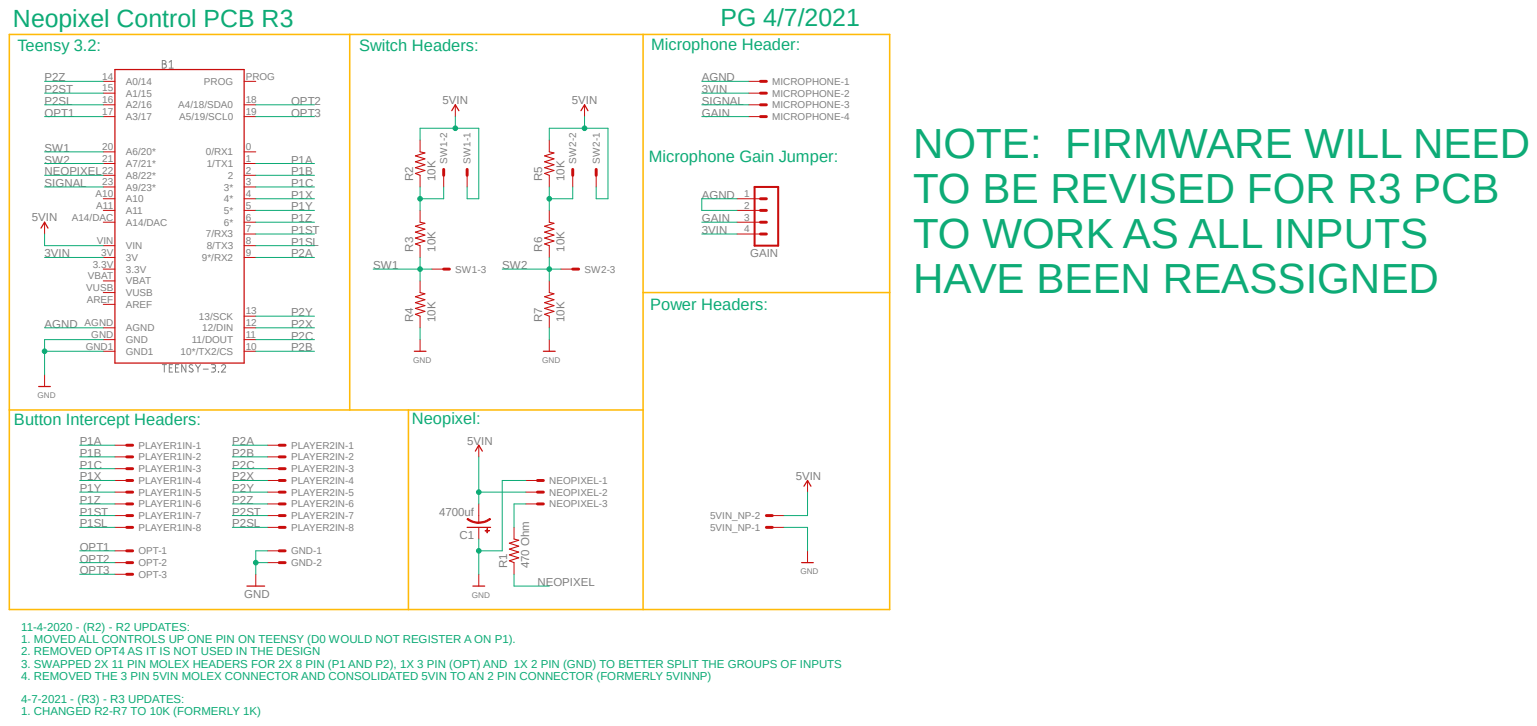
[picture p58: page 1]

MICROPHONE-1
MICROPHONE-2
MICROPHONE-3
MICROPHONE-4
NOTE: FIRMWARE WILL NEED
TO BE REVISED FOR R3 PCB
TO WORK AS ALL INPUTS
HAVE BEEN REASSIGNED

11-4-2020 - (R2) - R2 UPDATES:
1. MOVED ALL CONTROLS UP ONE PIN ON TEENSY (D0 WOULD NOT REGISTER A ON P1).
2. REMOVED OPT4 AS IT IS NOT USED IN THE DESIGN
3. SWAPPED 2X 11 PIN MOLEX HEADERS FOR 2X 8 PIN (P1 AND P2), 1X 3 PIN (OPT) AND 1X 2 PIN (GND) TO BETTER SPLIT THE GROUPS OF INPUTS
4. REMOVED THE 3 PIN 5VIN MOLEX CONNECTOR AND CONSOLIDATED 5VIN TO AN 2 PIN CONNECTOR (FORMERLY 5VINNP)
4-7-2021 - (R3) - R3 UPDATES:
1. CHANGED R2-R7 TO 10K (FORMERLY 1K)

# R4 SW²

R1 - 470 Ohm; NEOPIXEL 5VIN_NP SW¹; R7 MICROPHONE; GAIN PLAYER¹IN; PLAYER²IN; OPT; GND

Neopixel Control Board R3 4/7/21

11-4-2020 - (R2) - R2 UPDATES:
1. MOVED ALL CONTROLS UP ONE PIN ON TEENSY
(D0 WOULD NOT REGISTER A ON P1).
2. REMOVED OPT4 AS IT IS NOT USED IN THE DESIGN
3. SWAPPED 2X 11 PIN MOLEX HEADERS FOR 2X 8 PIN (P1 AND P2),
1X 3 PIN (OPT) AND 1X 2 PIN (GND) TO BETTER SPLIT THE GROUPS OF INPUTS
4. REMOVED THE 3 PIN 5VIN MOLEX CONNECTOR AND CONSOLIDATED 5VIN TO
AN 2 PIN CONNECTOR (FORMERLY 5VINNP)
5. ALL INPUT TRACES RERUN, STICHING RERUN TO MATCH NEW TRACES
4-7-2021 - (R3) - R3 UPDATES:
1. CHANGED R2-R7 TO 10K (FORMERLY 1K)
2. ADDED COMPONENT VALUES TO PCB

# R4 SW²

R1 - 470 Ohm; NEOPIXEL 5VIN_NP SW¹; R7 MICROPHONE; GAIN PLAYER¹IN; PLAYER²IN; OPT; GND

Neopixel Control Board R3 4/7/21

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

# R4 SW²

R1 - 470 Ohm; NEOPIXEL 5VIN_NP SW¹; R7 MICROPHONE; GAIN PLAYER¹IN; PLAYER²IN; OPT; GND

Neopixel Control Board R3 4/7/21

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

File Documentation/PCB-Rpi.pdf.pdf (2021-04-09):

GND; IOTPSU-1 IOTPSU-2 SW1-1 SW1-2 SW1-3; RELAY; Raspberry Pi Header (2x6); Switch Headers:; Raspberry Pi Switch Mini-Hat

12 SW¹; IOTPSU SW² ³⁴.29

12 SW¹; IOTPSU SW² ³⁴.29

12 SW¹; IOTPSU SW² ³⁴.29

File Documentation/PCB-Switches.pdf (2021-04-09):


11-4-2020 - (R2) - ADDED JUMPERS TO ALLOW SWITCHING BETWEEN 5V AND GN, ENABLING
COMPATIBILITY ON ALL SWITCHES TO ALL PCBS IN ARCADE (AUX/NEOPIXEL/RPI)

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

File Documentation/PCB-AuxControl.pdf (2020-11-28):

## Teensy 3.2:

Fan Relays: | Marquee Header:

SpiceOrder 2; SpiceOrder 1; SpiceOrder 1 NPN2222A; VIN; GND; 5VIN; NPN2222A; 12VIN; GND1 GND1; GND GND; VBAT VBAT; VIN VIN; AGND AGND; A4/18/SDA0; A5/19/SCL0; 10 11/DOUT; 11 12/DIN; 12 13/SCK; A10 A10 A11 A11 A14/DAC A14/DAC; AREF AREF; VUSB VUSB; PROG; UPPERTEMP-1 UPPERTEMP-2; UPPERTEMP-3 UPPERFAN⁻¹; UPPERFAN⁻² LOWERFAN⁻¹; LOWERFAN⁻²; LOWERTEMP-1 LOWERTEMP-2 LOWERTEMP-3; SWITCHA-1 SWITCHA-2 SWITCHA-3; 5VIN-1; 5VIN-2; 12VIN-1; 12VIN-2; SWITCHB-1 SWITCHB-2 SWITCHB-3; MARQUEE-1; MARQUEE-2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

11-4-2020 - (R2) - CHANGED MARQUEE MOLEX CONNECTOR FROM 2 PIN TO 3 PIN TO ADD 5V TO THE PLUG.

2

1 3 | 2

Auxiliary Control Board R² ¹¹/4/2020 D1; T2 LOWERFAN; UPPERFAN LOWERTEMP; UPPERTEMP SWITCHA; 5VIN; 12VIN SWITCHB; MARQUEE

11-4-2020 - (R2) - CHANGED MARQUEE
MOLEX FROM 2 PIN TO 3 PIN TO ADD
5V TO HEADER. 5VIN WAS CHANGED
FROM .8068 THICKNESS TO 1.27 FOR
ADDITIONAL POWER NEEDS

2

1 3 | 2

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

2

1 3 | 2

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

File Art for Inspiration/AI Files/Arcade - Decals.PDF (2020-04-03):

ITEM NO.; PART NUMBER; Thickness; Material; Overall Size Dado Post CNC QTY.; Right Side; MDF; 46.888 x 17.750 Yes; Left Side; Bottom Lip; 2.943 x 27.125 Yes; LED Panel; 6.625 x 27.125 Yes; Front; 4.707 x 27.125 Yes; Yes; Speaker Panel; 9.358 x 27.125 Yes; Monitor Panel; 17.500 x 27.125 Yes; Back; 38.000 x 27.125 Yes; Top; Control Panel; 11.790 x 32.448 Yes; Latch Brace; Latch Mount; Bottom/Maintenance; Cleat; PLYWOOD 4.000 X 26.000 No; Wall Side Cleat; Monitor Bezel; PLEXI; Marquee Plexi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

UNLESS OTHERWISE SPECIFIED: | | NAME | DATE
DIMENSIONS ARE IN INCHES TOLERANCES: FRACTIONAL ANGULAR: MACH BEND TWO PLACE DECIMAL THREE PLACE DECIMAL | DRAWN | PMG | 1/22/2020

CHECKED | | | TITLE: Arcade Cover

ENG APPR.
MFG APPR.

INTERPRET GEOMETRIC TOLERANCING PER: | Q.A.
MATERIAL | | SIZE B | DWG. NO. 1 | REV ?

PROPRIETARY AND CONFIDENTIAL
THE INFORMATION CONTAINED IN THIS
DRAWING IS THE SOLE PROPERTY OF
<INSERT COMPANY NAME HERE>. ANY
REPRODUCTION IN PART OR AS A WHOLE
WITHOUT THE WRITTEN PERMISSION OF
<INSERT COMPANY NAME HERE> IS
PROHIBITED.

NEXT ASSY | USED ON | FINISH

APPLICATION | DO NOT SCALE DRAWING | | SCALE: 1:20 WEIGHT: | | SHEET 1 OF 27

DWG. NO.; REV

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

CHECKED | | | TITLE: Overall View

ENG APPR.
MFG APPR.

INTERPRET GEOMETRIC TOLERANCING PER: | Q.A.

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

DWG. NO.; REV

ITEM NO. | PART NUMBER | QTY.
1 | Right Side | 1
2 | Left Side | 1
3 | Bottom Lip | 1
4 | LED Panel | 1
5 | Front Panel | 1
6 | Speaker Panel | 1
7 | Monitor Panel | 1
8 | Back | 1
9 | Top | 1
10 | Control Panel | 1
11 | Latch Brace | 2
12 | Latch Mount | 2
13 | Maintanence Door | 1
14 | Wall Side Cleat | 2
15 | Cabinet Side Cleat | 2
16 | Inside Cleat | 2
17 | Monitor Bezel | 1
18 | Marquee Plexi | 1
19 | Button | 2

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

CHECKED | | | TITLE: Exploded View

ENG APPR.
MFG APPR.

INTERPRET GEOMETRIC TOLERANCING PER: | Q.A.

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

R1.000 TYP; 2X 1.378 THRU; 20X 1.125 THRU; DETAIL D; SCALE 2 : 5; DETAIL E; DETAIL F; DETAIL M; SCALE 1 : 1; SCALE: 1:5; WEIGHT:; DWG. NO.; REV

REVISIONS

ZONE | REV. | DESCRIPTION | DATE | APPROVED

A4, B3 | A | Reduced Holes from 4 to 3 and Chagned Spacing to be Centered/Symmetric | 2/13/2020 | PG

POST CNC CUT

T-Mold Cut for all Tanget Edges Post CNC

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

CHECKED | RR | 2/2/2020 | TITLE: Control Panel

ENG APPR.
MFG APPR.

INTERPRET GEOMETRIC TOLERANCING PER: | Q.A.

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

.313 TYP; .625 TYP; DWG. NO.; REV

REVISIONS

ZONE | REV. | DESCRIPTION | DATE | APPROVED
B1, B3 | A | Control Panel - Changed Middle Buttons from 4x to 3x, Sides - Added Buttons for Pinball Games | 2/22/2020

INSIDE DOTTED LINE IS
THE VISIBLE AREA

OUTSIDE DOTTED LINE
WILL BE FOLDED UNDER
T-MOLDING

IS VISIBLE AREA

INSIDE DOTTED LINE
IS SOLID BLACK AND
WILL BE WRAPPED AROUND
OPENING

ALL CIRCLES WILL BE CUT
THROUGH DECAL FOR
BUTTONS AND JOYSTICK

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

WILL BE IN MOUNTING
SLOT

CHECKED | | | TITLE: Art

ENG APPR.
MFG APPR.

INTERPRET GEOMETRIC TOLERANCING PER: | Q.A.

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

INSIDE DOTTED LINE IS VISIBLE AREA

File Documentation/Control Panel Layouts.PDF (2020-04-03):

DOWN RIGHT; Neopixel Layout; Keyboard Layout

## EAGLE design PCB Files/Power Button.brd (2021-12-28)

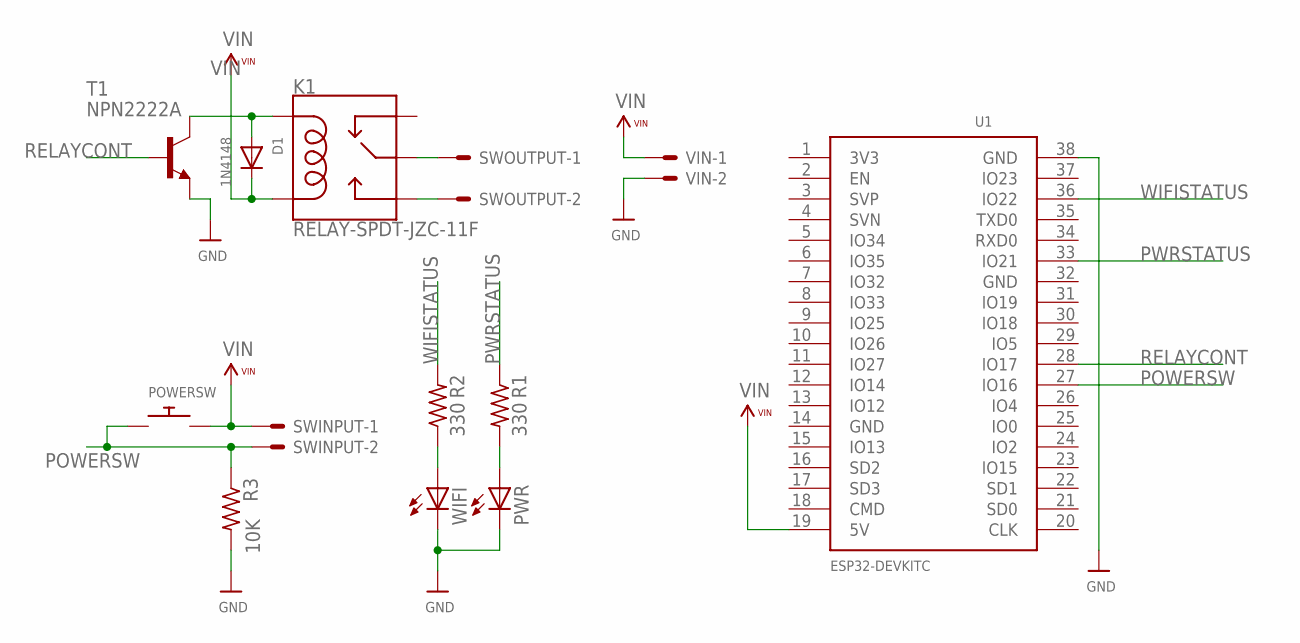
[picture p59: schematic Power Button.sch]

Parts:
D1: 1N4148; DO-1N4148
K1: RELAY-SPDT-JZC-11F; RELAY-JZC
POWERSW: SWITCH_PUSHBUTTONEVQ-PE; TACT_PANA-EVQ
PWR: LEDCHIPLED_1206; CHIPLED_1206
R1, R2: 330; M1206
R3: 10K; M1206
SWINPUT: KK-156-2
SWOUTPUT: KK-156-2
T1: NPN2222A; TO92
U1: ESP32DEVKITC; ESP32-DEVKITC
VIN: KK-156-2
WIFI: LEDCHIPLED_1206; CHIPLED_1206

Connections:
GND: PWR.C, R3.2, T1.3 (E), U1.38 (GND), VIN.2, WIFI.C
unnamed: R2.1, WIFI.A
unnamed: PWR.A, R1.2
POWERSW: POWERSW.P$1, R3.1, SWINPUT.2, U1.27 (IO16)
PWRSTATUS: R1.1, U1.33 (IO21)
RELAY1: K1.4 (MAIN), SWOUTPUT.1
RELAY2: K1.3 (NO), SWOUTPUT.2
RELAYCONT: T1.2 (B), U1.28 (IO17)
RELAYSW: D1.A, K1.5 (COIL1), T1.1 (C)
VIN: D1.C, K1.1 (COIL2), POWERSW.P$2, SWINPUT.1, U1.19 (5V), VIN.1
WIFISTATUS: R2.2, U1.36 (IO22)

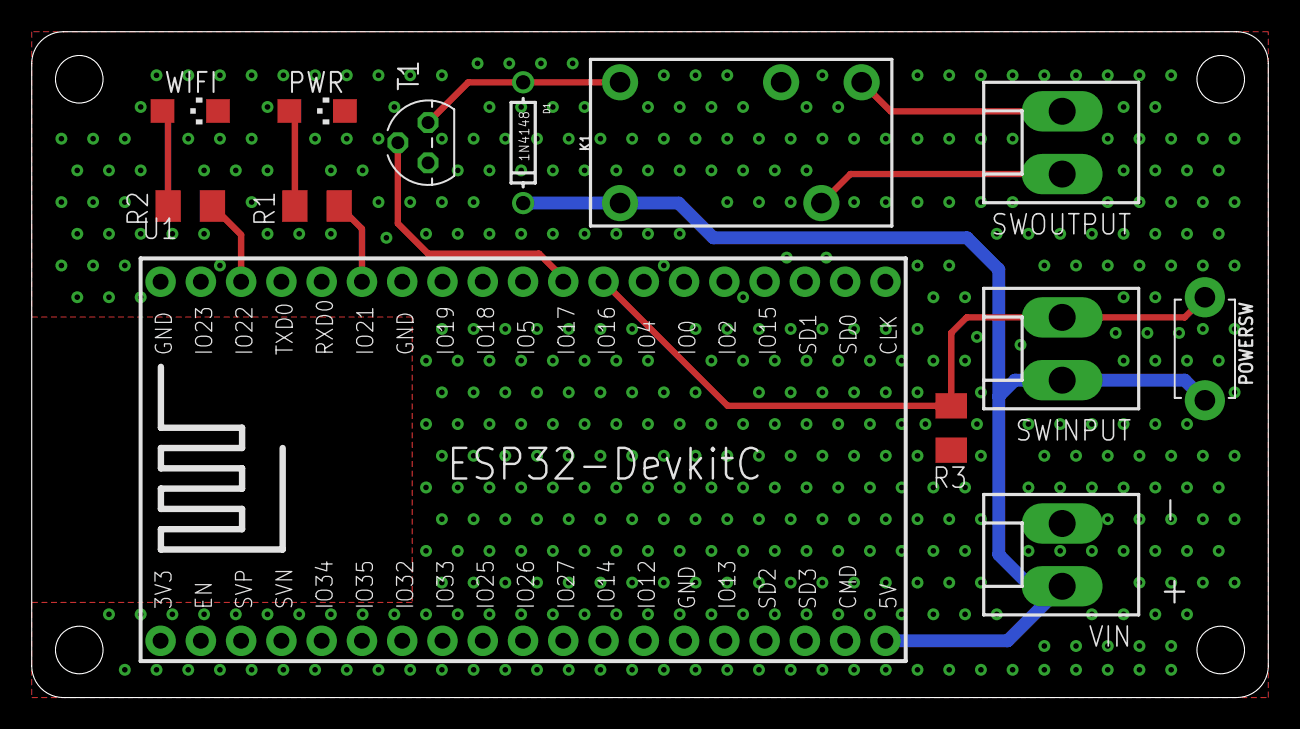
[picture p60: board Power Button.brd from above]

Board: 2 copper layers, 78.0 x 42.0 mm, 13 parts (0 on the bottom side), 11 nets.

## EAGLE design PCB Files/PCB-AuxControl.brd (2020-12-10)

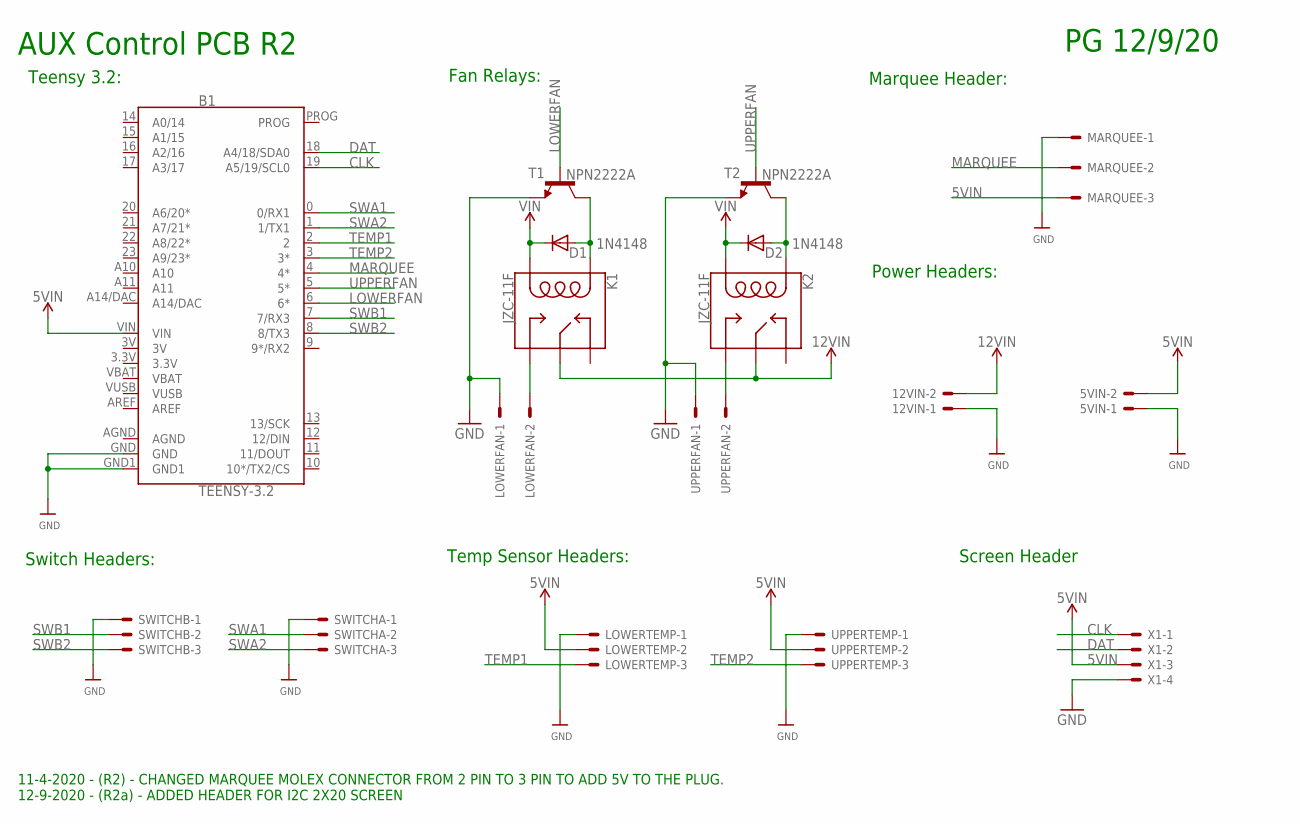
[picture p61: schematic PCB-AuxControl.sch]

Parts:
5VIN, 12VIN: KK-156-2
B1: TEENSY-3.2; TEENSY-3.1
D1, D2: 1N4148; DO35-7
K1, K2: JZC-11F; RELAY-JZC
LOWERFAN: KK-156-2
LOWERTEMP: KK-156-3
MARQUEE: KK-156-3
SWITCHA: KK-156-3
SWITCHB: KK-156-3
T1, T2: NPN2222A; TO92
UPPERFAN: KK-156-2
UPPERTEMP: KK-156-3
X1: KK-156-4

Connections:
3.3V: B1.3.3V
3V: B1.3V
5VIN: 5VIN.2, B1.VIN, D1.C, D2.C, K1.1 (COIL2), K2.1 (COIL2), LOWERTEMP.2, MARQUEE.3, UPPERTEMP.2, X1.3
12VIN: 12VIN.2, K1.4 (MAIN), K2.4 (MAIN)
AGND: B1.AGND
CLK: B1.19 (A5/19/SCL0), X1.1
DAT: B1.18 (A4/18/SDA0), X1.2
GND: 5VIN.1, 12VIN.1, B1.GND, B1.GND1, LOWERFAN.1, LOWERTEMP.1, MARQUEE.1, SWITCHA.1, SWITCHB.1, T1.1 (E), T2.1 (E), UPPERFAN.1, UPPERTEMP.1, X1.4
LOWERFAN: B1.6 (6*), T1.2 (B)
MARQUEE: B1.4 (4*), MARQUEE.2
unnamed: K2.3 (NO), UPPERFAN.2
unnamed: K1.3 (NO), LOWERFAN.2
RELAY1: D1.A, K1.5 (COIL1), T1.3 (C)
RELAY2: D2.A, K2.5 (COIL1), T2.3 (C)
SWA1: B1.0 (0/RX1), SWITCHA.2
SWA2: B1.1 (1/TX1), SWITCHA.3
SWB1: B1.7 (7/RX3), SWITCHB.2
SWB2: B1.8 (8/TX3), SWITCHB.3
TEMP1: B1.2, LOWERTEMP.3
TEMP2: B1.3 (3*), UPPERTEMP.3
UPPERFAN: B1.5 (5*), T2.2 (B)
VBAT: B1.VBAT
VUSB: B1.VUSB

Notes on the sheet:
Teensy 3.2:
Switch Headers:
Temp Sensor Headers:
Power Headers:
Marquee Header:
Fan Relays:
AUX Control PCB R2
PG 12/9/20
11-4-2020 - (R2) - CHANGED MARQUEE MOLEX CONNECTOR FROM 2 PIN TO 3 PIN TO ADD 5V TO THE PLUG. 12-9-2020 - (R2a) - ADDED HEADER FOR I2C 2X20 SCREEN
Screen Header

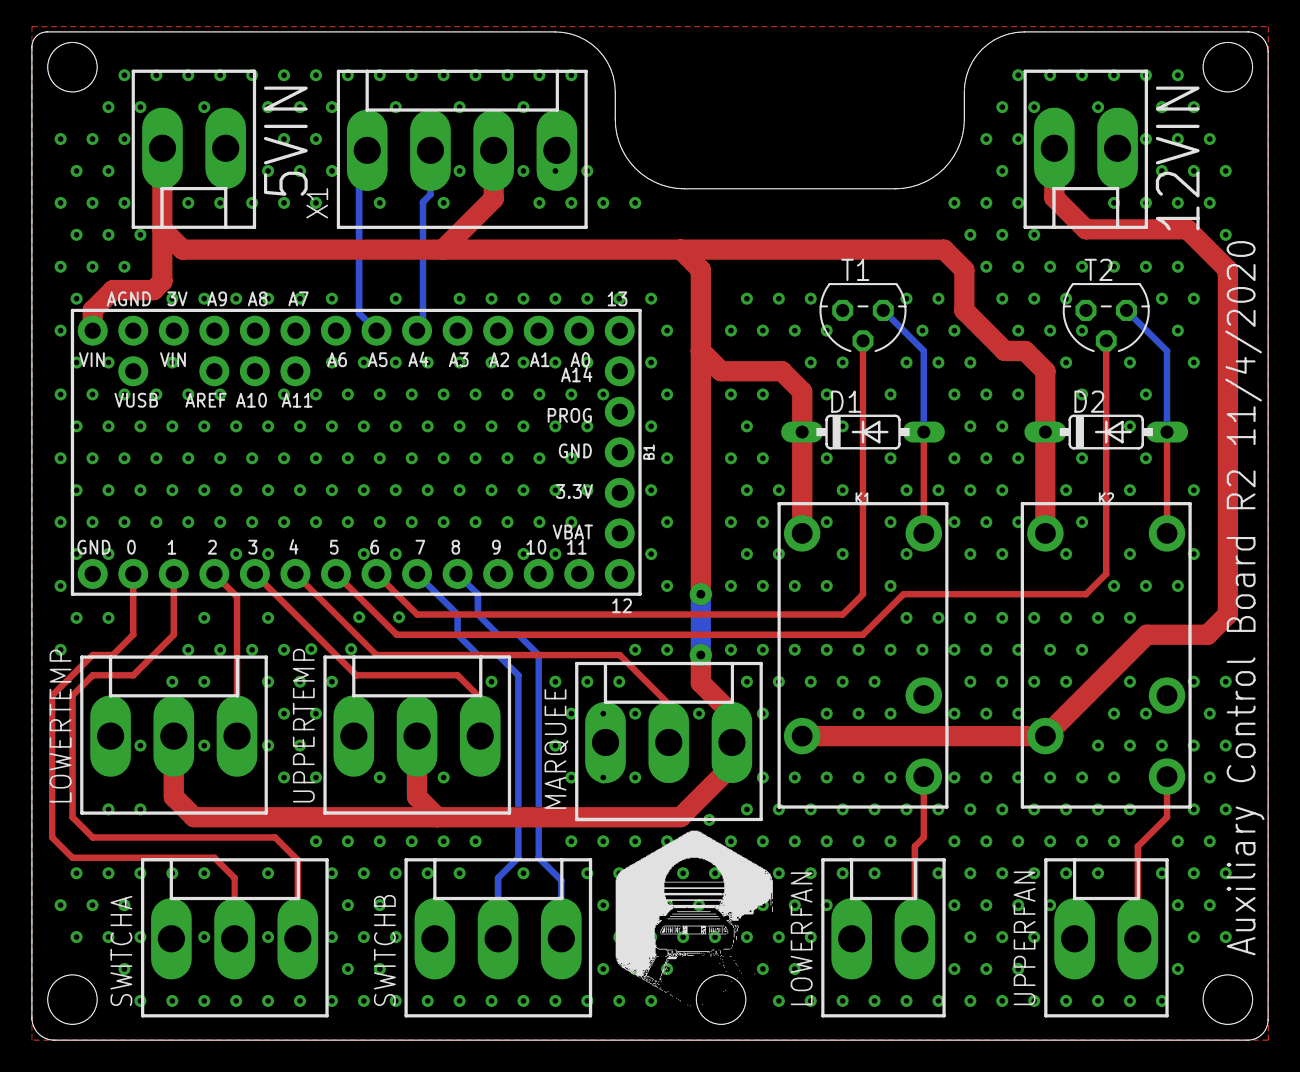
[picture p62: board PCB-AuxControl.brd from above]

Board: 2 copper layers, 77.5 x 63.2 mm, 17 parts (0 on the bottom side), 18 nets.

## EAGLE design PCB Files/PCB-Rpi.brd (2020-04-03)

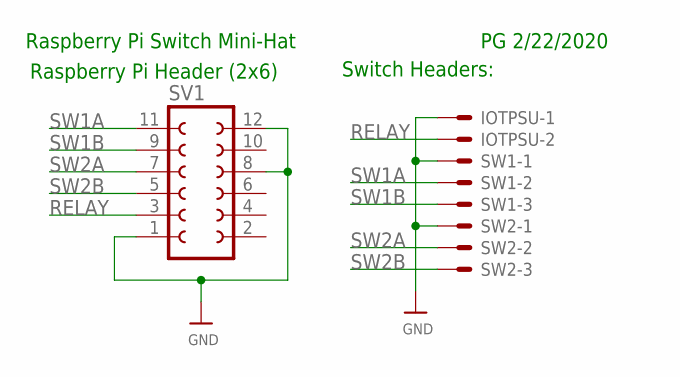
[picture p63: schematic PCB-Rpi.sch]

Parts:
IOTPSU: KK-156-2
SV1: FE06-2
SW1, SW2: KK-156-3

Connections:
GND: IOTPSU.1, SV1.1, SV1.8, SV1.12, SW1.1, SW2.1
RELAY: IOTPSU.2, SV1.3
SW1A: SV1.11, SW1.2
SW1B: SV1.9, SW1.3
SW2A: SV1.7, SW2.2
SW2B: SV1.5, SW2.3

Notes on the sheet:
Switch Headers:
Raspberry Pi Header (2x6)
Raspberry Pi Switch Mini-Hat
PG 2/22/2020

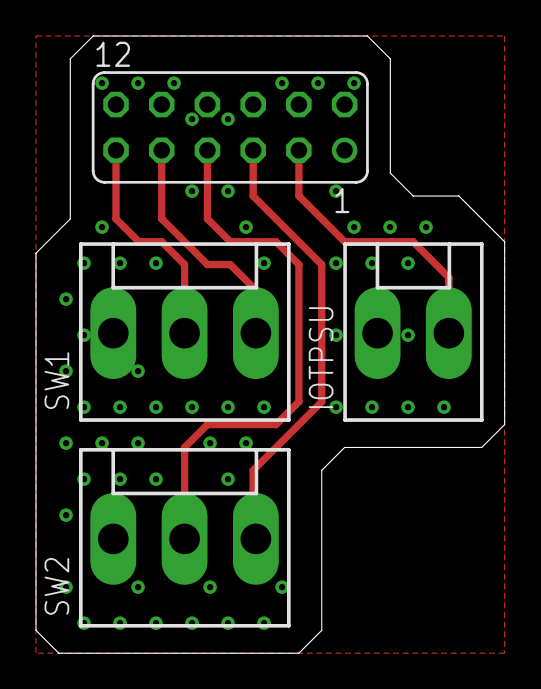
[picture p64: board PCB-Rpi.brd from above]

Board: 2 copper layers, 26.0 x 34.3 mm, 4 parts (0 on the bottom side), 6 nets.

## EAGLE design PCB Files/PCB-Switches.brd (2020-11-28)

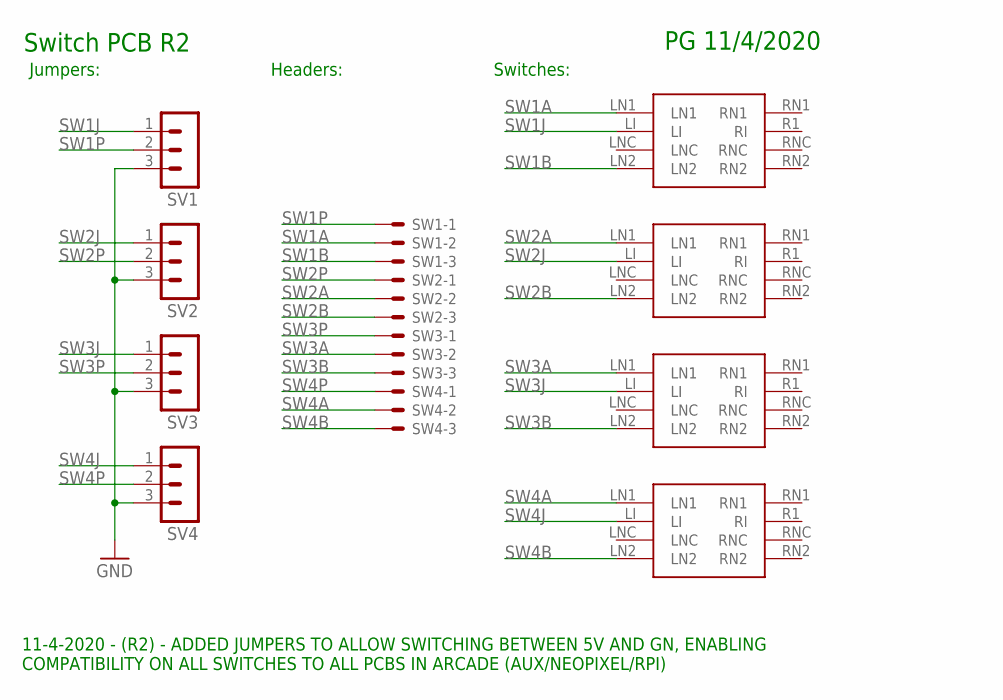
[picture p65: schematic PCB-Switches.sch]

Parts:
SV1, SV2, SV3, SV4: MA03-1
SW1, SW2, SW3, SW4: KK-156-3
U$1, U$2, U$3, U$4: ARCADESWITCH

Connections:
GND: SV1.3, SV2.3, SV3.3, SV4.3
SW1A: SW1.2, U$1.LN1
SW1B: SW1.3, U$1.LN2
SW1J: SV1.1, U$1.LI
SW1P: SV1.2, SW1.1
SW2A: SW2.2, U$2.LN1
SW2B: SW2.3, U$2.LN2
SW2J: SV2.1, U$2.LI
SW2P: SV2.2, SW2.1
SW3A: SW3.2, U$3.LN1
SW3B: SW3.3, U$3.LN2
SW3J: SV3.1, U$3.LI
SW3P: SV3.2, SW3.1
SW4A: SW4.2, U$4.LN1
SW4B: SW4.3, U$4.LN2
SW4J: SV4.1, U$4.LI
SW4P: SV4.2, SW4.1

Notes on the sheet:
Switches:
Headers:
Switch PCB R2
PG 11/4/2020
Jumpers:
11-4-2020 - (R2) - ADDED JUMPERS TO ALLOW SWITCHING BETWEEN 5V AND GN, ENABLING COMPATIBILITY ON ALL SWITCHES TO ALL PCBS IN ARCADE (AUX/NEOPIXEL/RPI)

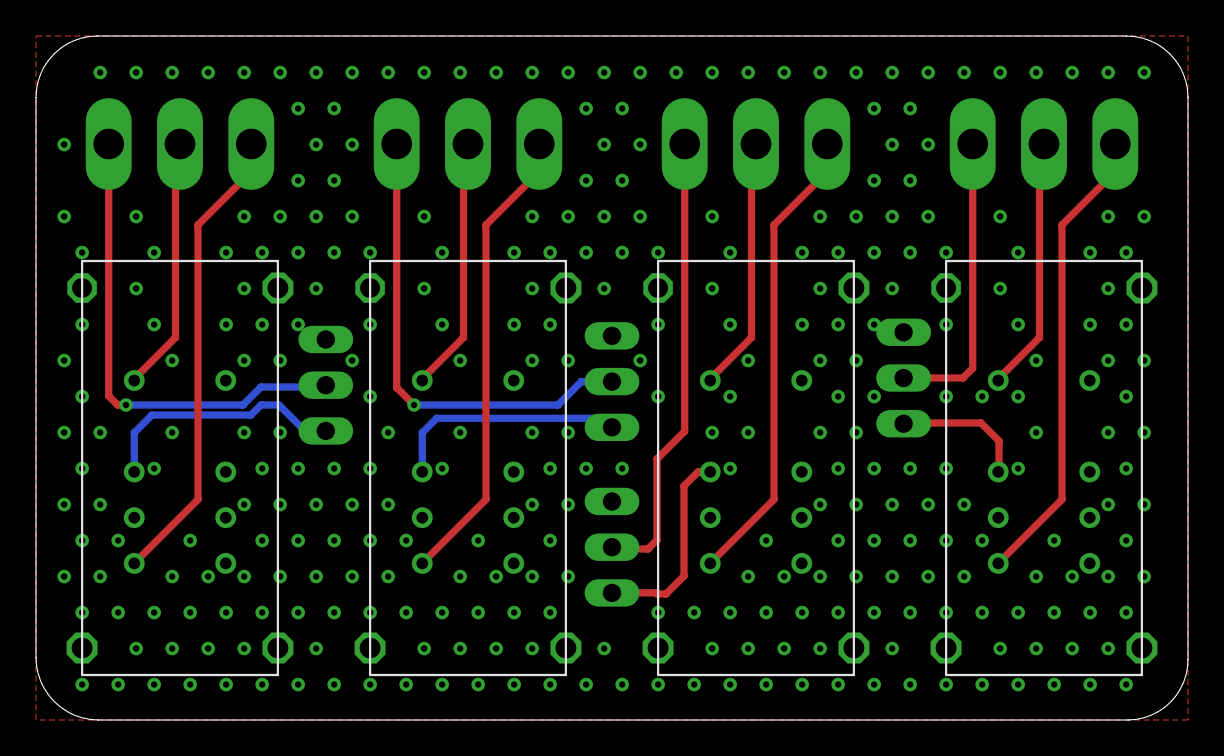
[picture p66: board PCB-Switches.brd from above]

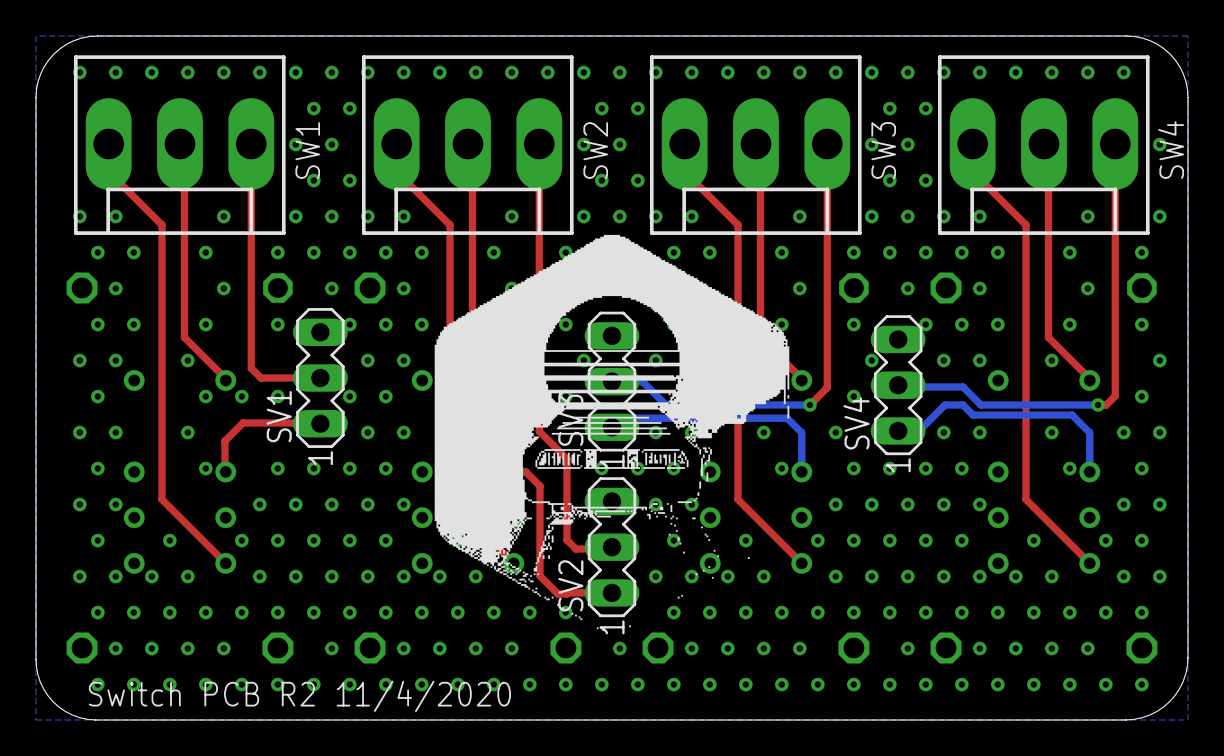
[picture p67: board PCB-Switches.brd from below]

Board: 2 copper layers, 64.0 x 38.0 mm, 12 parts (8 on the bottom side), 17 nets.

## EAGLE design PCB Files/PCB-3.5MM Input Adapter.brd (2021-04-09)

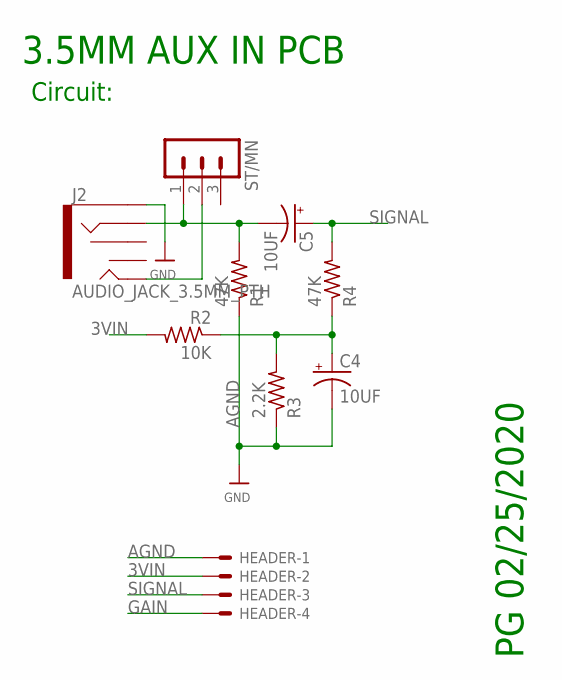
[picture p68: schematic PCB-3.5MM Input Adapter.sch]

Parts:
C4, C5: 10UF; E5-8,5
HEADER: KK-156-4
J2: AUDIO_JACK_3.5MM_PTH; AUDIO-JACK
R1, R4: 47K; R1206
R2: 10K; R1206
R3: 2.2K; R1206
ST/MN: MA03-1

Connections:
3VIN: HEADER.2, R2.2
AGND: C4.-, HEADER.1, J2.SLEEVE, R1.1, R3.1
GAIN: HEADER.4
HP1: C4.+, R2.1, R3.2, R4.1
unnamed: J2.TIP, ST/MN.2
unnamed: C5.-, J2.RING, R1.2, ST/MN.1
SIGNAL: C5.+, HEADER.3, R4.2

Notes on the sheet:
Circuit:
3.5MM AUX IN PCB
PG 02/25/2020

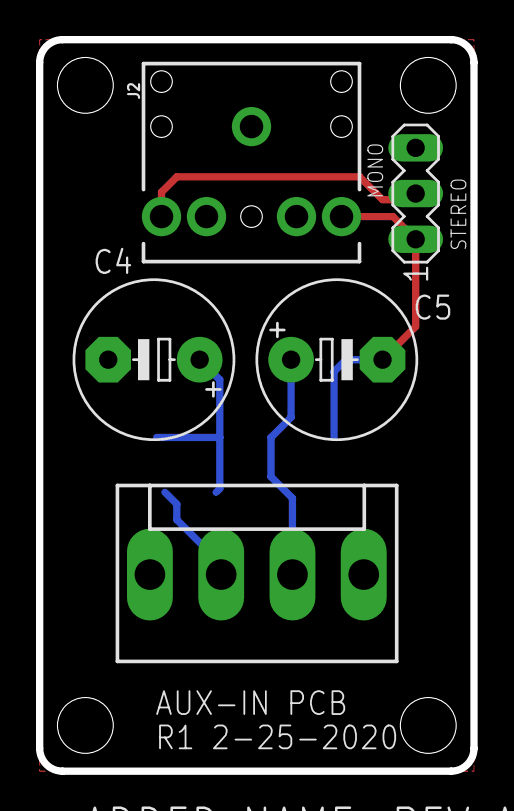
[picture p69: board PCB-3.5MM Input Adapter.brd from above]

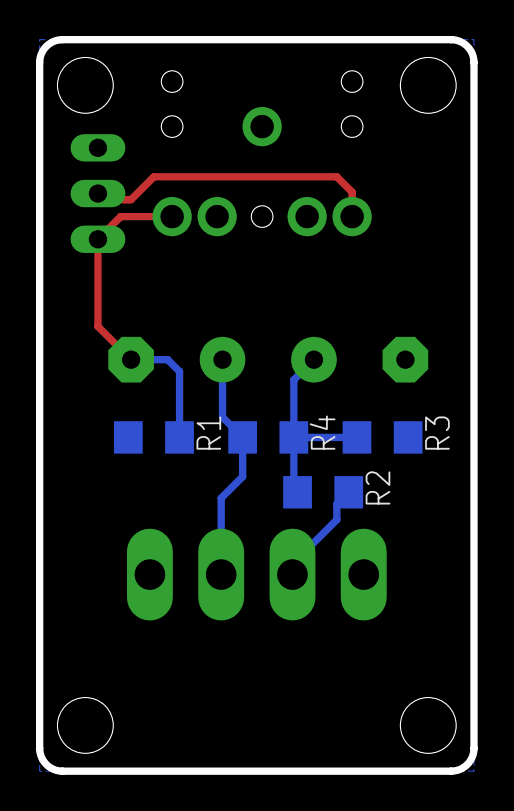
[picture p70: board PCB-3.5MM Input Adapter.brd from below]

Board: 2 copper layers, 24.1 x 40.6 mm, 9 parts (4 on the bottom side), 6 nets.

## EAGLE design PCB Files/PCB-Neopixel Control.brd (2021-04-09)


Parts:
5VIN_NP: KK-156-2
B1: TEENSY-3.2; TEENSY-3.1
C1: 4700uf; E5-13
GAIN: MA04-1
GND: KK-156-2
MICROPHONE: KK-156-4
NEOPIXEL: KK-156-3
OPT: KK-156-3
PLAYER1IN, PLAYER2IN: KK-156-8
R1: 470 Ohm; R1206
R2, R3, R4, R5, R6, R7: 10K; R1206
SW1, SW2: KK-156-3

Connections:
3.3V: B1.3.3V
3VIN: B1.3V, GAIN.4, MICROPHONE.2
5VIN: 5VIN_NP.2, B1.VIN, C1.-, NEOPIXEL.2, R2.2, R5.2, SW1.1, SW2.1
AGND: B1.AGND, GAIN.1, GAIN.2, MICROPHONE.1
GAIN: GAIN.3, MICROPHONE.4
GND: 5VIN_NP.1, B1.GND, B1.GND1, C1.+, GND.1, GND.2, NEOPIXEL.1, R4.1, R7.1
NEOPIXEL: B1.22 (A8/22*), R1.1
NP2T: NEOPIXEL.3, R1.2
OPT1: B1.17 (A3/17), OPT.1
OPT2: B1.18 (A4/18/SDA0), OPT.2
OPT3: B1.19 (A5/19/SCL0), OPT.3
P1A: B1.1 (1/TX1), PLAYER1IN.1
P1B: B1.2, PLAYER1IN.2
P1C: B1.3 (3*), PLAYER1IN.3
P1SL: B1.8 (8/TX3), PLAYER1IN.8
P1ST: B1.7 (7/RX3), PLAYER1IN.7
P1X: B1.4 (4*), PLAYER1IN.4
P1Y: B1.5 (5*), PLAYER1IN.5
P1Z: B1.6 (6*), PLAYER1IN.6
P2A: B1.9 (9*/RX2), PLAYER2IN.1
P2B: B1.10 (10*/TX2/CS), PLAYER2IN.2
P2C: B1.11 (11/DOUT), PLAYER2IN.3
P2SL: B1.16 (A2/16), PLAYER2IN.8
P2ST: B1.15 (A1/15), PLAYER2IN.7
P2X: B1.12 (12/DIN), PLAYER2IN.4
P2Y: B1.13 (13/SCK), PLAYER2IN.5
P2Z: B1.14 (A0/14), PLAYER2IN.6
SIGNAL: B1.23 (A9/23*), MICROPHONE.3
SW1: B1.20 (A6/20*), R3.1, R4.2, SW1.3
SW1A: R2.1, R3.2, SW1.2
SW2: B1.21 (A7/21*), R6.1, R7.2, SW2.3
SW2A: R5.1, R6.2, SW2.2
VBAT: B1.VBAT
VUSB: B1.VUSB

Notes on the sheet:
Teensy 3.2:
Switch Headers:
Microphone Header:
Microphone Gain Jumper:
Power Headers:
Neopixel:
Button Intercept Headers:
Neopixel Control PCB R3
PG 4/7/2021
11-4-2020 - (R2) - R2 UPDATES: 1. MOVED ALL CONTROLS UP ONE PIN ON TEENSY (D0 WOULD NOT REGISTER A ON P1). 2. REMOVED OPT4 AS IT IS NOT USED IN THE DESIGN 3. SWAPPED 2X 11 PIN MOLEX HEADERS FOR 2X 8 PIN (P1 AND P2), 1X 3 PIN (OPT) AND 1X 2 PIN (GND) TO BETTER SPLIT THE GROUPS OF INPUTS 4. REMOVED T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
NOTE: FIRMWARE WILL NEED TO BE REVISED FOR R3 PCB TO WORK AS ALL INPUTS HAVE BEEN REASSIGNED
4-7-2021 - (R3) - R3 UPDATES: 1. CHANGED R2-R7 TO 10K (FORMERLY 1K)


Board: 2 copper layers, 95.2 x 62.2 mm, 19 parts (0 on the bottom side), 31 nets.

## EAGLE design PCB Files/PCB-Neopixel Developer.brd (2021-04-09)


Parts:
B2: TEENSY-3.2; TEENSY-3.1
C2: 4700uf; E5-13
C4, C5: 10UF; E5-8,5
GAIN: MA04-1
J1: POWER_JACKPTH_LOCK; POWER_JACK_PTH_LOCK
J2: AUDIO_JACK_3.5MM_PTH; AUDIO-JACK
MICROPHONE: KK-156-4
R1, R4: 47K; R1206
R2, R9, R10, R11, R12, R13, R14: 10K; R1206
R3: 2.2K; R1206
R8: 470 Ohm; R1206
S1, S2, S3, S4, S5, S6, S7, S8, S9, S10, S11, S12, S13, S14, S15, S16, S17, S18, S19: MOMENTARY-SWITCH-SPST-SMD-6.2MM-TALL; TACTILE_SWITCH_SMD_6.2MM_TALL
S20, S21, S22, S23: MOMENTARY-SWITCH-SPST-PTH-6.0MM; TACTILE_SWITCH_PTH_6.0MM
ST/MN: MA03-1
SV2, SV3: MA03-1
U$2, U$7: NP-2
U$8, U$10, U$11, U$12, U$13: NP-3

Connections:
3.3V: B2.3.3V
3VIN: B2.3V, GAIN.4, MICROPHONE.2, R2.2
5VIN: C2.+, J1.PWR, R9.2, R12.2, S20.3 (2), S21.3 (2), S22.3 (2), S23.3 (2), SV3.1, U$2.VIN, U$2.VOUT (VIN), U$7.VIN, U$7.VOUT (VIN), U$8.VIN, U$8.VOUT (VIN), U$10.VIN, U$10.VOUT (VIN), U$11.VIN, U$11.VOUT (VIN), U$12.VIN, U$12.VOUT (VIN), U$13.VIN, U$13.VOUT (VIN)
AGND: B2.AGND, C4.-, GAIN.1, GAIN.2, J2.SLEEVE, MICROPHONE.1, R1.1, R3.1
D1: R8.1, U$12.DIN
D2: U$12.DOUT, U$13.DIN
D3: U$2.DIN, U$13.DOUT
D4: U$2.DOUT, U$11.DIN
D5: U$7.DIN, U$11.DOUT
D6: U$7.DOUT, U$8.DIN
D7: U$8.DOUT, U$10.DIN
GAIN: GAIN.3, MICROPHONE.4
GND: B2.GND, B2.GND1, C2.-, J1.GND, R11.1, R14.1, S1.A1 (2), S2.A1 (2), S3.A1 (2), S4.A1 (2), S5.A1 (2), S6.A1 (2), S7.A1 (2), S8.A1 (2), S9.A1 (2), S10.A1 (2), S11.A2 (1), S12.A2 (1), S13.A2 (1), S14.A2 (1), S15.A2 (1), S16.A2 (1), S17.A2 (1), S18.A2 (1), S19.A2 (1), U$2.GND, U$2.GND1 (GND), U$7.GND, U$7.GND1 (GND), U$8.GND, U$8.GND1 (GND), U$10.GND, U$10.GND1 (GND), U$11.GND, U$11.GND1 (GND), U$12.GND, U$12.GND1 (GND), U$13.GND, U$13.GND1 (GND)
HP1: C4.+, R2.1, R3.2, R4.1
HP2: C5.+, R4.2, SV2.1
unnamed: J2.TIP, ST/MN.1
unnamed: C5.-, J2.RING, R1.2, ST/MN.2
NEOPIXEL: B2.22 (A8/22*), R8.2
OPT1: B2.17 (A3/17), S9.A2 (1)
OPT2: B2.18 (A4/18/SDA0), S10.A2 (1)
OPT3: B2.19 (A5/19/SCL0), S19.A1 (2)
P1A: B2.1 (1/TX1), S1.A2 (1)
P1B: B2.2, S2.A2 (1)
P1C: B2.3 (3*), S3.A2 (1)
P1SL: B2.8 (8/TX3), S8.A2 (1)
P1ST: B2.7 (7/RX3), S7.A2 (1)
P1X: B2.4 (4*), S4.A2 (1)
P1Y: B2.5 (5*), S5.A2 (1)
P1Z: B2.6 (6*), S6.A2 (1)
P2A: B2.9 (9*/RX2), S11.A1 (2)
P2B: B2.10 (10*/TX2/CS), S12.A1 (2)
P2C: B2.11 (11/DOUT), S13.A1 (2)
P2SL: B2.16 (A2/16), S18.A1 (2)
P2ST: B2.15 (A1/15), S17.A1 (2)
P2X: B2.12 (12/DIN), S14.A1 (2)
P2Y: B2.13 (13/SCK), S15.A1 (2)
P2Z: B2.14 (A0/14), S16.A1 (2)
SIGNAL: B2.23 (A9/23*), MICROPHONE.3, SV2.2
SW1: B2.20 (A6/20*), R10.1, R11.2, S21.1
SW1A: R9.1, R10.2, S20.1
SW2: B2.21 (A7/21*), R13.1, R14.2, S23.1
SW2A: R12.1, R13.2, S22.1
TVIN: B2.VIN, SV3.2
VBAT: B2.VBAT
VUSB: B2.VUSB

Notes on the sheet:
Teensy 3.2:
Switch Headers:
Microphone Header:
Microphone Gain Jumper:
Power Headers:
Neopixel:
Button Intercept Headers:
Neopixel Development PCB R3
PG 4/7/2021
AUX In Header:
11-4-2020 - (R2) - R2 UPDATES: 1. MOVED ALL CONTROLS UP ONE PIN ON TEENSY (D0 WOULD NOT REGISTER A ON P1). 2. REMOVED OPT4 AS IT IS NOT USED IN THE DESIGN
4-7-2021 - (R3) - R3 UPDATES: 1. MOVED GND PIN ON ALL INPUT BUTTONS 1/2P (ABCXYZ OPT1/2/3) - BUTTONS THAT ARE USED ON THE PCB BRIDGE HORIZONTALLY NOT VERTICALLY 2. UPDATED R9,R10,R12,R13 TO 10K (FORMERLY 1K) AS THE VOLTAGE NEEDED TO DROP BELOW 3.3V FOR TEENSY TO RECOGNIZE BUTTON PRESSES


Board: 2 copper layers, 160.0 x 100.0 mm, 52 parts (0 on the bottom side), 42 nets.

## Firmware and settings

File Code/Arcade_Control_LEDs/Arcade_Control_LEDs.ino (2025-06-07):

#include <FastLED.h>
#include <EEPROM.h>

//Pin Assignments
#define P1_A 1      //Player 1 Button A
#define P1_B 2       //Player 1 Button B
#define P1_C 3       //Player 1 Button C
#define P1_X 4       //Player 1 Button X
#define P1_Y 5       //Player 1 Button Y 
#define P1_Z 6       //Player 1 Button Z
#define SW1  A6      //Toggle Switch 1y
#define SW2  A7      //Toggle Switch 2
#define DATA_PIN  22 //Neopixel Data Pin

//FastLED Parameters
#define LED_TYPE    WS2811
#define COLOR_ORDER GRB
#define NUM_LEDS    6
#define FRAMES_PER_SECOND  120
int BRIGHTNESS = 96;

//Define Canvases and Arrays
CRGB Output_Array[NUM_LEDS]; //physical space
CRGB canvas1[16][16]; //virtual canvas
CRGB canvas2[16][16]; //virtual canvas
CRGB combined_canvas[16][16];  // this is optional

//Arrays
int Boot_X[] = {8, 9, 7, 4, 11, 3, 12, 2, 11, 2, 11, 3, 12, 3, 12, 4, 13, 4, 13, 2, 3, 4, 11, 12, 13, 2, 3, 4, 11, 12, 13, 3, 12, 4, 11, 9, 7, 8, 0, 7, 8, 9, 7, 8, 9, 7, 8, 9, 7, 8, 9, 7, 8, 9, 7, 8, 9, 7, 8, 9, 7, 8, 9, 7, 8, 9, 7, 8, 9, 0, 0};
int Boot_Y[] = {9, 9, 9, 9, 9, 9, 9, 7, 7, 6, 6, 7, 7, 6, 6, 7, 7, 6, 6, 6, 6, 6, 6, 6, 6, 7, 7, 7, 7, 7, 7, 9, 9, 9, 9, 9, 9, 9, 0, 9, 9, 9, 9, 9, 9, 9, 9, 9, 9, 9, 9, 9, 9, 9, 9, 9, 9, 9, 9, 9, 9, 9, 9, 9, 9, 9, 9, 9, 9, 0, 0};
int Boot_Step[] = {1, 2, 2, 2, 2, 2, 2, 2, 2, 2, 6, 6, 2, 2, 2, 1, 1, 3, 3, 3, 3, 3, 3, 3, 3, 3, 3, 1, 0};


//Variables

//Switch Variables
int SW1state = 0;             //Current State of Switch 1
int SW2state = 0;             //Current State of Switch 2
int SW1debounce = 0;          //SW1 Debouce trigger
int SW2debounce = 0;          //SW2 Debouce trigger
int RainbowTrigger = 0;       //Triggers Rainbow effect
int WashType = 0;             //Determines wether the wash is Rainbow or Confetti
int gHuereset = 0;            //resets Hue for Static layouts
int decayflag = 0;            //sets the decay function
unsigned long Cycle_Time;     //Time for Millis

//Boot Animation Variables
int Array_Pos = 0;
int Array_Pos_Start = 0;
int Boot_Step_Pos = 0;
int Boot_Start = 0;
int Fade_out_toggle = 0;
int Fade_out_rate = 1;
int Fade_out_tail = 1;
int Array_Pos_Delay = 0;
int Boot_Bright = 255;
int Boot_Hue = 0;
int Frame_Rate = 200;
unsigned long start_Time = 0;

//Attractmode placeholder variables
int AM_gHue = 0;
int AM_Brightness = 0;
int AM_Mode = 0;
int AM_RainbowTrigger = 0;
int AM_WashType = 0;
unsigned long AM_Timer;               //Time (Millis) of Button Press
unsigned long AM_Delay = 15000;           //Length of time to wait to start Attract Mode

//EEPROM Variables
unsigned long EEPROM_Timer;               //Time (Millis) of Last Marquee Change
unsigned long EEPROM_Write_Delay = 15000; //Delay before EEPROM Write to prevent to many writes to one address
int EEPROMCheck = 0;             //Current EEPROM Value
int EEPROM_Confirm_Flash = 250;           //Milliseconds for Flash on EEPROM Write Confirm
int Color_EEProm = 0;                     //EEPROM Address used to Store Last Color
int Brightness_EEProm = 1;                //EEPROM Address used to Store Last Brighness
int Mode_EEProm = 2;                      //EEPROM Address used to Store Last Mode
int Wash_EEProm = 3;                      //EEPROM Address used to Store Last Color Wash Type
int RB_EEProm = 3;                      //EEPROM Address used to Store Last Color Wash Toggle
int EEPROMstart = 0;

void setup() {
  //Serial Setup
  Serial.begin(9600);
  //FastLED Setup
  FastLED.addLeds<LED_TYPE, DATA_PIN, COLOR_ORDER>(Output_Array, NUM_LEDS).setCorrection(TypicalLEDStrip); //LED Setup
  FastLED.setBrightness(BRIGHTNESS); // set master brightness control
  //Input Setup
  pinMode(P1_A, INPUT);     //Player 1 Button A
  pinMode(P1_B, INPUT);     //Player 1 Button B
  pinMode(P1_C, INPUT);     //Player 1 Button C
  pinMode(P1_X, INPUT);     //Player 1 Button X
  pinMode(P1_Y, INPUT);     //Player 1 Button Y
  pinMode(P1_Z, INPUT);     //Player 1 Button Z
  pinMode(OPT1, INPUT);     //Option 1 (QUIT)
  pinMode(OPT2, INPUT);     //Option 2 (SAVE)
  pinMode(OPT3, INPUT);     //Option 3 (LOAD)
}

//Array Setup
typedef void (*SimplePatternList[])(); // List of patterns to cycle through.  Each is defined as a separate function below.
SimplePatternList gPatterns = { sinelon, doublesinelon, rainbow, juggle, confetti, soildstatic, layoutstatic, demo };
uint8_t gCurrentPatternNumber = 0; // Index number of which pattern is current
uint8_t gHue = 0; // rotating "base color" used by many of the patterns

void loop() {
  if (Boot_Start == 0) {
    Boot_Animation();    //Boot Animation
    EEPROMread();    //Read EEPROM for last known values
    Boot_Start = 1;
  }

  if ((EEPROM_Timer + EEPROM_Write_Delay) < Cycle_Time && EEPROMCheck != 0) {
    EEPROMwrite();
  }
  // Call the current pattern function once, updating the 'leds' array
  gPatterns[gCurrentPatternNumber]();

  //Read All Inputs
  Cycle_Time = millis();
  SW1state = analogRead(SW1);
  SW2state = analogRead(SW2);

  //Switch 1 Functionality - Controls Current Pattern and Brightness of LEDs
  if (SW1state < 700) {
    SW1debounce = 0;
  }
  if (SW1state > 700 && SW1state < 800 && SW1debounce == 0) {
    nextPattern();
    SW1debounce = 1;
    EEPROMCheck = 1;
    EEPROM_Timer = Cycle_Time;
    gHuereset = 0;
  }
  if (SW1state > 900) {
    bright();
    EEPROMCheck = 1;
    EEPROM_Timer = Cycle_Time;
  }

  //Switch 2 Functionality - Controls hue and Color Wash of LEDs
  if (SW2state < 700) {
    SW2debounce = 0;
  }
  if (SW2state > 700 && SW2state < 800 && SW2debounce == 0) {
    gHue = gHue + 28;
    RainbowTrigger = 1;
    SW2debounce = 1;
    EEPROMCheck = 1;
    EEPROM_Timer = Cycle_Time;
  }
  if (SW2state > 900 && SW2debounce == 0) {
    RainbowTrigger = 0;
    if (WashType == 1) {
      WashType = 0;
    }
    else {
      WashType = 1;
    }
    SW2debounce = 1;
    EEPROMCheck = 1;
    EEPROM_Timer = Cycle_Time;
  }
  if (RainbowTrigger == 0) {
    if (WashType == 0) {
      EVERY_N_MILLISECONDS( 20 ) {
        gHue++;  // slowly cycle the "base color" through the rainbow
      }
    }
    else {
      EVERY_N_MILLISECONDS( 48 ) {
        gHue += 25;
      }
    }
  }

  //FastLED Execution
  FastLED.show();  // send the 'leds' array out to the actual LED strip
  FastLED.delay(1000 / FRAMES_PER_SECOND); // insert a delay to keep the framerate modest
}

#define ARRAY_SIZE(A) (sizeof(A) / sizeof((A)[0]))

void EEPROMread() {
  gHue = EEPROM.read(Color_EEProm);
  BRIGHTNESS = EEPROM.read(Brightness_EEProm);
  gCurrentPatternNumber = EEPROM.read(Mode_EEProm);
  RainbowTrigger = EEPROM.read(RB_EEProm);
  WashType = EEPROM.read(Wash_EEProm);
}

void EEPROMwrite() {
  //Write Brightness Value to EEPROM
  if (gHue != EEPROM.read(Color_EEProm)) {
    EEPROM.write(Color_EEProm, gHue);
    Serial.println("Color Written");
  }
  if (BRIGHTNESS != EEPROM.read(Brightness_EEProm)) {
    EEPROM.write(Brightness_EEProm, BRIGHTNESS);
    Serial.println("Brightness Written");
  }
  if (gCurrentPatternNumber != EEPROM.read(Mode_EEProm)) {
    EEPROM.write(Mode_EEProm, gCurrentPatternNumber);
    Serial.println("Mode Written");
  }
  if (RainbowTrigger != EEPROM.read(RB_EEProm)) {
    EEPROM.write(RB_EEProm, RainbowTrigger);
    Serial.println("Rainbow Written");
  }
  if (WashType != EEPROM.read(Wash_EEProm)) {
    EEPROM.write(Wash_EEProm, WashType);
    Serial.println("Wash Type Written");
  }
  EEPROMCheck = 0;
  delay(2000);
}

void nextPattern()
{
  // add one to the current pattern number, and wrap around at the end
  gCurrentPatternNumber = (gCurrentPatternNumber + 1) % ARRAY_SIZE( gPatterns);
}

void demo()
{
  // add one to the current pattern number, and wrap around at the end
  EVERY_N_MILLISECONDS( 15000 ) {
    gCurrentPatternNumber = (gCurrentPatternNumber + 1) % ARRAY_SIZE( gPatterns);
  }
}

void bright()
{
  // add one to the current pattern number, and wrap around at the end
  BRIGHTNESS = (BRIGHTNESS - 1);
  if (BRIGHTNESS < 1) {
    BRIGHTNESS = 255;
  }
  FastLED.setBrightness(BRIGHTNESS);
}

//void attractmode(){
// AM_gHue = gHue;
// AM_Brightness = BRIGHTNESS;
// AM_Mode = gCurrentPatternNumber;
// AM_RainbowTrigger = RainbowTrigger;
// AM_WashType = WashType;
// Brightness = 200;
// RainbowTrigger = 0;
// WashType = 1;
// EVERY_N_SECONDS( 13 ) { nextPattern(); } // change patterns periodically
//}

void rainbow()
{
  // FastLED's built-in rainbow generator
  fill_rainbow( Output_Array, NUM_LEDS, gHue, 7);
}

void sinelon()
{
  // a colored dot sweeping back and forth, with fading trails
  fadeToBlackBy( Output_Array, NUM_LEDS, 8);
  int pos = beatsin16( 13, 0, NUM_LEDS - 1 );
  Output_Array[pos] += CHSV( gHue, 255, 192);
}

void doublesinelon()
{
  // a colored dot sweeping back and forth, with fading trails
  fadeToBlackBy( Output_Array, NUM_LEDS, 20);
  int pos1 = beatsin16( 13, 0, NUM_LEDS - 1 );
  int pos2 = beatsin16( 13, 0, NUM_LEDS - 1 );
  pos2 = pos2 - (pos2 * 2) + NUM_LEDS - 1;
  Output_Array[pos1] += CHSV( gHue, 255, 192);
  Output_Array[pos2] += CHSV( gHue - 97, 255, 192);
}

void juggle() {
  // eight colored dots, weaving in and out of sync with each other
  fadeToBlackBy( Output_Array, NUM_LEDS, 20);
  for ( int i = 0; i < 8; i++) {
    Output_Array[beatsin16( i + 7, 0, NUM_LEDS - 1 )] |= CHSV(gHue, 200, 255);
  }
}

void confetti()
{
  // random colored speckles that blink in and fade smoothly
  fadeToBlackBy( Output_Array, NUM_LEDS, 10);
  int pos = random16(NUM_LEDS);
  Output_Array[pos] += CHSV( gHue + random8(64), 200, 255);
}

void layoutstatic() {
  if (gHuereset == 0) {
    gHue = 0;
    gHuereset = 1;
    RainbowTrigger = 1;
  }
  canvas1[13][6] = CHSV(gHue + 128, 255, 255);
  canvas1[12][6] = CHSV(gHue + 112, 255, 255);
  canvas1[11][6] = CHSV(gHue + 96, 255, 255);
  canvas1[11][7] = CHSV(gHue + 96, 255, 255);
  canvas1[12][7] = CHSV(gHue + 112, 255, 255);
  canvas1[13][7] = CHSV(gHue + 128, 255, 255);
  canvas1[12][9] = CHSV(gHue + 64, 255, 255);
  canvas1[11][9] = CRGB(gHue + 255, 255, 255);
  canvas1[9][9] = CHSV(gHue + 160, 255, 255);
  canvas1[8][9] = CHSV(gHue + 160, 255, 255);
  canvas1[7][9] = CHSV(gHue + 160, 255, 255);
  canvas1[4][9] = CHSV(gHue + 64, 255, 255);
  canvas1[3][9] = CRGB(gHue + 255, 255, 255);
  canvas1[2][7] = CHSV(gHue + 0, 255, 255);
  canvas1[3][7] = CHSV(gHue + 16, 255, 255);
  canvas1[4][7] = CHSV(gHue + 32, 255, 255);
  canvas1[4][6] = CHSV(gHue + 32, 255, 255);
  canvas1[3][6] = CHSV(gHue + 16, 255, 255);
  canvas1[2][6] = CHSV(gHue + 0, 255, 255);
  canvasOutput(5);
}

void soildstatic()
{
  for (int x = 0; x < 16; x++) {
    for (int y = 0; y < 16; y++) {
      canvas1[x][y] = CHSV(gHue, 255, 255);
    }
  }
  canvasOutput(5);
}


void canvasOutput(int blend_rate) {
  for (int x = 0; x < 16; x++) {
    for (int y = 0; y < 16; y++) {
      combined_canvas[x][y] = canvas1[x][y] + canvas2[x][y];
    }
  }

  blend_copy(&Output_Array[0], &combined_canvas[13][6], blend_rate);
  blend_copy(&Output_Array[1], &combined_canvas[12][6], blend_rate);
  blend_copy(&Output_Array[2], &combined_canvas[11][6], blend_rate);
  blend_copy(&Output_Array[3], &combined_canvas[11][7], blend_rate);
  blend_copy(&Output_Array[4], &combined_canvas[12][7], blend_rate);
  blend_copy(&Output_Array[5], &combined_canvas[13][7], blend_rate);
  blend_copy(&Output_Array[6], &combined_canvas[12][9], blend_rate);
  blend_copy(&Output_Array[7], &combined_canvas[11][9], blend_rate);
  blend_copy(&Output_Array[8], &combined_canvas[9][9], blend_rate);
  blend_copy(&Output_Array[9], &combined_canvas[8][9], blend_rate);
  blend_copy(&Output_Array[10], &combined_canvas[7][9], blend_rate);
  blend_copy(&Output_Array[11], &combined_canvas[4][9], blend_rate);
  blend_copy(&Output_Array[12], &combined_canvas[3][9], blend_rate);
  blend_copy(&Output_Array[13], &combined_canvas[2][7], blend_rate);
  blend_copy(&Output_Array[14], &combined_canvas[3][7], blend_rate);
  blend_copy(&Output_Array[15], &combined_canvas[4][7], blend_rate);
  blend_copy(&Output_Array[16], &combined_canvas[4][6], blend_rate);
  blend_copy(&Output_Array[17], &combined_canvas[3][6], blend_rate);
  blend_copy(&Output_Array[18], &combined_canvas[2][6], blend_rate);
}

void blend_copy(CRGB * destination , CRGB * source_crgb , uint8_t blur_rate ) {
  if (destination->r < source_crgb->r) destination->r = min(qadd8(destination->r, blur_rate), source_crgb->r);
  else if (destination->r > source_crgb->r) destination->r = max(qsub8(destination->r, blur_rate), source_crgb->r);
  if (destination->g < source_crgb->g) destination->g = min(qadd8(destination->g, blur_rate), source_crgb->g);
  else if (destination->g > source_crgb->g) destination->g = max(qsub8(destination->g, blur_rate), source_crgb->g);
  if (destination->b < source_crgb->b) destination->b = min(qadd8(destination->b, blur_rate), source_crgb->b);
  else if (destination->b > source_crgb->b) destination->b = max(qsub8(destination->b, blur_rate), source_crgb->b);
}

void Boot_Animation() {
  int blend_setting;
  for (int z = 0; z < 12; z++) {
    if (z == 2 || z == 4 || z == 6 || z == 8 || z == 10 || z == 12 || z == 14 || z == 16 || z == 18 || z == 20) {
      Frame_Rate = 1000;
      Boot_Bright = 255;
      Fade_out_toggle = 1;
      blend_setting = 2;
      Fade_out_rate = 1;
    }
    else {
      Frame_Rate = 1000;
      Boot_Bright = 0;
      Fade_out_toggle = 1;
      blend_setting = 2;
      Fade_out_rate = 1;
    }
    uint32_t framestarttime = millis();
    while (millis() - framestarttime < Frame_Rate) {
      canvas1[8][9] = CHSV(0, 0, Boot_Bright);

      if (Fade_out_toggle == 1) {
        static uint32_t decay2_timer = 0;
        if (millis() - decay2_timer > 1) {
          decay2_timer = millis();
          fadeToBlackBy( (CRGB*) canvas1, 16 * 16, Fade_out_rate);
        }
      }
      static uint32_t render_timer = 0;
      if (millis() - render_timer > 10) {
        canvasOutput(blend_setting);
        FastLED.show();  // send the 'leds' array out to the actual LED strip
        render_timer = millis();
      }
    }
  }
  Boot_Step_Pos = 0;
  Array_Pos_Start = 0;
  Array_Pos = 0;
  for (int z = 0; z < 29; z++) {
    if (z < 9) {
      Frame_Rate = 400;
      Boot_Hue = 144;
      Boot_Bright = 255;
      Fade_out_toggle = 1;
      blend_setting = 1;
      Fade_out_rate = 1;
      Fade_out_tail = 5;
    }
    if (z == 9) {
      Frame_Rate = 2000;
      Boot_Hue = 144;
      Boot_Bright = 255;
      Fade_out_toggle = 1;
      blend_setting = 1;
      Fade_out_rate = 1;
      Fade_out_tail = 5;
    }
    if (z == 10) {
      Frame_Rate = 600;
      Boot_Hue = 32;
      Boot_Bright = 255;
      Fade_out_toggle = 0;
      blend_setting = 2;
      Fade_out_rate = 1;
      Fade_out_tail = 1;
    }
    if (z > 11  && z < 16) {
      Frame_Rate = 400;
      Boot_Hue = 32;
      Boot_Bright = 255;
      Fade_out_toggle = 0;
      blend_setting = 10;
      Fade_out_rate = 1;
      Fade_out_tail = 1;
    }
    if (z == 16) {
      Frame_Rate = 800;
      Boot_Hue = 0;
      Boot_Bright = 0;
      Fade_out_toggle = 1;
      blend_setting = 10;
      Fade_out_rate = 1;
      Fade_out_tail = 1;
      for (int x = 0; x < 16; x++) {
        for (int y = 0; y < 16; y++) {
          canvas1[x][y] = CRGB(0, 0, 0);
        }
      }
    }
    if (z == 17 || z == 19 || z == 21 || z == 23 || z == 25) {
      Frame_Rate = 200;
      Boot_Hue = 160;
      Boot_Bright = 255;
      Fade_out_toggle = 1;
      blend_setting = 20;
      Fade_out_rate = 1;
      Fade_out_tail = 1;
    }
    if (z == 18 || z == 20 || z == 22 || z == 24 || z == 26) {
      Frame_Rate = 1200;
      Boot_Hue = 0;
      Boot_Bright = 0;
      Fade_out_toggle = 1;
      blend_setting = 5;
      Fade_out_rate = 1;
      Fade_out_tail = 1;
    }
    if (z == 27) {
      Frame_Rate = 2000;
      Boot_Hue = 0;
      Boot_Bright = 255;
      Fade_out_toggle = 0;
      blend_setting = 10;
      Fade_out_rate = 1;
      Fade_out_tail = 1;
      for (int x = 0; x < 16; x++) {
        for (int y = 0; y < 16; y++) {
          canvas1[x][y] = CHSV(Boot_Hue, 255, 255);
        }
      }
    }
    if (z == 28) {
      Frame_Rate = 2000;
      Boot_Hue = 0;
      Boot_Bright = 0;
      Fade_out_toggle = 1;
      blend_setting = 10;
      Fade_out_rate = 1;
      Fade_out_tail = 1;
      for (int x = 0; x < 16; x++) {
        for (int y = 0; y < 16; y++) {
          canvas1[x][y] = CHSV(96, 255, 0);
        }
      }
    }
    uint32_t framestarttime = millis();
    while (millis() - framestarttime < Frame_Rate) {
      Array_Pos = Array_Pos_Start;
      for (int x = 0; x < Boot_Step[Boot_Step_Pos]; x++) {
        canvas1[Boot_X[Array_Pos]][Boot_Y[Array_Pos]] = CHSV(Boot_Hue, 255, Boot_Bright);
        Array_Pos++;
      }

      if (Fade_out_toggle == 1) {
        static uint32_t decay2_timer = 0;
        if (millis() - decay2_timer > Fade_out_tail) {
          decay2_timer = millis();
          fadeToBlackBy( (CRGB*) canvas1, 16 * 16, Fade_out_rate);
        }
      }
      static uint32_t render_timer = 0;
      if (millis() - render_timer > 10) {
        canvasOutput(blend_setting);
        FastLED.show();  // send the 'leds' array out to the actual LED strip
        render_timer = millis();
      }
    }
    Array_Pos_Start += Boot_Step[Boot_Step_Pos];
    Boot_Step_Pos++;
  }
}

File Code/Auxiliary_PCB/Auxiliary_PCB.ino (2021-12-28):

//Libraries
#include <DHT.h>
#include <EEPROM.h>
#include <Wire.h>
#include <Adafruit_LiquidCrystal.h>

//Pin Assignments
#define Temp_Upper 3  //Temp Sensor to Monitor Marquee LED Tempature
#define Temp_Lower 2  //Temp Sensor to Monitor All other Equipment
#define Fan_Upper 5   //Fans in Upper Section of Cabinet
#define Fan_Lower 6   //Fan in Lower Section of Cabinet 
#define Marquee 4     //Marquee LEDs 
#define Sw_Marquee 0  //Switch to Control Marquee Brightness
#define Sw_Fan 1      //Switch to Toggle the Fans On/Off
#define Sw_Future1 7  //Switch B - Possible Future Functionality Expansion
#define Sw_Future2 8  //Switch B - Possible Future Functionality Expansion
#define Pwr_LED 13    //Power LED

// LCD i2c Address
Adafruit_LiquidCrystal lcd(0);

//Temp Sensor Definition
#define DHTTYPE DHT22   // DHT 22  AM2302

//Arrays
//Fluorescent Flicker Array for Marquee 
int Flicker[] = {10, 20, 20, 240, 20, 40, 20, 100, 20, 20, 20, 260, 80, 20, 240, 60, 160, 20, 240, 20, 1000, 20, 20, 40, 100, 20, 2740, 340, 860, 20, 1400, 20, 60, 20};
// Brightness Scale for Marquee Flicker
int Flicker_High[] = {58, 58, 58, 58, 58, 58, 58, 58, 58, 58, 115, 115, 115, 115, 172, 172, 230, 230, 230, 230, 230, 230, 230, 230, 230, 230, 230, 230, 230, 230, 230, 230, 230, 230};
// Brightness Low Scale for Marquee Flicker
int Flicker_Low[] = {0, 0, 0, 0, 0, 0, 0, 0, 0, 0, 0, 0, 0, 0, 0, 0, 0, 0, 0, 0, 0, 0, 0, 0, 0, 0, 0, 25, 0, 0, 0, 0, 0, 0};
// Brightness Scale for Marquee Switch
int MQ_Bright[] = {230, 200, 172, 145, 115, 80, 58, 25, 0};

//Variable Assignments
unsigned long Cycle_Time;                 //Time for Millis
//Marquee Variables
int Marquee_Flicker_Status = 1;           //Trigger Flicker at Boot, Set to 0 to Disable
int Marquee_Sw_Status;                    //Current Status of Marquee Switch
int Marquee_Sw_Last_Status;               //Last Status of Marquee Switch
int Marquee_Brightness = 0;               //Counter for Marquee Brightness Steps
int Marquee_EEProm = 0;                   //EEPROM Address used to Store Last Marquee Brighness
//Temp Sensor Variables
unsigned long Temp_Last_Read = 0;         //Time (Millis) of last Temp Read
int Temp_Trigger = 80;                    //Tempature to Trigger Fans On/Off
int Over_Temp_Trigger  = 91;              //Tempature to Trigger Warning
unsigned long Temp_Delay_Read = 2000;     //Delay Between Temp Reads
float Temp_Read_Upper;                    //Upper Temp Sensor Reading
float Temp_Read_Lower;                    //Lower Temp Sensor Reading
//Fan Switch Variables
int Fan_Sw_Toggle_Last_Status = 1;        //Last Status of Fan Switch
int Fan_Sw_Toggle_Last_State = 1;         //State to Disable Temp Sensors from Turning off Fans
int Fan_Sw_Toggle_Status;                 //Current Status of Fan Switch
unsigned long Fan_Timer;                  //Time (Milis) of when fans were turned on
unsigned long Fan_Write_Delay = 360000;   //Delay before fans turn off once the temp is less than Temp_Trigger
//EEPROM Variables
unsigned long EEPROM_Timer;               //Time (Millis) of Last Marquee Change     
unsigned long EEPROM_Write_Delay = 15000; //Delay before EEPROM Write to prevent to many writes to one address
int EEPROM_Current_Value = 0;             //Current EEPROM Value
int EEPROM_Confirm_Flash = 250;           //Milliseconds for Flash on EEPROM Write Confirm

//Temp Assignments
DHT TempUpper(Temp_Upper, DHTTYPE);
DHT TempLower(Temp_Lower, DHTTYPE);

void setup() {
  Serial.begin(9600);

 //Initialize GPIO
  pinMode(Fan_Upper, OUTPUT);
  pinMode(Fan_Lower, OUTPUT);
  pinMode(Marquee, OUTPUT);
  pinMode(Sw_Marquee, INPUT_PULLUP);
  pinMode(Sw_Fan, INPUT_PULLUP);
  pinMode(Sw_Future1, INPUT_PULLUP);
  pinMode(Sw_Future2, INPUT_PULLUP);
  pinMode(Pwr_LED, OUTPUT);
  digitalWrite(Pwr_LED, HIGH);

//Initialize Temp Assignments
  TempUpper.begin();
  TempLower.begin();

// Initialize the LCD 
  lcd.begin(16, 2);
  lcd.setBacklight(HIGH);
  lcd.print("    BOOTING");
}

void loop() {
//Marquee Fluorescent Flicker Emulation
  if (Marquee_Flicker_Status == 1){                                
    for(int i=0; i<33; i++) {
        lcd.setCursor(0, 0);
        lcd.print("Initialize  ");
        lcd.setCursor(0, 1);
        lcd.print("Marquee Flicker");
        analogWrite(Marquee, Flicker_High[i]);
        delay(Flicker[i]);
        ++i;
        analogWrite(Marquee, Flicker_Low[i]);
        delay(Flicker[i]);
        analogWrite(Marquee, Flicker_High[i]);        
        Marquee_Flicker_Status = 0;
     }

//Read EEPROM for last Marquee Brightness Value
  Marquee_Brightness = EEPROM.read(Marquee_EEProm);
  EEPROM_Current_Value = EEPROM.read(Marquee_EEProm);
  analogWrite(Marquee, MQ_Bright[Marquee_Brightness]); 
  }

//Start Reading Inputs
  Cycle_Time = millis();
  Marquee_Sw_Status = digitalRead(Sw_Marquee);
  Fan_Sw_Toggle_Status = digitalRead(Sw_Fan);
  if ((Temp_Last_Read + Temp_Delay_Read) < Cycle_Time) {
    Temp_Read_Upper = TempUpper.readTemperature(true);
    Temp_Read_Lower = TempLower.readTemperature(true);
    Temp_Last_Read = Cycle_Time;
  }

//Screen Temp & Fan Status Display
  if ((EEPROM_Timer + EEPROM_Write_Delay) < Cycle_Time && Marquee_Brightness != EEPROM_Current_Value) {
    lcd.setCursor(0, 0);
    lcd.print("EEPROM SAVE     ");
    lcd.setCursor(0, 1);
    lcd.print("FAILED!!!!      ");
  }
  else if (Temp_Read_Upper >= Over_Temp_Trigger) {
    lcd.setCursor(0, 0);
    lcd.print("WARNING - HOT!  ");
    lcd.setCursor(0, 1);
    lcd.print("U");
    lcd.print(Temp_Read_Upper);
    lcd.print("F ");
    lcd.print("L");
    lcd.print(Temp_Read_Lower);
    lcd.print("F ");
  }
  else {
    lcd.setCursor(0, 0);
    lcd.print("Upper:");
    lcd.print(Temp_Read_Upper);
    lcd.print("F");
    lcd.setCursor(0, 1);
    lcd.print("Lower:");
    lcd.print(Temp_Read_Lower);
    lcd.print("F");
    if (Temp_Read_Upper > Temp_Trigger or Fan_Sw_Toggle_Last_State == 0) {
      lcd.setCursor(12, 0);
      lcd.print(" (*)");
      lcd.setCursor(12, 1);
      lcd.print(" (*)");
    }
    else if (Temp_Read_Lower > Temp_Trigger && Temp_Read_Upper < Temp_Trigger) {
      lcd.setCursor(12, 1);
      lcd.print(" (*)");
    }
    else {
      lcd.setCursor(12, 0);
      lcd.print(" (+)");
      lcd.setCursor(12, 1);
      lcd.print(" (+)");
    }
  }

//Tempature Relay Control
  if (Temp_Read_Upper > Temp_Trigger || Temp_Read_Lower > Temp_Trigger) {
    digitalWrite(Fan_Upper, HIGH);
    digitalWrite(Fan_Lower, HIGH);
    Fan_Timer = Cycle_Time;
  }
  else if (Fan_Sw_Toggle_Last_State == 1 && (Fan_Timer + Fan_Write_Delay) < Cycle_Time) {
    digitalWrite(Fan_Lower, LOW);
    digitalWrite(Fan_Upper, LOW);
  }
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

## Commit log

2020-04-03 First Commit
    Been working on this locally and though it would be a good idea to get
    it on the gits
    [1 to 1 Control Panel.SLDDRW, 4x8.SLDPRT, Arcade.SLDASM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]
2020-11-28 Post Assembly Update
    All CAD files have been updated with any changes and improvements that were made during construction/assembly.
    The Documentation includes PDFs of the revised version and the original drawings and PCB files.
    The PCB’s have been update with the future revisions that I would make if I was to make another arcade or update this one.
    All the revision notes can be found in the Documentation folder for the individual parts.
    [Arcade.SLDASM, Arcade.SLDDRW, Back.DXF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]
2020-11-29 Gerbers and STLs
    Adding Gerbers and STLs for easy of access.
    [Back.DXF, Back.STL, Bottom Lip.DXF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]
2020-12-10 AUX Control PCB Update
    Added a 4 pin header to the Aux Control PCB to add a remote 2x20 IC Screen for Status/ Cabinet Temp display.
    [PCB-AuxControl.brd, PCB-AuxControl.sch]
2020-12-23 BOM Update and Controls Update
    I added all the parts to the BOM that were used when I transistioned from a Pi3 to a Pi4 Build. Also I decided to change the IPAC config from keyboard to a gamepad, I configured Steamlink and it does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
    [Purchased Parts BOM.xlsx]
2021-01-06 Updated Auxiliary PCB Code
    Added functionality to utilize the 16x2 LCD
2021-04-09 New PCBs, Added R1 files to Archive and Updated Documentation
    Created a Archive folder and placed all R1 filesin it
    Updated all the file in the documentation folder including PCB PDFs, BOM, Overall Schetmatic
    Add the LCD Mount for the AUX control 2x20 Sxreen in the CAD Files Directory
    PCB Chages:
    3.5MM AUX Jack - Added PCB name/rev/date to the silkscreen
    AUX Control - Added a 4 pin molex header to enable LCD output
    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
    [Back.DXF, Back.STL, Bottom Lip.DXF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]
2021-12-28 Power Button PSB and Code, Blean up files and Update to Neopixels
    Added a PCB that acts as a intermediary to the power button allowing it
    to be controlled via HTTP calls (I use it for Smartthings). The code for
    the ESP and device handler for smartthings is also included. BOM
    Updated also
    Some files have been removed/renamed. and added a boot sequence to the
    neopixel control code.
    [Array Helper.xlsx, PCB BOMs.xlsx, Power Button.brd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]
2025-06-07 Added DXFs for R2 Version of Cabinet
    [Arcade.SLDASM, Back.DXF, Back.SLDPRT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]
2026-02-07 Updates
    Added T-Mold Callouts, Corrected material for monitor glass and added 2x switch plate to Drawing, Marked EOL components in BOM and Identified replacement. Still need to find a hinge replacement.
    [2X Panel Mount Switch Plate.SLDPRT, 2X Panel Mount Switch Plate.STL, 4X Panel Mount Switch Plate.STL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]

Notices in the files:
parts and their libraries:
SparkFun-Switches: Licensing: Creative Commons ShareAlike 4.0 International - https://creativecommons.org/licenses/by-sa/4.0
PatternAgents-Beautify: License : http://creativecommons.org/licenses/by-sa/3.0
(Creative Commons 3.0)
